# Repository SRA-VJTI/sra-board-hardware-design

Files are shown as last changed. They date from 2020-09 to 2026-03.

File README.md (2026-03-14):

<!-- PROJECT LOGO -->

[][stars-url]
[][forks-url]
[][issues-url]
[][license-url]

<br/>

<p align="center">
  <a href="https://github.com/SRA-VJTI/sraboard-hardware-design">
    
  </a>

  <h3 align="center">SRA Development Board</h3>
  <p align="center">
    ESP32-based Development Board
    <br />
    <a href="./sra_dev_board_2026">KiCAD</a>
    ·
    <a href="./gerber_sra_dev_board">Gerber</a>
    ·
    <a href="./documentation/images/board_images/front.png">Images</a>
    ·
    <a href="./3d_models/sra_board_model/sra_dev_board_2026.step">3D Model</a>
  </p>

# SRA Board 2026

The SRA board is a development board based on ESP32 with on-board peripherals like a programmable LED matrix, switches, sensor ports for Line Sensor Array and MPU-6050, protection circuit for over-current and reverse voltage, and motor drivers.

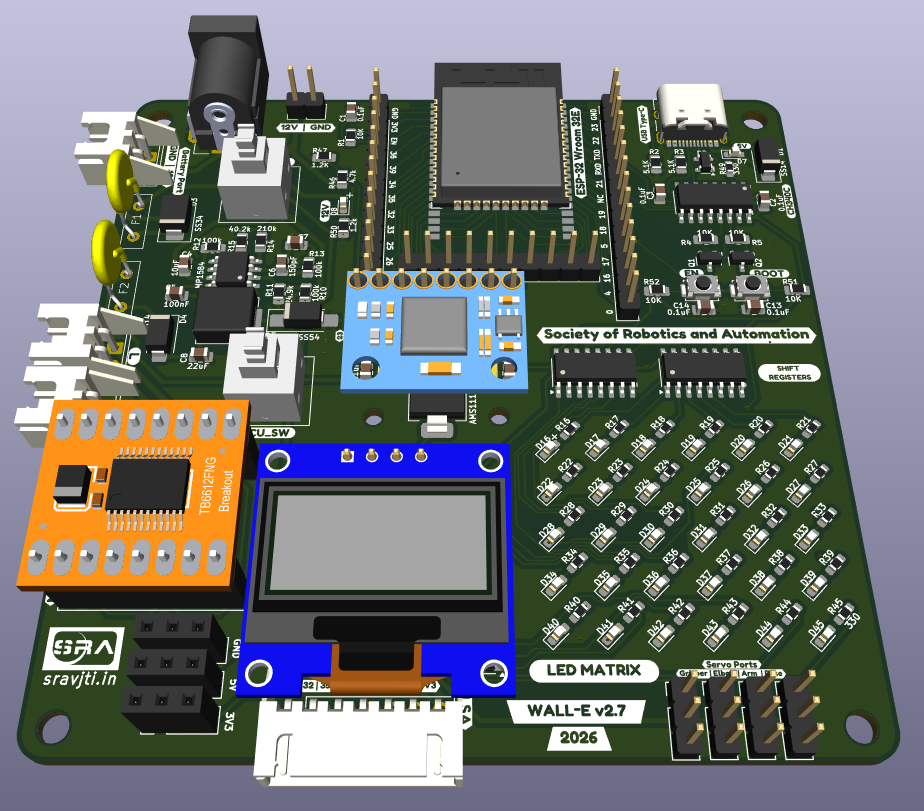
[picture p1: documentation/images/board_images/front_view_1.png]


## Table of Contents

- [SRA Board 2026](#sra-board-2026)
  - [Table of Contents](#table-of-contents)
  - [Board Images](#board-images)
  - [About the Project](#about-the-project)
  - [Getting Started with a Development Board](#getting-started-with-a-development-board)
  - [Notable problems in the current SRA Board](#notable-problems-in-the-current-sra-board)
  - [Improvements Suggested for Future Iterations](#improvements-suggested-for-future-iterations)
  - [Potential Future Enhancements](#potential-future-enhancements)
  - [3D Models](#3d-models)
  - [Milestones](#milestones)
  - [Contributors](#contributors)
  - [Acknowledgements and Resources](#acknowledgements-and-resources)
  - [License](#license)

## Board Images

- **Frontside**
<p align="center">
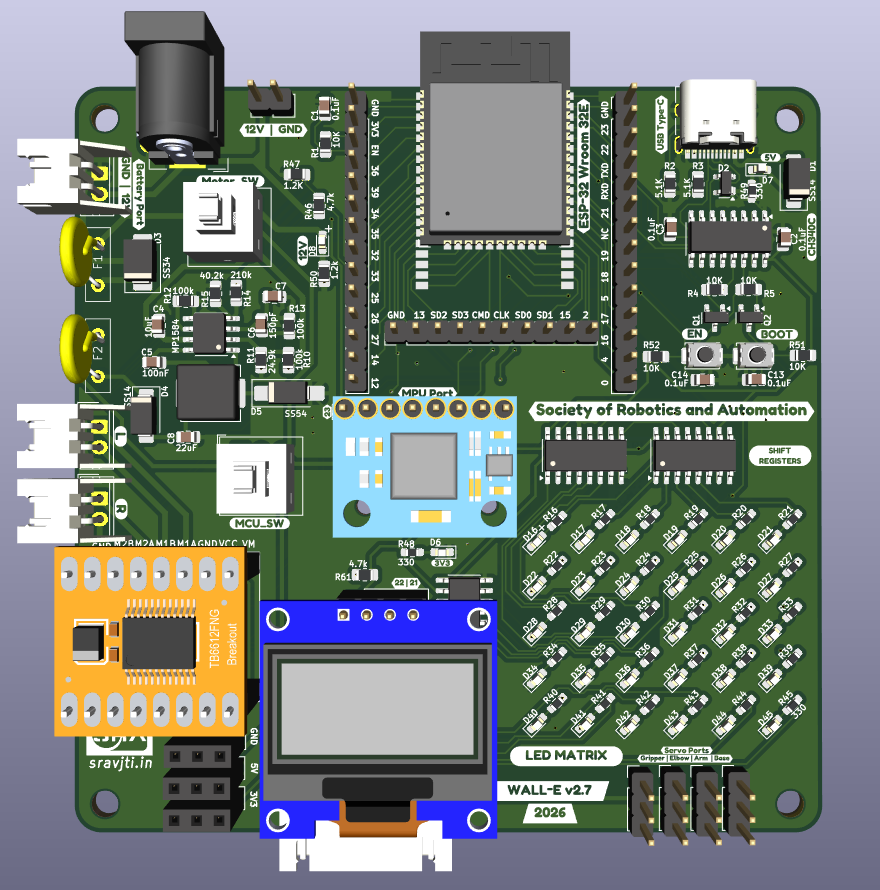
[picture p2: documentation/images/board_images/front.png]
  
</p>

- **Backside**
<p align="center">
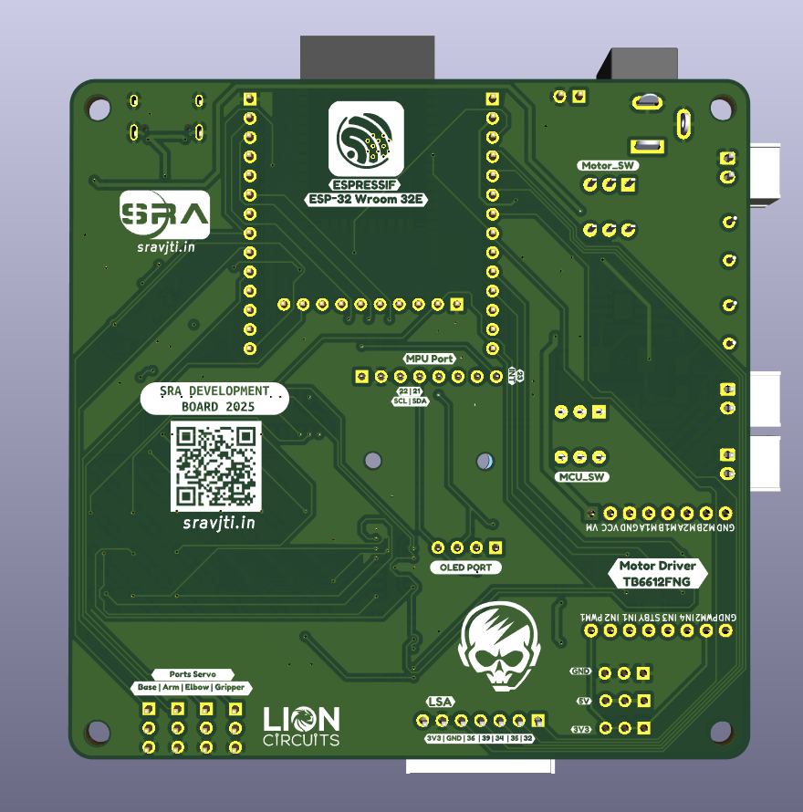
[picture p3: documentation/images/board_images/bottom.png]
  
</p>

## About the Project

- This development board is used for the [Wall-E](https://github.com/SRA-VJTI/Wall-E) and [MARIO](https://github.com/SRA-VJTI/MARIO) workshops conducted by [SRA](https://github.com/SRA-VJTI).
- Designed using KiCAD. The schematic and board files are [here](./sra_dev_board_2026).
- Resources for [previous work](https://github.com/SRA-VJTI/sra-board-hardware-design/tree/v2.5). For more details of the SRA board 2024, checkout this [link](https://github.com/SRA-VJTI/sra-board-hardware-design/releases/tag/v2.4).
- The SRA board 2023 images can be found [here](https://github.com/SRA-VJTI/sra-board-hardware-design/tree/v2.3/documentation/images).
- Older versions of the board and miscellaneous designs can be found [here](https://github.com/SRA-VJTI/PCB-Schematics-and-Layouts).

## Getting Started with a Development Board

<p align="center">
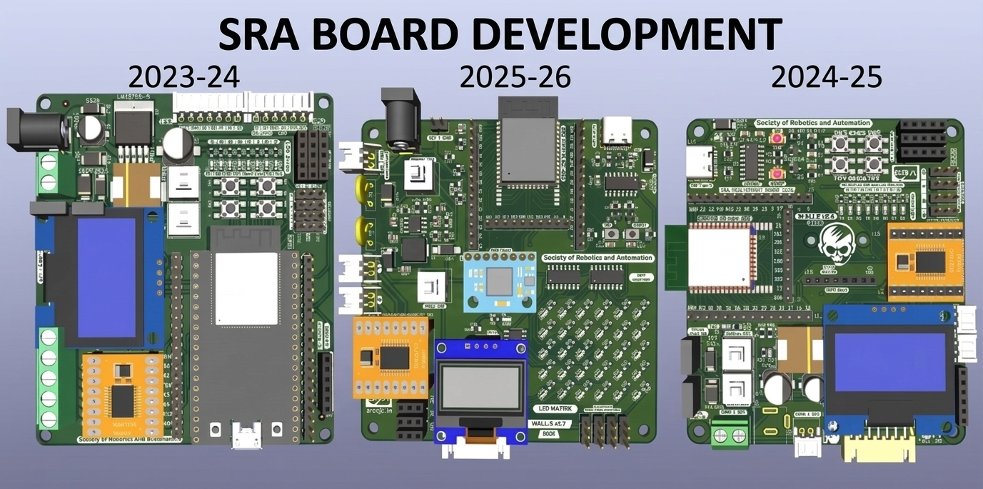
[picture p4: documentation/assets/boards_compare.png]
  
</p>

In general, every development board has the following basic features:

- ### Power Supply Unit
  - Microcontrollers (MCUs) usually run on 3.3V or 5V logic supply voltage while input to a development board is normally 12V for motor and driving/controlling peripheral devices.
  - So, in order to have a single input source, a _power_ section which inter converts this 12V to standard levels like 5V & 3.3V for MCU and sensors is present.This is achieved using a step-down [buck regulator](https://www.youtube.com/watch?v=m8rK9gU30v4).
  - Buck Regulator IC [MP1584](./datasheets/MP1584_buck.pdf) is used in the current SRA Board 2026 for stepping down the voltage from 12V to 5V DC. This 5V is further regulated to 3.3V using LDO IC [AMS1117-3.3](./datasheets/ams1117_ldo.pdf). The MP1584 is a more compact and efficient alternative compared to the previous LM2576-S.
  - The previous edition of the SRA board (2025) used the [LM2576-S-5](./datasheets/lm2576_buck_regulator.pdf) buck regulator, while earlier editions used the LM7805 linear voltage regulator for stepping down from 12V to 5V.
  - The older editions of the SRA board used the LD33 linear voltage regulator for converting 5V to 3.3V at the sensor port.

- ### Motor Driver
  - Motors usually run on 12V and MCU output is generally 5V/3.3V. So, an external motor driver circuitry is required to control motors according to the MCU input.
  - The current and previous editions of SRA board use the [TB6612FNG](./datasheets/TB6612FNG_motor_driver.pdf) Motor Driver, which is a MOS-based H-Bridge motor driver.
  - The older editions of SRA Board used the L298N IC for motor-control, which is a BJT-based H-Bridge motor driver.

- ### Sensor Port
  - According to the external sensor types, usually development boards have onboard sensor ports where the sensors can be connected easily. [LSA - Line Sensor Array]() and [MPU- Motion Processing Unit]() have on-board connection ports.
  - The current edition uses easily available and efficient [JST XH connectors](https://en.wikipedia.org/wiki/JST_connector).
  - Previous versions used bulky [FRC connectors](<https://www.sunrom.com/c/frc-idc-flat-cable-box-header#:~:text=FRC%20(Flat%20Ribon%20Cable)%20are,from%206%20to%2064%20pins.>)

- ### Protection against [Reverse Voltage](https://www.google.com/url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)
  - The SRA Boards use diodes for reverse voltage protection in the power-line.
  - 12V Motor line and power regulated line have been separated with [SS34](./datasheets/ss34_3A_schottky_diode.pdf) and [SS54](./datasheets/ss24_2A_schottky_diode.pdf) schottky diodes respectively.

- ### Protection against [Over Current](https://www.baypower.com/blog/what-is-overcurrent-protection/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,of%20a%20piece%20of%20equipment.)
  - Earlier, for the overcurrent protection of MCU and motor driver circuit, bulky glass fuses of 300mA and 3A were used respectively. After breakdown, they used to be replaced.
  - In the recent versions of the board, these were replaced with compact, PTC Resettable Fuses.
  - On 12V line - [RXEF160](./datasheets/RUEF160_3,2A_trip_ptc_fuse.pdf) : 1.6A hold current; 3.2A trip current Fuse was used.
  - On 5V line - [RXEF160](./datasheets/RXEF050_1A_trip_ptc_fuse.pdf) : 0.5A hold current; 1A trip current Fuse was used.
- ### Programmable Switches and LEDs
  - Every development board should have some programmable switches and LEDs for testing, control and debugging purposes.
  - The current SRA Board 2026 features a 6x5 LED matrix (30 LEDs total) controlled via shift registers, which provides enhanced debugging capabilities and expressive visual feedback while reducing GPIO usage compared to discrete LEDs.
  - The previous edition (2025) had an array of 8 programmable discrete LEDs and switches.
  - The earlier editions had fewer programmable switches and LEDs for testing and control purposes.

- ### Power Switch
  - All versions have a power switch for the motor driver, using which power supply to the motor driver can be toggled. Similarly, there was a switch for the ESP32 MCU.

> Now that we covered basics of development boards, let us talk about the changes made in the new design.

## Changes IN SRA Board Over the years from 2024-2026

| Feature | SRA Board 2024 | SRA Board 2025 | SRA Board 2026 |
| :---: | :---: | :---: | :---: |
| 12V to 5V | LM2576-S Buck Converter | LM2576-S Buck Converter | MP1584 Buck Converter |
|  Reverse Voltage Protection | Diodes | Diodes | Diodes |
| Line Sensing Arrays (LSA) | IR Sensors | IR Sensors | IR Sensors |
| Number of LSA Sensors | 5 | 5 | 5 |
| Motor Driver | TB6612FNG | TB6612FNG | TB6612FNG |
| Stepper Motor Driver | - | - | - |
| No. of DC Motor Channels | 2 | 2 | 2 |
| No. of Stepper Motor Channels | 0 | 0 | 0 |
| No. of Switches | 2 | 2 | 2 |
| No. of LEDs | 8 | 8 | 6x5 LED Matrix (via Shift Registers) |
| Over Current Protection | PTC Resettable Fuses | PTC Resettable Fuses | PTC Resettable Fuses |
| Sensor Port Connectors | JST Connectors | JST Connectors | JST Connectors |
| Component Type and Board Size | SMD(Surface Mount Device), Smaller | SMD(Surface Mount Device), Smaller |  SMD(Surface Mount Device), Smaller  |
| ESP32 Module | Not Integrated | Mounted and Soldered to PCB | Mounted and Soldered to PCB |
| Flashing Port | Micro USB | Type-C | Type-C |

- ### **Compatiblity of SRA Board with Battery [3- 3.3V 2500mAh Batteries](https://robu.in/product/bak-nmc-18650-2500mah-8c-lithium-ion-battery/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)**
  - The SRA Board is compatible with **3-cell (3S) Lithium-ion battery packs** which use an external **[BMS (Battery Management System)](https://robu.in/product/3s-10a-12v-18650-lithium-battery-charger-board-protection-module/)**.
  - The BMS helps maintain safe operating voltages and disconnects the battery when the voltage drops below a safe limit.
  - It also ensures balanced charging and discharging of the three cells, improving the overall health and lifetime of the battery pack.

- ### **7805 (5V linear regulator) to [LM2576/96 Buck Convertor](https://www.youtube.com/watch?v=m8rK9gU30v4)**
  - The higher efficiency, output current capability and reliability of LM2576/96 were the primary reasons for this change.
  - The efficiency of LM2576 can reach up to **~92%**, which is significantly better than the 7805 linear regulator.
  - The LM2576 can provide currents up to **3A**, allowing peripherals such as the MARIO workshop manipulator to be powered using the onboard regulator.

- ### **LD33 (3.3V) to [AMS1117](http://www.advanced-monolithic.com/pdf/ams1117.pdf)**:
  - Older editions used the **LD33 IC** to step down from 5V to 3.3V.
  - This was later replaced with the **AMS1117-3.3 LDO**, which is more compact and widely used for stable 3.3V regulation.
  - (_AMS1117 is also used on the ESP32-DevKitC V4 module._)

- ### **Reverse voltage protection: Diodes to P-MOSFET**
  - Diodes placed in series with the power line introduce voltage drop and power loss compared to a **P-MOSFET based protection circuit**.
  - Due to the higher current requirements of the motors, managing diode size and current rating became difficult.
  - Therefore, earlier versions used a **P-MOSFET based reverse polarity protection circuit**, which is more efficient and can handle higher currents.
  - In the current edition, **SMD Schottky diodes** are used, making size and rating less of an issue.

- ### **Component Type and Board Size**:
  - In the previous editions, THT/PTH (Through-Hole) components were used, which occupied more board area and increased in size with higher power ratings.
  - In the current edition, the design adopts a more compact SMD-based layout. The LM2576 buck converter has been replaced with the smaller MP1584 regulator, and the discrete LED array has been replaced with a 6×5 LED matrix driven using shift registers.
  - Current Board Dimensions: **90mm x 90mm**

- ### **L298N vs [TB6612FNG](https://dronebotworkshop.com/tb6612fng-h-bridge/)**
  - L298N is a BJT-based H-bridge motor driver but it is less efficient as compared to the new MOS-based TB6612FNG.
  - The detailed comparison is shown below. As you can see the efficiency of TB6612FNG can reach up to 91-95% which is significantly higher than the 40-70% efficiency of L298N.
  - The only drawback of TB6612FNG is the less continuous current which is equal to 1.2A.
    <p align="center">
        
    </p>

- ### **LED System**

  - Earlier versions of the board used a set of discrete programmable LEDs for debugging and status indication. In the SRA Board 2026, this has been replaced with a **6×5 LED matrix driven using shift registers**.  
  - This significantly reduces GPIO usage while allowing more flexible visual debugging and status indication patterns.

## Notable problems in the current SRA Board

- ### **Buck Converter Stability Issue (MP1584)**
  - The SRA Board 2026 uses the **MP1584 buck converter** to step down 12V to 5V.
  - While the device allowed a significant reduction in the power section size compared to LM2576, irregular behaviour was observed under **higher load conditions**.
  - During heavy load scenarios involving motors and other peripherals, the **5V rail occasionally showed instability**, which may affect the overall system reliability.

- ### **USB Type-C Connector Mechanical Strength Issue**
  - The board currently uses a **16-pin USB Type-C connector** for programming and power.
  - In practical usage, the connector was found to be **mechanically weak**, and in some cases it could loosen or detach from the PCB after repeated cable insertion or mechanical stress.

- ### **Power Switch Issue**
  - There are two dpdt power toggle switch used on board. One to toggle the supply of 12v to the whole board and one to toggle the supply of 5v to the logic circuit.
  - Instead it should have been toggling 12v supply to the motors and toggling 12v supply to the whole board.

## Improvements Suggested for Future Iterations

Based on the current design of the SRA Board 2026, the following improvements are recommended for future iterations:

- **Replace MP1584 with TPS562202**: The TPS562202 offers improved reliability and enhanced long-term robustness compared to the current MP1584 buck converter. This component provides better thermal performance and more stable regulation across varying load conditions.

- **Upgrade to USB-C 6P Connector**: Replace the current Type-C connector with a robust USB-C 6P connector configuration. This simplifies soldering procedures, improves mechanical strength, and enhances durability during repeated connection cycles.

- **Add Unconnected UART Solder Pads (RX, TX)**: Incorporate unconnected solder pads for UART receive and transmit lines on the PCB. This allows the board to optionally function as a USB-to-TTL interface, extending its utility beyond standalone development applications.

## Potential Future Enhancements

The following experimental features and enhancements are being considered for future versions of the SRA Board but are not yet integrated into the 2026 iteration:

- **Onboard IMU Integration**: Direct integration of an Inertial Measurement Unit (IMU) for advanced motion sensing applications, eliminating the need for external MPU6050 connections.

- **Camera FFC/FPC Connector**: Addition of a Flat Flex Cable (FFC) or Flexible Printed Circuit (FPC) connector to support camera modules, enabling vision-based robotics projects and computer vision applications.

- **Integrated Motor Driver**: Direct onboarding of motor driver circuits instead of requiring external TB6612FNG modules, reducing component count and improving form factor.

- **CH340 to CP2102 Upgrade**: Replacing the CH340 USB-to-UART bridge with CP2102 for improved reliability, driver support across multiple operating systems, and better stability in industrial environments.

These enhancements represent opportunities for evolution of the platform and will be explored as future iterations of the board are developed.

## 3D Models

1. The complete 3D model (.step) file of [SRA Board 2026](./3d_models/sra_board_model/sra_dev_board_2026.step)
2. The 3D models of motor driver, LEDs, ESP32 etc.: [3d models of other components](./3d_models/)

<!-- Milestone -->

## Milestones

- [x] Designing of the prototype board
- [x] Modular testing of the circuit
- [x] Testing of prototype board
- [x] Final version
- [x] Making the board Battery Compatible
- [x] Onboard ESP32 Module

<!-- CONTRIBUTORS -->

## Contributors

- [Vishal Mutha](https://github.com/Vishal-Mutha): _Designer_
- [Atharva Atre](https://github.com/AtharvaAtre): _Mentor_
<!-- ACKNOWLEDGEMENTS AND REFERENCES -->

## Acknowledgements and Resources

- Previous Edition: [SRA Board 2025](https://github.com/SRA-VJTI/sra-board-hardware-design/releases/tag/v2.5)
- [KiCAD Tutorials](https://www.youtube.com/playlist?list=PL3bNyZYHcRSUhUXUt51W6nKvxx2ORvUQB)
- [README Template](https://github.com/roshanlam/ReadMeTemplate) by [roshanlam](https://github.com/roshanlam)

## License

- Distributed under the [MIT License](https://github.com/SRA-VJTI/sraboard-hardware-design/blob/master/LICENSE).

[forks-shield]: https://img.shields.io/github/forks/SRA-VJTI/sra-board-hardware-design
[forks-url]: https://github.com/SRA-VJTI/sra-board-hardware-design/network/members
[stars-shield]: https://img.shields.io/github/stars/SRA-VJTI/sra-board-hardware-design
[stars-url]: https://github.com/SRA-VJTI/sra-board-hardware-design/stargazers
[issues-shield]: https://img.shields.io/github/issues/SRA-VJTI/sra-board-hardware-design
[issues-url]: https://github.com/SRA-VJTI/sra-board-hardware-design/issues
[license-shield]: https://img.shields.io/github/license/SRA-VJTI/sra-board-hardware-design
[license-url]: https://github.com/SRA-VJTI/sra-board-hardware-design/blob/master/LICENSE

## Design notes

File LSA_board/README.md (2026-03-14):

## LSA - Line Sensor Array

### Table of Contents
* [Overview](#overview)
* [Features](#features)
* [Components of LSA](#components-of-lsa)
* [Function of Components](#function-of-components)
	* [LED](#function-of-components)
	* [PhotoDiode](#function-of-components)
	* [IC LM324](#function-of-components)
	* [Resistors](#function-of-components)
* [Connections](#connections)
* [Working Principle](#working-principle)
* [Appplications](#applications)
* [Scope of Improvement](#scope-of-improvement)

### Overview
- The Line Sensor Array(LSA) is used to detect the white/black lined surface and it sends this data to the microcontroller ESP-32. Analyzing and processing the data received by the microcontroller ESP-32, the purpose of line following is achieved.

- Physical PCB
<p align="center">
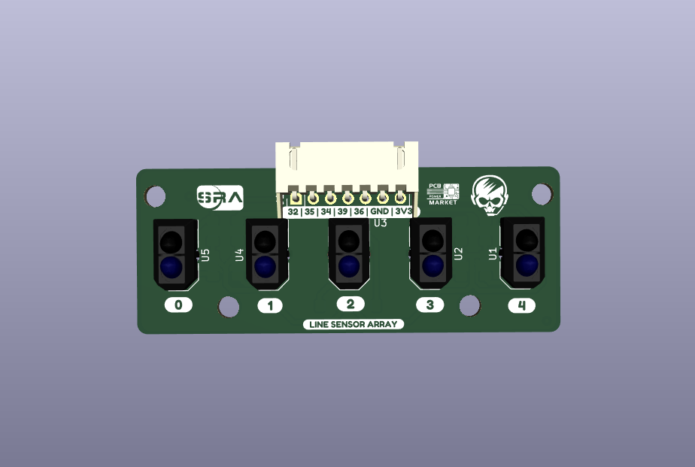
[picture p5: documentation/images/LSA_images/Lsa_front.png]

</p>

- PCB Backside
<p align="center">
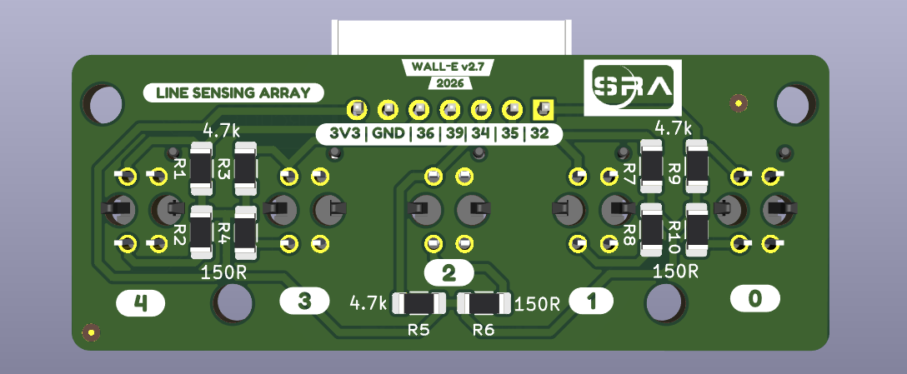
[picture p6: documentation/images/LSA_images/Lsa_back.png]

</p>

### Features
* Components used are readily available.
* Easy connections for output signals.
* Compact enough to fit into any project.
* Distinguished trace widths for Signal and Power Routes.

### Components of LSA
| Component | Description | Quantity |
| --- | --- | --- |
| Infrared Emmitter | Emits infrared light |  5 |
| PhotoTransistor  | Absorbs light |  5 |
| Resistors | Limit Current |  10 |
|JST Connector | Connect PCB with other circuits|1|

### Function of Components
- **Infrared Emmitter**
	- The specific Infrared Emmitter emit infrared light which is incident on the surface and some of it is absorbed by the surface. The voltage source for the Infrared Emmitter to emit is VCC.

- **PhotoTransistor**
	- Based upon the reflectivity coefficient of the surface( generally less than 1), the remaining light reflected from the surface is captured by the Photodiodes. Infrared Emmitter and complimentary phototransistor are used to efficiently detect the surface (white/black line). The amount of light received is directly proportional to the current generated by it. More the light, more the current, more the reading.

- **Resistors**
	- Now to limit the current and thus to protect the LEDs, PhotoDiodes current limiting resistors are used.

### Connections
To connect LSA with the SRA Board, connect the JST connector in the following way:
<p align="center">
 
</p>

### Working Principle
- LSA works on the principle of reflectivity of light for different types of surfaces.
	- Black Surface -> HIGH absorptivity -> LESS reflectivity
	- White Surface -> LOW absorptivity -> HIGH reflectivity
- Demonstration
<p align="center">
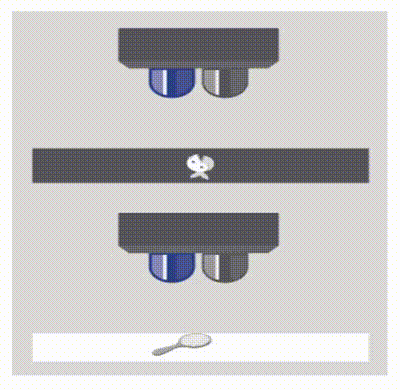
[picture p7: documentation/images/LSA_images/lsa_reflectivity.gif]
 
</p>

### Applications
* Obstacle detection on a clear path.
* Line Following.
* Distinguish Colours on a path.

### Scope of Improvement
- LSA sometimes provides slightly inaccurate readings due to external light and conditions due to non uniformity of the colour of the path. Therefore, LSA has low accuracy. Hence LSA should be kept close to the ground.
- As of now only white and black surfaces are being mapped. Given accurate sensors and proper mapping we can map LSA for any range of RGB colours.

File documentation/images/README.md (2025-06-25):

# SRA Board 2022: Images

## Schematic image

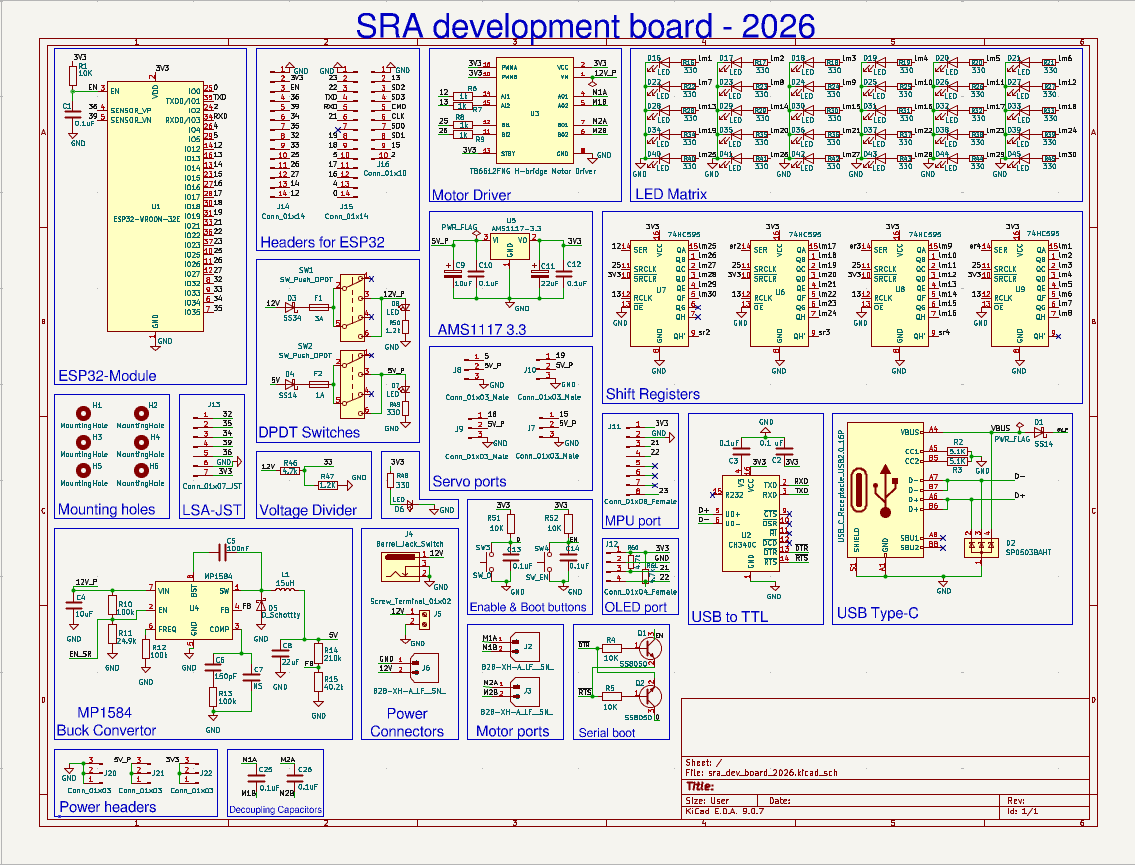
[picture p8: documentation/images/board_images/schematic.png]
Schematic


## Top Silkscreen

<p align="center">
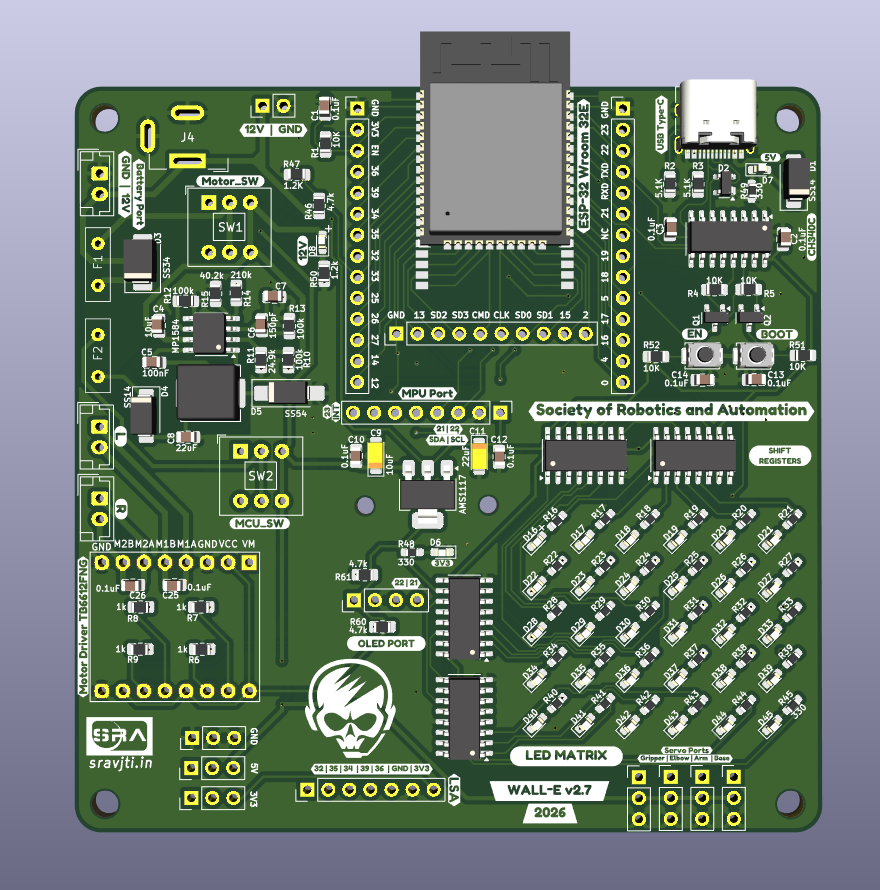
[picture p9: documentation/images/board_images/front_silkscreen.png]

</p>

## Bottom Silkscreen

<p align="center">
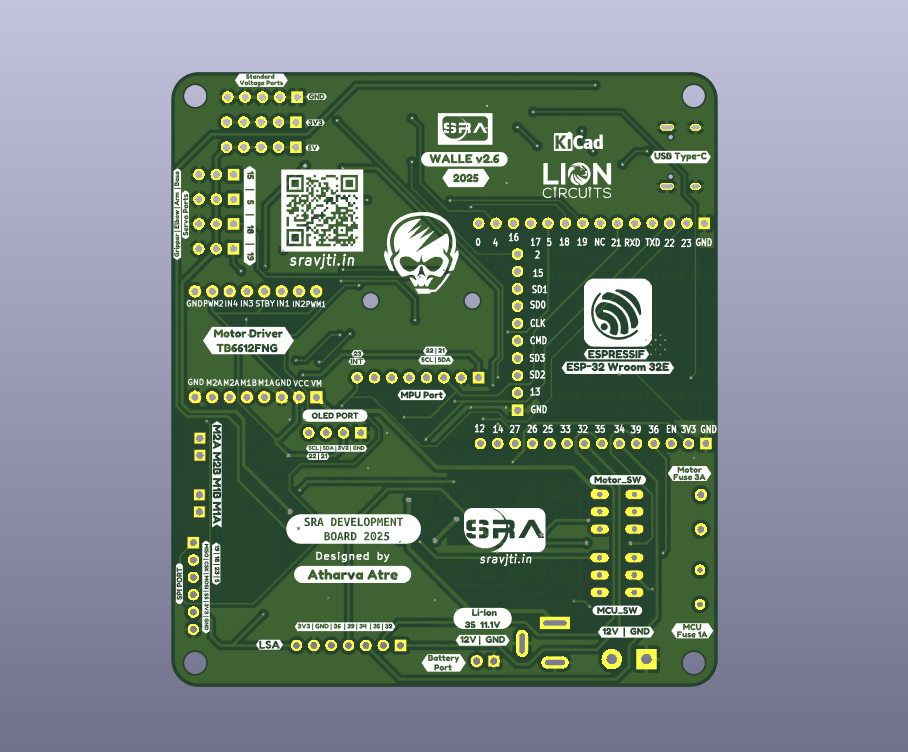
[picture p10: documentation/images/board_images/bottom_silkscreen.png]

</p>

## Top Layer

<p align="center">
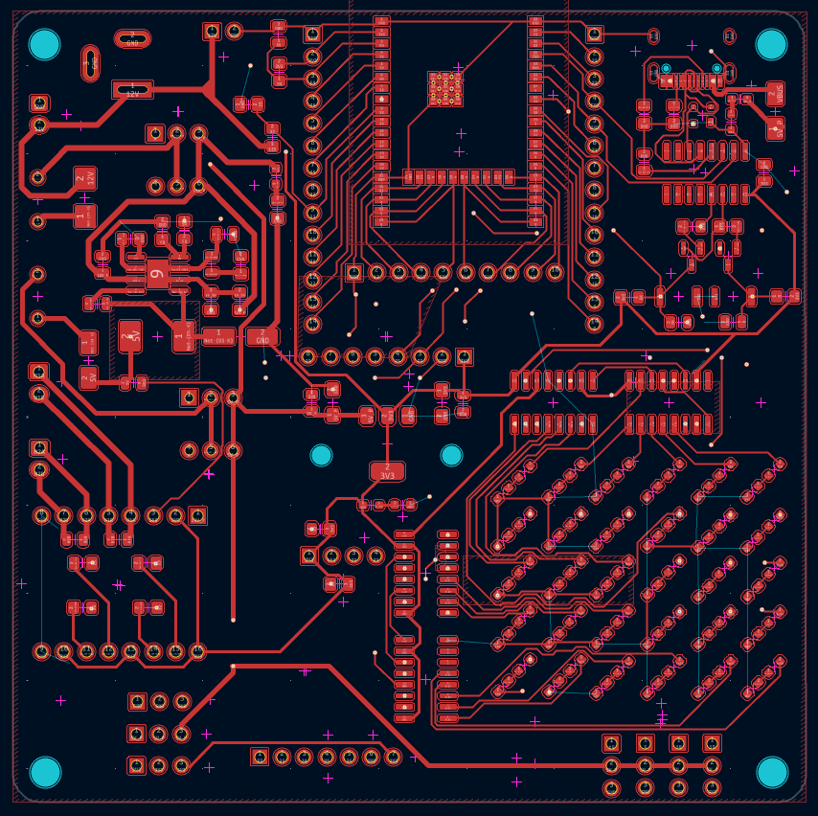
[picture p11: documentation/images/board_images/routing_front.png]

</p>

## Bottom Layer

<p align="center">
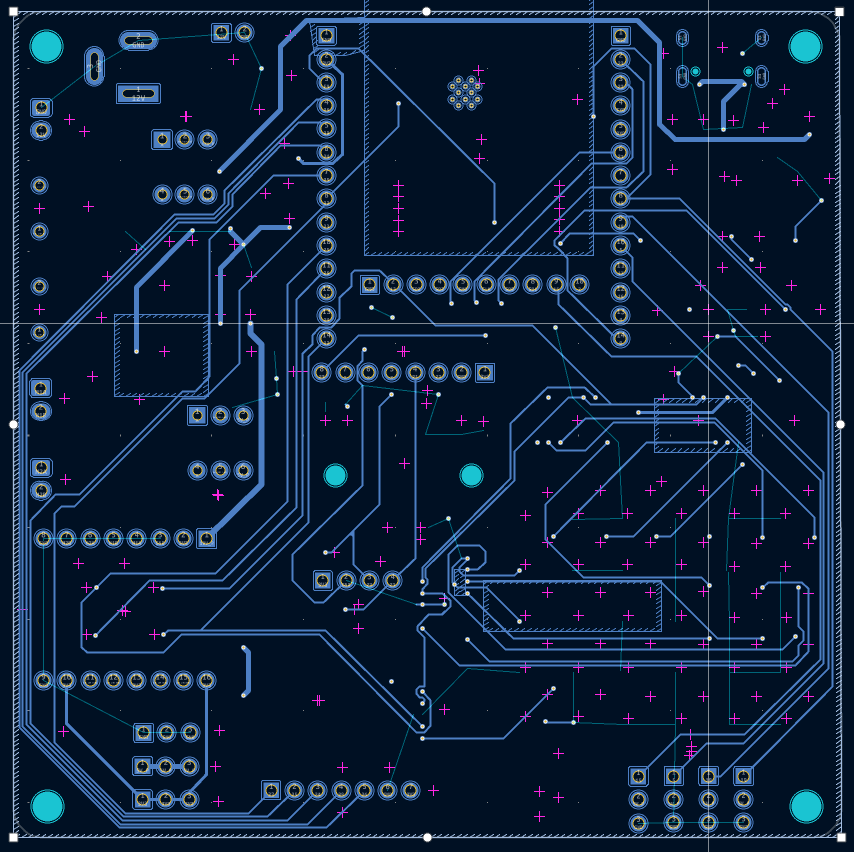
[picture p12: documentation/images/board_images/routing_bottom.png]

</p>

## Both Layers

<p align="center">
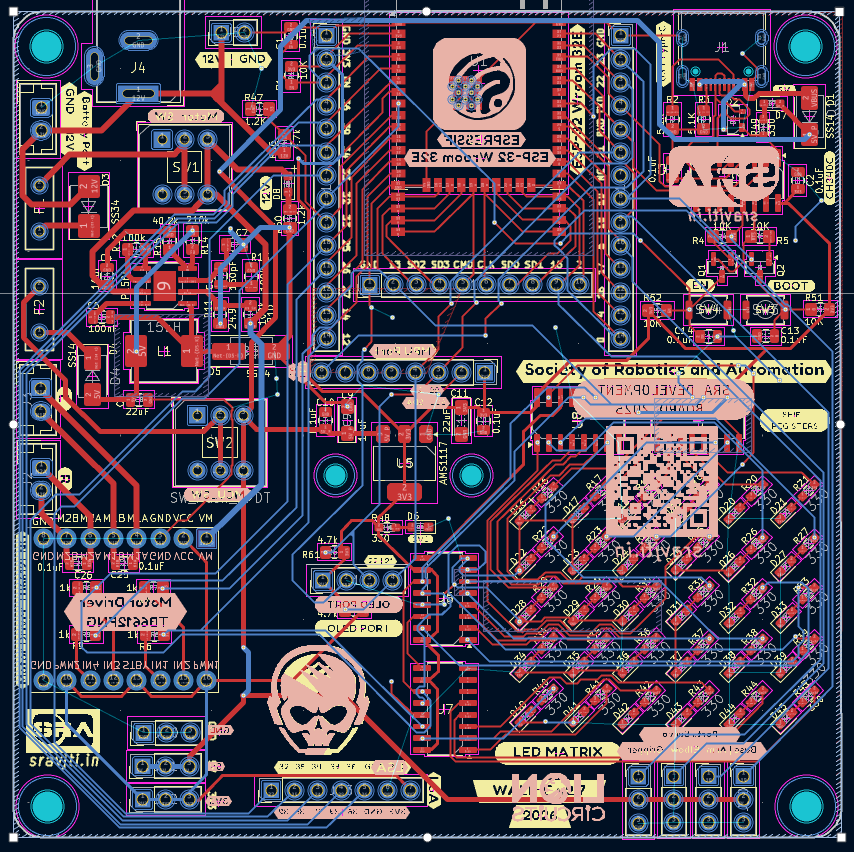
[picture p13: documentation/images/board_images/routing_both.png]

</p>

## Front

<p align="center">

</p>

<p align="center">
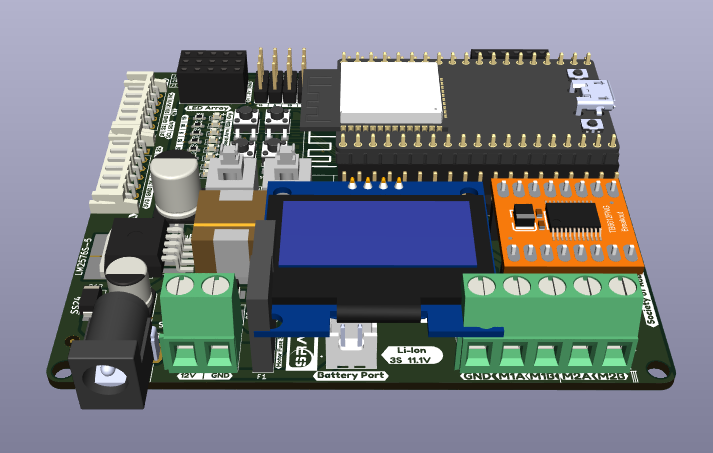
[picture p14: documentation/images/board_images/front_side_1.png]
front_side_1
    
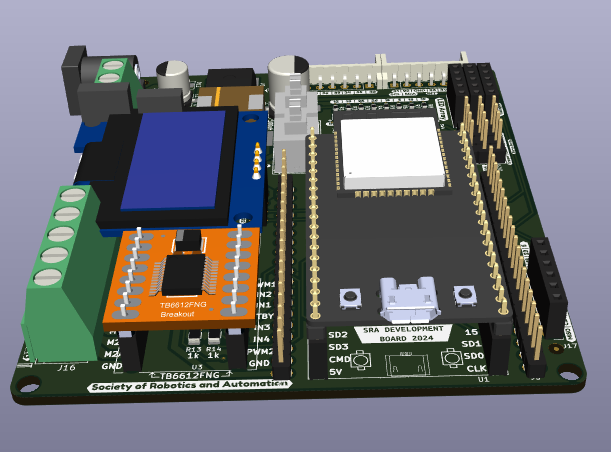
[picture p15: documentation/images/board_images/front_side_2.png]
front_side_2
    
</div> 

### 3d View

<p align="center">
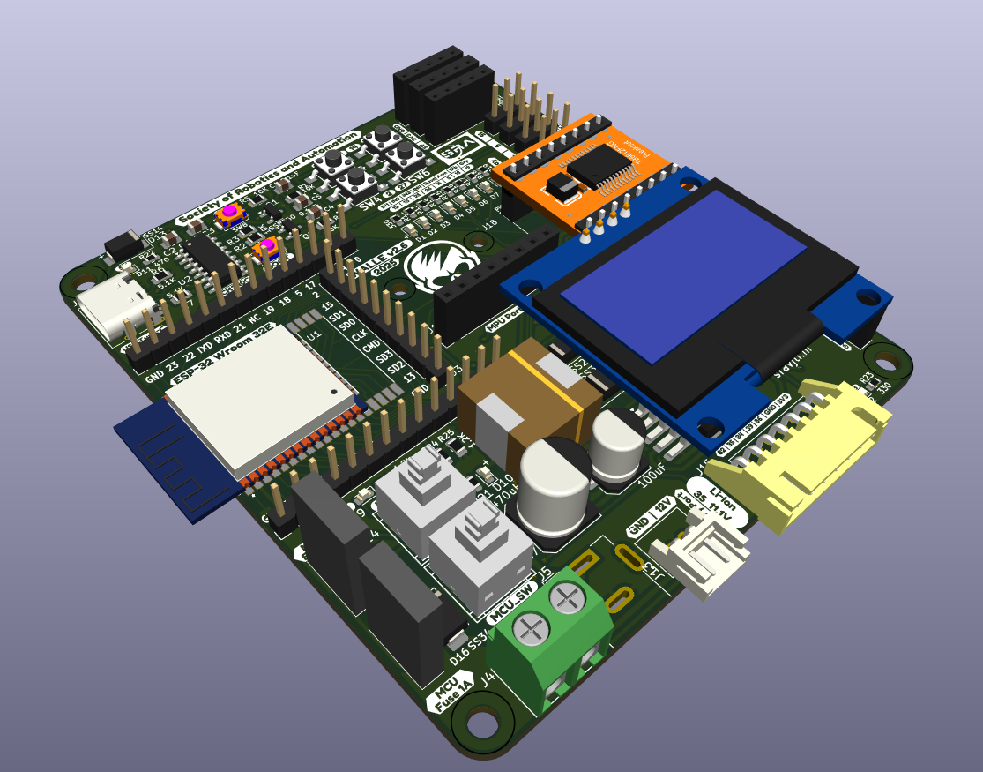
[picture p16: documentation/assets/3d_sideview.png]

</p>

### Bottom View

<p align="center">

</p>

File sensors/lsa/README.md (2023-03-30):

## LSA - Line Sensor Array

### Table of Contents
* [Overview](#overview)
* [Features](#features)
* [Components of LSA](#components-of-lsa)
* [Function of Components](#function-of-components)
	* [LED](#function-of-components)
	* [PhotoDiode](#function-of-components)
	* [IC LM324](#function-of-components)
	* [Resistors](#function-of-components)
* [Connections](#connections)
* [Working Principle](#working-principle)
* [Appplications](#applications)
* [Scope of Improvement](#scope-of-improvement)

### Overview
- The Line Sensor Array(LSA) is used to detect the white/black lined surface and it sends this data to the microcontroller ESP-32. Analyzing and processing the data received by the microcontroller ESP-32, the purpose of line following is achieved.

- Physical PCB
<p align="center">

</p>

<p align="center">
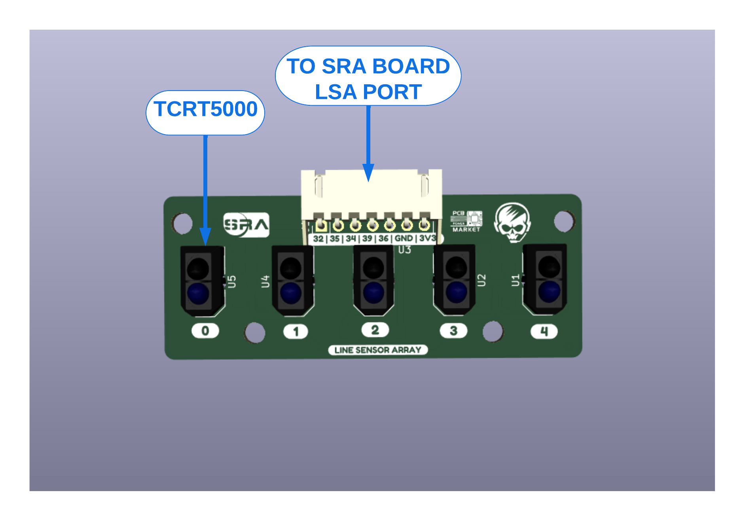
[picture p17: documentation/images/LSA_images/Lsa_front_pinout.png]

</p>

- PCB Backside
<p align="center">

</p>

<p align="center">
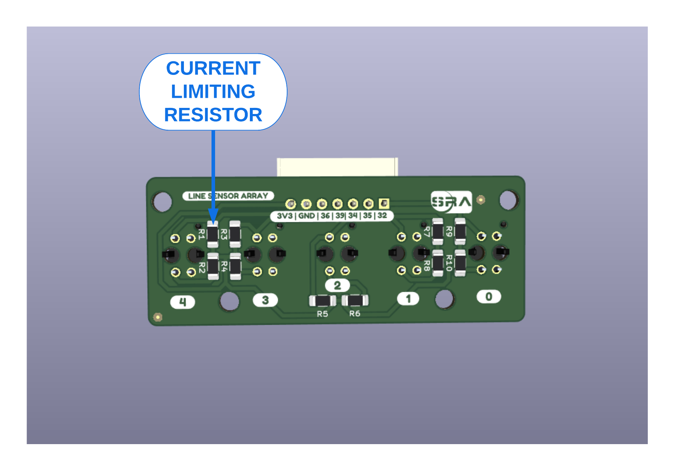
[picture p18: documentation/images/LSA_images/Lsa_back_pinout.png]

</p>

### Features
* Components used are readily available.
* Easy connections for output signals.
* Compact enough to fit into any project.
* Distinguished trace widths for Signal and Power Routes.

### Components of LSA
| Component | Description | Quantity |
| --- | --- | --- |
| Infrared Emmitter | Emits infrared light |  5 |
| PhotoTransistor  | Absorbs light |  5 |
| Resistors | Limit Current |  10 |
|JST Connector | Connect PCB with other circuits|1|

### Function of Components
- **Infrared Emmitter**
	- The specific Infrared Emmitter emit infrared light which is incident on the surface and some of it is absorbed by the surface. The voltage source for the Infrared Emmitter to emit is VCC.

- **PhotoTransistor**
	- Based upon the reflectivity coefficient of the surface( generally less than 1), the remaining light reflected from the surface is captured by the Photodiodes. Infrared Emmitter and complimentary phototransistor are used to efficiently detect the surface (white/black line). The amount of light received is directly proportional to the current generated by it. More the light, more the current, more the reading.

- **Resistors**
	- Now to limit the current and thus to protect the LEDs, PhotoDiodes current limiting resistors are used.

### Connections
To connect LSA with the SRA Board, connect the JST connector in the following way:
<p align="center">
 
</p>

### Working Principle
- LSA works on the principle of reflectivity of light for different types of surfaces.
	- Black Surface -> HIGH absorptivity -> LESS reflectivity
	- White Surface -> LOW absorptivity -> HIGH reflectivity
- Demonstration
<p align="center">
 
</p>

### Applications
* Obstacle detection on a clear path.
* Line Following.
* Distinguish Colours on a path.

### Scope of Improvement
- LSA sometimes provides slightly inaccurate readings due to external light and conditions due to non uniformity of the colour of the path. Therefore, LSA has low accuracy. Hence LSA should be kept close to the ground.
- As of now only white and black surfaces are being mapped. Given accurate sensors and proper mapping we can map LSA for any range of RGB colours.

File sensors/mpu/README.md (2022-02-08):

# TABLE OF CONTENTS
- [TABLE OF CONTENTS](#table-of-contents)
- [MPU6050](#mpu6050)
- [Connection with SRA Board](#connection-with-sra-board)
- [Inertial Measurement Unit](#inertial-measurement-unit)
- [Initialising MPU6050](#initialising-mpu6050)
  - [Gyroscope](#gyroscope)
  - [Reading Gyroscope Data](#reading-gyroscope-data)
  - [Accelerometer](#accelerometer)
  - [Reading Accelerometer Data](#reading-accelerometer-data)
  - [Accelerometer Euler Angles](#accelerometer-euler-angles)
  - [Complementary Filter](#complementary-filter)
  - [Digital Motion Processor](#digital-motion-processor-dmp)
  - [Reading Register Data](#reading-register-data)

# Connection with SRA Board
PNG image

# MPU6050
- The MPU6050 is a **6-axis/6-DOF Motion Tracking Device**.
- It is a *Micro Electro-Mechanical System (MEMS)*.
> MEMS is a technology defined as miniaturized mechanical and electro-mechanical elements (i.e., devices and structures) that are made using the techniques of microfabrication.
> Their dimensions can range from one micron to several millimeters.
- The 6050 has both a 3-axis Accelerometer and 3-axis Gyroscope integrated on a single chip.
- It is a commonly used chip that combines a MEMS gyroscope and a MEMS accelerometer and uses a standard I2C bus for data transmission
- The system processor is an I2C master to the MPU6050 (default address is 0x68 but can be changed to 0x69)
- The MPU6050 can also act as an I2C master and directly accept inputs from an external compass
- This is 3.3V device and hence is safe to connect to ESP32 pins directly.

MPU6050

To give you some context:
> A Gyroscope is a device that measures the rate of change of angular position, aka the rotational velocity, over time in all 3 axes.

>An accelerometer is a tool that measures acceleration in its own instantaneous rest frame(e.g. an accelerometer at rest on the surface of the Earth will measure an acceleration due to Earth's gravity, straight upwards of g ≈ 9.81 m/s<sup>2</sup> and will measure zero acceleration when in freefall)

- When the 6050 is used, it returns 6 values; 3 from the accelerometer and the other 3 from the gyroscope.

# Inertial Measurement Unit

- These are small devices indicating changing orientation in smartphones, video game remotes, quadcopters, etc.
- The IMU has both a gyroscope which measures angular rate and an accelerometer which measures linear acceleration, and/or compasses (magnetometers)
- The number of sensor inputs in an IMU are referred to as ‘DoF’ (Degrees of Freedom), so a chip with a 3-axis gyroscope and a 3-axis accelerometer would be a 6-DOF IMU.

# Contents
- MPU6050 includes **Digital Motion Processor (DMP)**, which has property to solve complex calculations.
- It also consists of a 16-bit Analog to Digital Converter(ADC) hardware. This enables it to record 3-dimension motion at the same time.
- It has **I2C bus interface** to communicate with various microcontrollers.
- The main feature is that the MPU6050 is less expensive and that it can easily combine with accelerometer and gyroscope.

### Pins

Pins

The MPU-6050 module has 8 pins,

<code>VCC</code>: Power supply pin. Connect this pin to +5V DC supply.

<code>GND</code>: Ground pin. Connect this pin to ground connection.

<code>SCL</code>: Serial Clock pin. Connect this pin to the microcontroller's SCL pin.

<code>SDA</code>: Serial Data pin. Connect this pin to the microcontroller's SDA pin.

<code>XDA</code>: Auxiliary Serial Data pin. This pin is used to connect other I2C interface enabled sensors' SDA pin to MPU-6050.

<code>XCL</code>: Auxiliary Serial Clock pin. This pin is used to connect other I2C interface enabled sensors' SCL pin to MPU-6050.

<code>AD0</code>: I2C Slave Address LSB pin. This is 0th bit in 7-bit slave address of device. If connected to VCC, then read as logic one and slave address changes.

<code>INT</code>: Interrupt digital output pin.

---------
# Working of the 6050

## Initialising MPU6050

- A sample wiring of the device to ESP32 looks as follows:



- When powered up, MPU6050 will start in SLEEP mode. To use it, we need to first disable this SLEEP mode 
- To use the I2C protocol, we send the value 0 to register PWR_MGMT_1 (0x6b)
- The procedure to do so is as follows :
   1. Send a start sequence
   2. Send the I2C address (0x68) of the MPU6050 with the R/W bit high
   3. Send the internal register number you want to write to (0x6b : PWR_MGMT_1)
   4. Send the data byte (0x00) - This will power on the device
   5. Send the stop sequence



 The data byte 0x00 sets all the bits of register 107 to 0, thus disabling SLEEP mode and CYCLE mode, and powering on the MPU-6050 



There are various terms related with the Pulse Width Modulation:- 
- **Off-Time** :- Duration of time period when the signal is low.
- **ON-Time**  :- Duration of time period when the signal is high.
- **Duty cycle** :- It is the percentage of the time period when the signal remains ON during the period of the pulse width modulation signal.
- **Period** :- It is the sum of off-time and on-time of pulse width modulation signal.

### Gyroscope

- When the gyros are rotated about any of the sense axes, the C*oriolis Effect* causes a vibration that is detected by a MEM inside MPU6050.

- The resulting signal is amplified, demodulated, and filtered to produce a voltage that is proportional to the angular rate.

-  This voltage is digitized using 16-bit ADC to sample each axis.

-  The full-scale range of output are **+/- 250, +/- 500, +/- 1000, +/- 2000.**

-  It measures the angular velocity along each axis in *degree per second* units.

### Reading Gyroscope Data

- The acceleration of the three axes, X,Y and Z, are stored in 3 pairs of registers on the MPU6050
- Each register on the MPU6050 is an 8-bit register
- In each of these pairs, one register stores the MSB (most significant bit) and the other stores the LSB (least significant bit)
- These 6 registers are [burst-read](#reading-register-data) and the 8-bit MSB and LSB bytes for each axis are combined to give a single 16-bit float
- The gyroscope has a sensitivity factor of about 131, i.e. 1 degree of rotation gives a reading of 131 units
- Therefore, the degrees of rotation are obtained by dividing the raw readings by 131 
- Euler angles are calculated by integrating raw readings of each axis over time



### Accelerometer
Tilt

Accelerometer
- The MPU6050 uses a MEMS accelerometer, which consists of stationary and movable electrodes acting as **capacitor plates**
- Acceleration along the axes deflects the movable mass. It produces change in g-forces on the moving device, which causes displacement of the movable capacitor plates.
-  This displacement of moving plate (mass) unbalances the differential capacitor, which causes a change in the capacitance, which is then detected internally by change in voltage. This in turn results in sensor output. Output amplitude is proportional to acceleration.
-  16-bit ADC is used to get digitized output.
-  The full-scale range of acceleration are **+/- 2g, +/- 4g, +/- 8g, +/- 16g.**
-  It is measured in *g (gravity force)* unit; for example when the device is placed on a flat surface, it will measure 0g on X and Y axes and +1g on Z axis.

### Reading Accelerometer Data

- The acceleration of the three axes, X,Y and Z, are stored in 3 pairs of registers on the MPU6050
- Each register on the MPU6050 is an 8-bit register
- In each of these pairs, one register stores the MSB (most significant bit) and the other stores the LSB (least significant bit)
- These 6 registers are [burst-read](#reading-register-data) and the 8-bit MSB and LSB bytes for each axis are combined to give a single 16-bit float

### Accelerometer Euler Angles 

- The roll and pitch angles are calculated from the accelerometer using the [formula](https://www.digikey.com/en/articles/using-an-accelerometer-for-inclination-sensing) below :
  


### Complementary Filter
* Since gyroscopic drift accumulates over time, it is necessary to reset the rate readings from the gyroscope at frequent intervals, so the drift can be minimised
* To do this, we combine both the gyroscope and accelerometer readings in a weighted average
* The value of alpha is determined experimentally
* [Formula](http://www.pieter-jan.com/images/equations/CompFilter_Eq.gif):



### Digital Motion Processor (DMP)
- Since the 6050 has multiple sensors, the input from these sensors can be fed into various complex algorithms that take raw data and convert it into extremely useful values(like an Inertial Navigation System as used in drones).
> Note that gyroscope and accelerometer sensor data of MPU6050 module consists of 16-bit raw data in 2’s complement form.
- These algorithms are known as Fusion algorithms since they take input from multiple sensor types. 
- The only problem is that these algorithms are:
    - hard to understand since they contain a lot of mathematics and tend to be complicated, and
    - demanding in RAM because of the amount of calculations that they require.
- This means that these algorithms are barely able to run on a relatively simple controller. 

This is where the DMP comes in.
- The MPU-6050 DMP is quite sophisticated. It supports **3D motion processing and gesture recognition algorithms**. It even reports temperature, and if you connect an external magnetometer, the DMP can also give you heading information.
- It is a motion sensing device that solve the problem mentioned above by running fusion algorithms internally.
- Hence, the SRA Board will be able to receive clean and reliable "fused" motion information from the module, instead of noisy motion data.

### Reading Register Data

* To read/receive data from a slave, the master has to first send a START condition addressing the MPU6050
* Then the master must WRITE the requested register from which the data is to be read
* After this, instead of sending a STOP condition to stop the WRITE operation and then sending a consecutive START condition to start the READ operation,
  the I2C bus provides the **repeated start** functionality, wherein instead of sending a STOP-START condition, we send only a START condition and read the
  specified number of bytes from the register.
* The procedure to do so is as follows :
  1. Send a start sequence
  2. Send the I2C address (0x68) of the MPU6050 with the R/W bit low - This writes to the device
  3. Send the Internal register address you want to read from
  4. Send a start sequence again (repeated start)
  5. Send the I2C address of the device with the R/W bit high - This reads from the device
  6. Read the number of the requested data bytes from the registers
  7. Send the stop sequence.
  6. All write and read operations (except the last read) are answered with a ACK if successful.

 



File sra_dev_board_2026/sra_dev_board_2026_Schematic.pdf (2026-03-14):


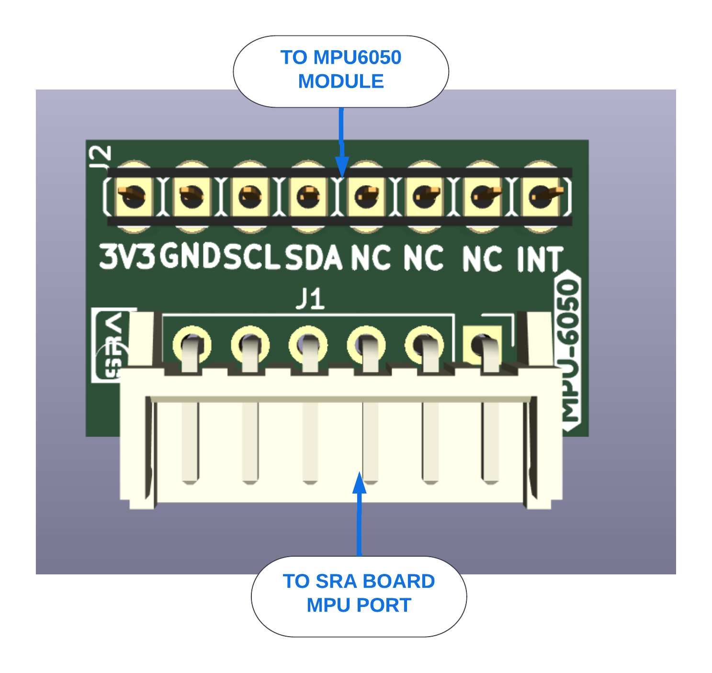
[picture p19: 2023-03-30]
documentation/images/MPU_images/Mpu_front_pinout.png

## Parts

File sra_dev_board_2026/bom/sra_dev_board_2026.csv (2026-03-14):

Reference | Qty | Value | Footprint | Datasheet
C1,C3,C10,C12,C13,C14,C25,C26 | 8 | 0.1uF | Capacitor_SMD:C_0805_2012Metric | ~
C2 | 1 | 0.1 uF | Capacitor_SMD:C_0805_2012Metric | ~
C4 | 1 | 10uF | Capacitor_SMD:C_0805_2012Metric | ~
C5 | 1 | 100nF | Capacitor_SMD:C_0805_2012Metric | ~
C6 | 1 | 150pF | Capacitor_SMD:C_0805_2012Metric | ~
C7 | 1 | NS | Capacitor_SMD:C_0805_2012Metric | ~
C8 | 1 | 22uF | Capacitor_SMD:C_0805_2012Metric | ~
C9 | 1 | 10uF | Capacitor_Tantalum_SMD:CP_EIA-3216-10_Kemet-I_HandSolder | ~
C11 | 1 | 22uF | Capacitor_Tantalum_SMD:CP_EIA-3216-10_Kemet-I_HandSolder | ~
D1,D4 | 2 | SS14 | Diode_SMD:D_SMA | http://www.vishay.com/docs/88526/1n5820.pdf
D2 | 1 | SP0503BAHT | Package_TO_SOT_SMD:SOT-143 | http://www.littelfuse.com/~/media/files/littelfuse/technical%20resources/documents/data%20sheets/sp05xxba.pdf
D3 | 1 | SS34 | Diode_SMD:D_SMB | http://www.vishay.com/docs/88526/1n5820.pdf
D5 | 1 | D_Schottky | Diode_SMD:D_SMA_Handsoldering | ~
D6,D7,D8,D16,D17,D18,D19,D20,D21,D22,D23,D24,D25,D26,D27,D28,D29,D30,D31,D32,D33,D34,D35,D36,D37,D38,D39,D40,D41,D42,D43,D44,D45 | 33 | LED | LED_SMD:LED_0603_1608Metric_Pad1.05x0.95mm_HandSolder | ~
F1 | 1 | 3A | Fuse:Fuse_Littelfuse-LVR100 | ~
F2 | 1 | 1A | Fuse:Fuse_Littelfuse-LVR100 | ~
H1,H2,H3,H4 | 4 | MountingHole | MountingHole:MountingHole_3.2mm_M3 | ~
H5,H6 | 2 | MountingHole | MountingHole:MountingHole_2.1mm | ~
J1 | 1 | USB_C_Receptacle_USB2.0_16P | Connector_USB:USB_C_Receptacle_GCT_USB4105-xx-A_16P_TopMnt_Horizontal | https://www.usb.org/sites/default/files/documents/usb_type-c.zip
J2,J3,J6 | 3 | B2B-XH-A_LF__SN_ | Connector_JST:JST_EH_B2B-EH-A_1x02_P2.50mm_Vertical
J4 | 1 | Barrel_Jack_Switch | Connector_BarrelJack:BarrelJack_Wuerth_6941xx301002 | ~
J5 | 1 | Screw_Terminal_01x02 | Connector_PinHeader_2.54mm:PinHeader_1x02_P2.54mm_Vertical | ~
J7,J8,J9,J10 | 4 | Conn_01x03_Male | Connector_PinHeader_2.54mm:PinHeader_1x03_P2.54mm_Vertical | ~
J11 | 1 | Conn_01x08_Female | Connector_PinHeader_2.54mm:PinHeader_1x08_P2.54mm_Vertical | ~
J12 | 1 | Conn_01x04_Female | Connector_PinHeader_2.54mm:PinHeader_1x04_P2.54mm_Vertical | ~
J13 | 1 | Conn_01x07_JST | Connector_PinHeader_2.54mm:PinHeader_1x07_P2.54mm_Vertical | ~
J14,J15 | 2 | Conn_01x14 | Connector_PinHeader_2.54mm:PinHeader_1x14_P2.54mm_Vertical | ~
J16 | 1 | Conn_01x10 | Connector_PinHeader_2.54mm:PinHeader_1x10_P2.54mm_Vertical | ~
J20,J21,J22 | 3 | Conn_01x03 | Connector_PinHeader_2.54mm:PinHeader_1x03_P2.54mm_Vertical | ~
L1 | 1 | 15uH | Inductor_SMD:L_Sunlord_MWSA0603S | ~
Q1,Q2 | 2 | SS8050 | Package_TO_SOT_SMD:SOT-23
R1,R4,R5,R51,R52 | 5 | 10K | Resistor_SMD:R_0805_2012Metric_Pad1.20x1.40mm_HandSolder | ~
R2,R3 | 2 | 5.1K | Resistor_SMD:R_0805_2012Metric_Pad1.20x1.40mm_HandSolder | ~
R6,R7,R8,R9 | 4 | 1k | Resistor_SMD:R_0805_2012Metric_Pad1.20x1.40mm_HandSolder | ~
R10,R12,R13 | 3 | 100k | Resistor_SMD:R_0805_2012Metric_Pad1.20x1.40mm_HandSolder | ~
R11 | 1 | 24.9k | Resistor_SMD:R_0805_2012Metric_Pad1.20x1.40mm_HandSolder | ~
R14 | 1 | 210k | Resistor_SMD:R_0805_2012Metric_Pad1.20x1.40mm_HandSolder | ~
R15 | 1 | 40.2k | Resistor_SMD:R_0805_2012Metric_Pad1.20x1.40mm_HandSolder | ~
R16,R17,R18,R19,R20,R21,R22,R23,R24,R25,R26,R27,R28,R29,R30,R31,R32,R33,R34,R35,R36,R37,R38,R39,R40,R41,R42,R43,R44,R45,R48,R49 | 32 | 330R | Resistor_SMD:R_0603_1608Metric_Pad0.98x0.95mm_HandSolder | ~
R46 | 1 | 4.7k | Resistor_SMD:R_0805_2012Metric_Pad1.20x1.40mm_HandSolder | ~
R47 | 1 | 1.2K | Resistor_SMD:R_0805_2012Metric_Pad1.20x1.40mm_HandSolder | ~
R50 | 1 | 1.2k | Resistor_SMD:R_0805_2012Metric_Pad1.20x1.40mm_HandSolder | ~
R60,R61 | 2 | 4.7k | Resistor_SMD:R_0603_1608Metric_Pad0.98x0.95mm_HandSolder | ~
SW1,SW2 | 2 | SW_Push_DPDT | Button_Switch_THT:SW_Push_2P2T_Toggle_CK_PVA2OAH5xxxxxxV2 | ~
SW3 | 1 | SW_0 | Button_Switch_SMD:SW_Push_SPST_NO_Alps_SKRK | ~
SW4 | 1 | SW_EN | Button_Switch_SMD:SW_Push_SPST_NO_Alps_SKRK | ~
U1 | 1 | ESP32-WROOM-32E | RF_Module:ESP32-WROOM-32E | https://www.espressif.com/sites/default/files/documentation/esp32-wroom-32e_esp32-wroom-32ue_datasheet_en.pdf
U2 | 1 | CH340C | Package_SO:SOIC-16_3.9x9.9mm_P1.27mm | https://datasheet.lcsc.com/szlcsc/Jiangsu-Qin-Heng-CH340C_C84681.pdf
U3 | 1 | TB6612FNG H-bridge Motor Driver | user_footprints:TB6612FNG
U4 | 1 | MP1584 | Package_SO:SOIC-8-1EP_3.9x4.9mm_P1.27mm_EP2.41x3.3mm | https://www.monolithicpower.com/en/documentview/productdocument/index/version/2/document_type/Datasheet/lang/en/sku/MP1584EN-LF-Z/document_id/204/
U5 | 1 | AMS1117-3.3 | Package_TO_SOT_SMD:SOT-223-3_TabPin2 | http://www.advanced-monolithic.com/pdf/ds1117.pdf
U6,U7,U8,U9 | 4 | 74HC595 | Package_SO:SOIC-16_3.9x9.9mm_P1.27mm | http://www.ti.com/lit/ds/symlink/sn74hc595.pdf

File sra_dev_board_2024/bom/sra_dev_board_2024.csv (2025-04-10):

Source: | C:\Users\Atharva\Downloads\SRA Board 23-24\sra-board-hardware-design-2024\sra-board-hardware-design\sra_dev_board_2023-24\sra_dev_board_2023.kicad_sch
Date: | 04-05-2024 18:27:49
Tool: | Eeschema 7.0.5
Generator: | C:\7.0\bin\scripting\plugins/bom_csv_grouped_by_value_with_fp.py
Component Count: | 72
Ref | Qnty | Value | Cmp name | Footprint | Description | Vendor | DNP
5V_SW1 | 1 | SW_Push_DPDT | SW_Push_DPDT | dpdt_tht:dpdt_sw_2x03_tht | Momentary Switch, dual pole double throw
12V_SW1 | 1 | SW_Push_DPDT | SW_Push_DPDT | dpdt_tht:dpdt_sw_2x03_tht | Momentary Switch, dual pole double throw
C1 | 1 | 100uF | C_Polarized_Small | Capacitor_SMD:CP_Elec_6.3x7.7 | Polarized capacitor, small symbol
C2 | 1 | 470uF | C_Polarized_Small | Capacitor_SMD:CP_Elec_8x10 | Polarized capacitor, small symbol
C3, C4 | 2 | 0.1uF | C | Capacitor_SMD:C_0603_1608Metric | Unpolarized capacitor
C5 | 1 | 22uF | C | Capacitor_SMD:C_0603_1608Metric | Unpolarized capacitor
C6 | 1 | 10uF | C | Capacitor_SMD:C_0603_1608Metric | Unpolarized capacitor
D1, D2, D3, D4, D5, D6, D7, D8, D10, D11 | 10 | LED | LED | LED_SMD:LED_0603_1608Metric | Light emitting diode
D9, D14 | 2 | SS34 | 1N5822 | Diode_SMD:D_SMB | 40V 3A Schottky Barrier Rectifier Diode, DO-201AD
D12 | 1 | SS24 | 1N5822 | Diode_SMD:D_SMA | 40V 3A Schottky Barrier Rectifier Diode, DO-201AD
D13 | 1 | SS14 | 1N5822 | Diode_SMD:D_SMA | 40V 3A Schottky Barrier Rectifier Diode, DO-201AD
F1 | 1 | 3A | Fuse | RUEF150_3,2A_trip:RUEF160 | Fuse
F2 | 1 | 300mA | Fuse | RXEF050_1A_trip:RXEF050 | Fuse
H1, H2, H3, H4 | 4 | MountingHole | MountingHole | MountingHole:MountingHole_3.2mm_M3 | Mounting Hole without connection
J1, J5 | 2 | Conn_01x19_Male | Conn_01x19_Male | pin_header_connectors:1X19 | Generic connector, single row, 01x19, script generated (kicad-library-utils/schlib/autogen/connector/)
J2, J3, J4, J10 | 4 | Conn_01x03_Male | Conn_01x03_Male | pin_header_connectors:1X03 | Generic connector, single row, 01x03, script generated (kicad-library-utils/schlib/autogen/connector/)
J6 | 1 | DCJ200-10-A-XX-X_REVA | DCJ200-10-A-XX-X_REVA | Connector_BarrelJack:BarrelJack_Wuerth_6941xx301002
J7 | 1 | Conn_01x07_Male | Conn_01x07_Male | Connector_PinHeader_2.54mm:PinHeader_1x07_P2.54mm_Vertical | Generic connector, single row, 01x07, script generated (kicad-library-utils/schlib/autogen/connector/)
J8, J17 | 2 | Conn_01x06_Male | Conn_01x06_Male | Connector_PinHeader_2.54mm:PinHeader_1x06_P2.54mm_Vertical | Generic connector, single row, 01x06, script generated (kicad-library-utils/schlib/autogen/connector/)
J9 | 1 | Conn_01x04_Female | Conn_01x04_Female | pin_header_connectors:1X04 | Generic connector, single row, 01x04, script generated (kicad-library-utils/schlib/autogen/connector/)
J11, J12, J13 | 3 | Conn_01x05_Male | Conn_01x05_Male | pin_header_connectors:1X05 | Generic connector, single row, 01x05, script generated (kicad-library-utils/schlib/autogen/connector/)
J14 | 1 | B2B-XH-A_LF__SN_ | B2B-XH-A_LF__SN_ | Power JST Connector:JST_B2B-XH-A_LF__SN_
J16 | 1 | Screw_Terminal_01x05 | Screw_Terminal_01x05 | TerminalBlock:TerminalBlock_bornier-5_P5.08mm | Generic screw terminal, single row, 01x05, script generated (kicad-library-utils/schlib/autogen/connector/)
L1 | 1 | 100uH | L | inductor:CDRH127_inductor_smd | Inductor
R1, R2, R3, R4, R5, R6, R7, R8, R10 | 9 | 330 | R | Resistor_SMD:R_0603_1608Metric | Resistor
R9 | 1 | 470 | R | Resistor_SMD:R_0603_1608Metric | Resistor
R11, R12, R13, R14 | 4 | 1k | R | Resistor_SMD:R_1206_3216Metric | Resistor
R16 | 1 | 10K | R | Resistor_SMD:R_1206_3216Metric | Resistor
R17 | 1 | 1K | R | Resistor_SMD:R_1206_3216Metric | Resistor
SW1, SW2, SW3, SW4 | 4 | SW_Push_Dual | SW_Push_Dual | tactile_smd:spst_tactile_sw_2x02_smd | Push button switch, generic, symbol, four pins
T3 | 1 | Screw_Terminal_01x02 | Screw_Terminal_01x02 | terminal_block:12V_1x02_tht | Generic screw terminal, single row, 01x02, script generated (kicad-library-utils/schlib/autogen/connector/)
TP1, TP2 | 2 | TestPoint | TestPoint | testpoint_pad:pad_1,27-2,54_smd | test point
U1 | 1 | ESP32-DEVKITC-32D | ESP32-DEVKITC-32D | MCU_ESP32:ESP32-DEVKITCv4-32D
U2 | 1 | AMS1117-3.3 | AMS1117-3.3 | Package_TO_SOT_SMD:SOT-223-3_TabPin2 | 1A Low Dropout regulator, positive, 3.3V fixed output, SOT-223
U3 | 1 | TB6612FNG | ROB-14450 | motor_driver:TB6612FNG_2
U5 | 1 | LM2576S-5 | LM2576S-5 | Package_TO_SOT_SMD:TO-263-5_TabPin3 | 5V, 3A SIMPLE SWITCHER® Step-Down Voltage Regulator, TO-263

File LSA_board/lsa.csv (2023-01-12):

Source: | /home/chinmay/Desktop/sra-board-hardware-design/sensors_2023/lsa/lsa/lsa.kicad_sch
Date: | Sun 11 Dec 2022 02:22:51 AM IST
Tool: | Eeschema 6.0.9-8da3e8f707~117~ubuntu22.04.1
Generator: | /usr/share/kicad/plugins/bom_csv_grouped_by_value_with_fp.py
Component Count: | 16
Ref | Qnty | Value | Cmp name | Footprint | Description | Vendor
J1, | 1 | Conn_01x07_Male | Conn_01x07_Male | Connector_PinHeader_2.54mm:PinHeader_1x07_P2.54mm_Vertical | Generic connector, single row, 01x07, script generated (kicad-library-utils/schlib/autogen/connector/)
R1, R3, R5, R7, R9, | 5 | 4.7k | R | Resistor_SMD:R_1206_3216Metric_Pad1.30x1.75mm_HandSolder | Resistor
R2, R4, R6, R8, R10, | 5 | 150R | R | Resistor_SMD:R_1206_3216Metric_Pad1.30x1.75mm_HandSolder | Resistor
U1, U2, U3, U4, U5, | 5 | TCRT5000 | TCRT5000 | TCRT5000:OPTO_TCRT5000

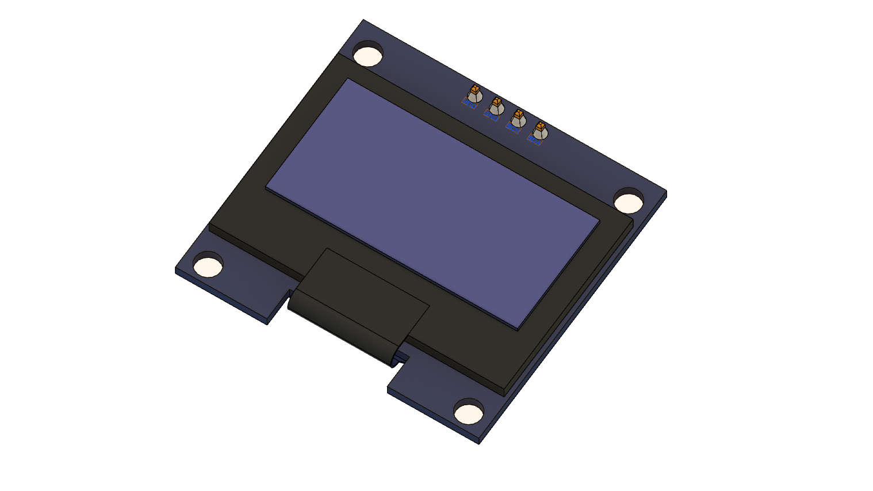
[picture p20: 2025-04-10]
sra_dev_board_2024/component_libraries/oled/PCB v8.png

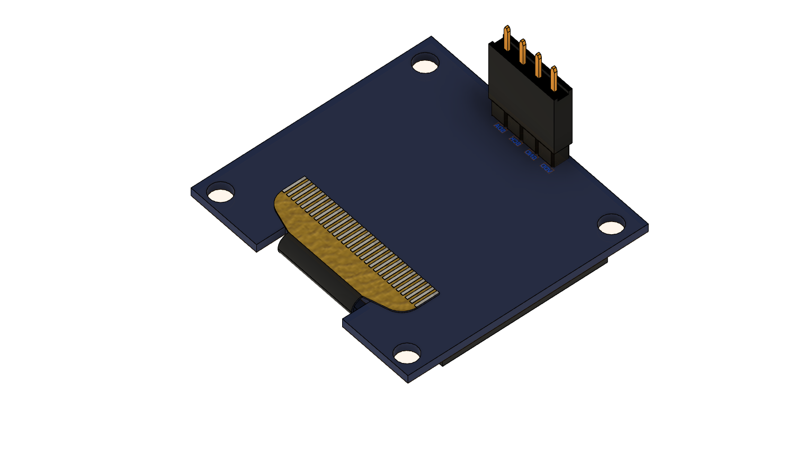
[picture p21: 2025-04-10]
sra_dev_board_2024/component_libraries/oled/PCB v8.1.png

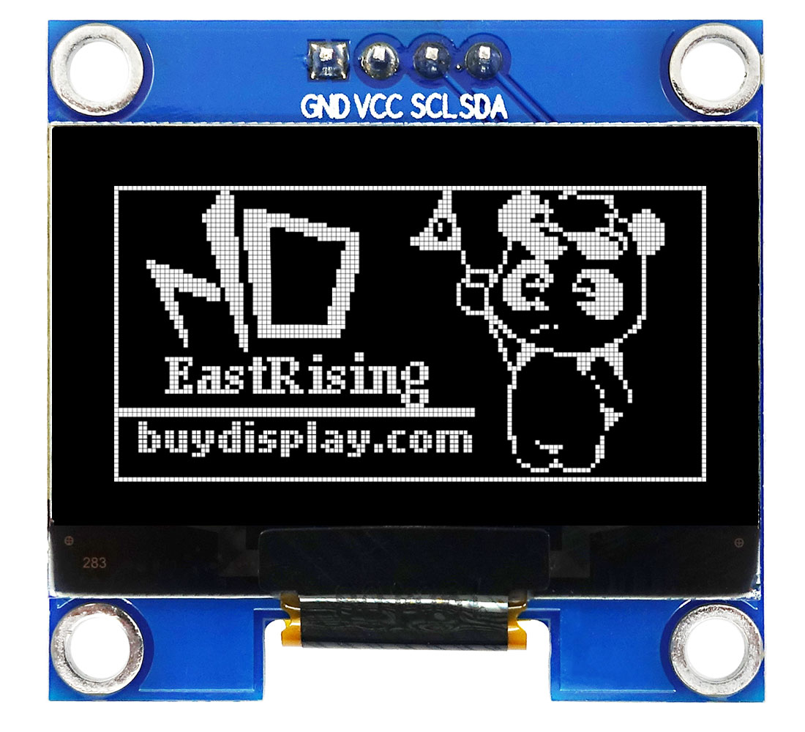
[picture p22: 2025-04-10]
sra_dev_board_2024/component_libraries/oled/I2C White 1.3 inch OLED Display Module 128x64 Arduino,Raspberry Pi.jpg

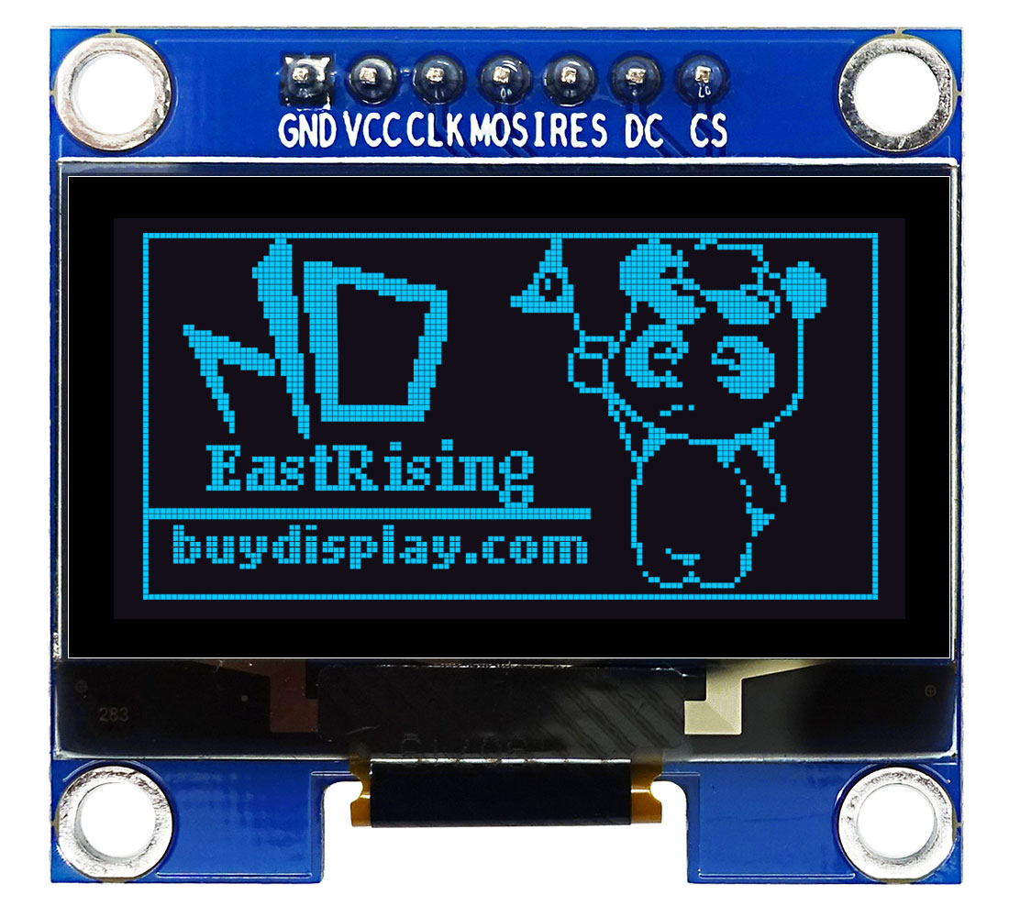
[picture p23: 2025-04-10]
sra_dev_board_2026/component_libraries/oled/Serial SPI I2C Blue 1.3 inch Arduino,Raspberry Pi OLED Display 128x64.jpg

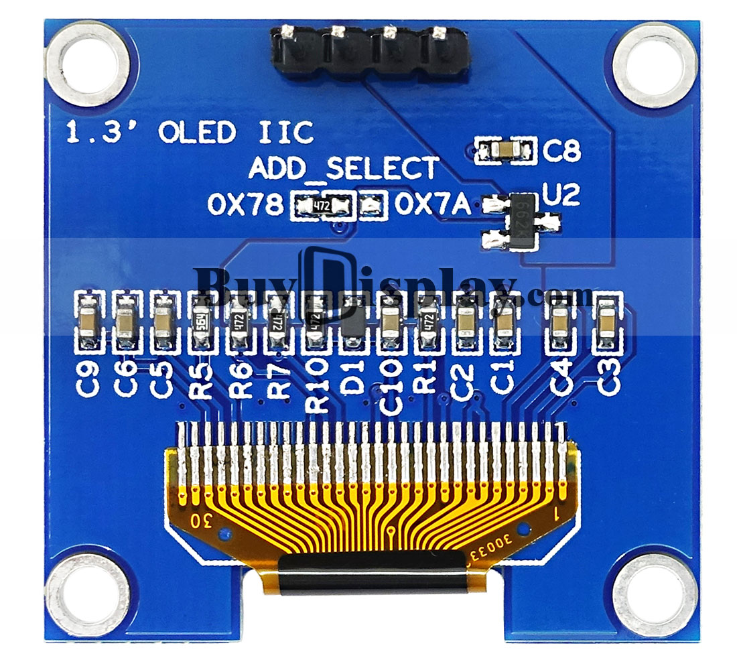
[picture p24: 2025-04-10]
sra_dev_board_2024/component_libraries/oled/ER-OLEDM013-1-I2C_Bottom_View.jpg

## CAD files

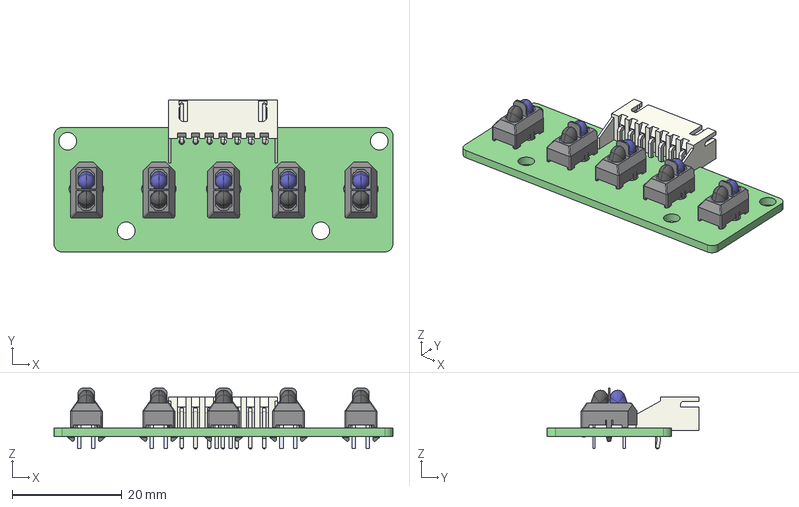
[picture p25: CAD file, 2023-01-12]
3d_models/lsa_model/lsa-2023.step
61.7 x 27.7 x 11.1 mm
_autosave-lsa PCB

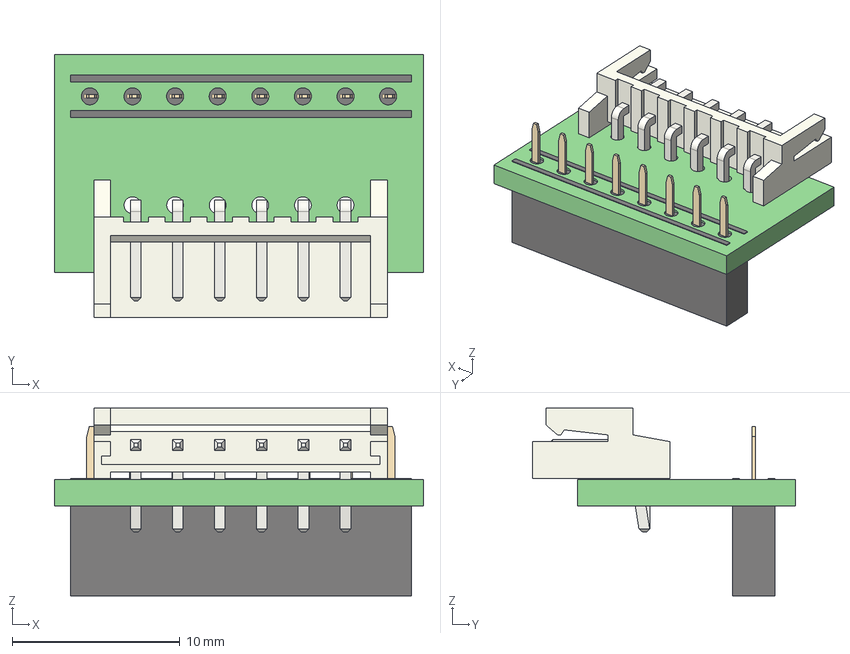
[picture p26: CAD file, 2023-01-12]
3d_models/mpu_model/mpu-2024.step
22.0 x 15.7 x 11.2 mm
_autosave-mpu PCB

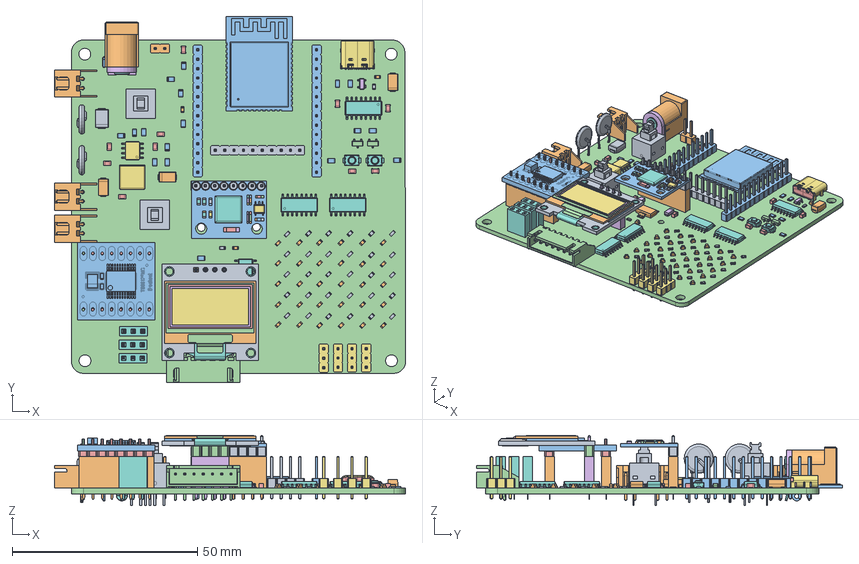
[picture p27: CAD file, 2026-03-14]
3d_models/sra_board_model/sra_dev_board_2026.step
94.8 x 98.8 x 18.9 mm
R_0603_1608Metric x 32
LED_0603_1608Metric x 33
R_0805_2012Metric x 22
SOT-23 x 2
C_0805_2012Metric x 14
SOT-143
PinHeader_1x03_P2.54mm_Vertical x 4
SW_Push_SPST_NO_Alps_SKRK x 2
PinHeader_1x10_P2.54mm_Vertical
PinHeader_1x02_P2.54mm_Vertical
USB_C_Receptacle_GCT_USB4105-xx-A_16P_TopMnt_Horizontal
PinSocket_1x03_P2.54mm_Vertical x 3
dpdt_sw_2x03_tht x 2
JST_XH_S2B-XH-A-1_1x02_P2.50mm_Horizontal x 3
PinHeader_1x14_P2.54mm_Vertical x 2
DM-OLED096-636_Module
DM-OLED096-636_Panel
PinSocket_1x04_P2.54mm_Vertical
SOIC-8-1EP_3.9x4.9mm_P1.27mm_EP2.29x3mm
SOIC-16_3.9x9.9mm_P1.27mm x 5
RUEF x 2
PinSocket_1x08_P2.54mm_Vertical x 4
TB6612FNG Motor Driver v1
1x8 v1 x 2
CP_EIA-3216-10_Kemet-I x 2
sra_board final iteration 1.79.1
D_SMB
SOT-223
MPU6050 v2
PinHeader_1x08_P2.54mm_Vertical
D_SMA x 3
ESP32-WROOM-32E
JST_XH_S7B-XH-A-1_1x07_P2.50mm_Horizontal
dc_power_jack
sra_dev_board_2026_PCB

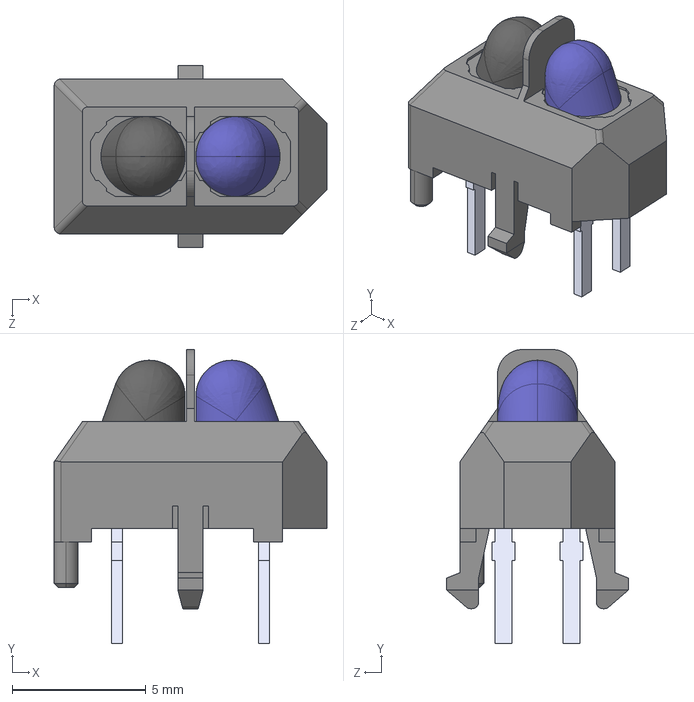
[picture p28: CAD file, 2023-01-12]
LSA_board/component_libraries/TCRT5000/TCRT5000.step
10.2 x 11.0 x 6.80 mm

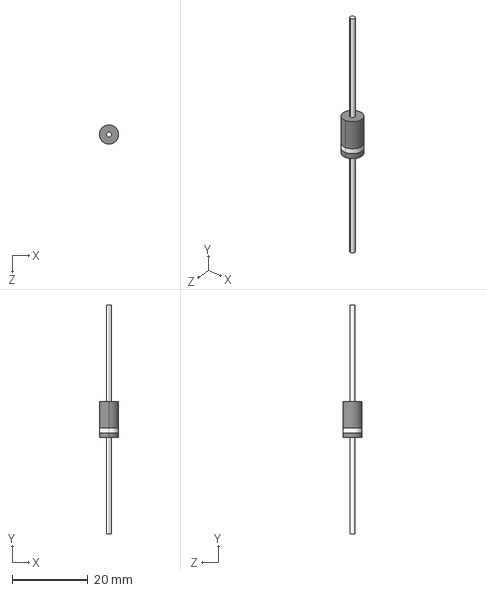
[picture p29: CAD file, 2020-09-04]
sra_dev_board_2022/component_libraries/diode/1N5822/1N5822.STEP
5.08 x 60.3 x 5.08 mm

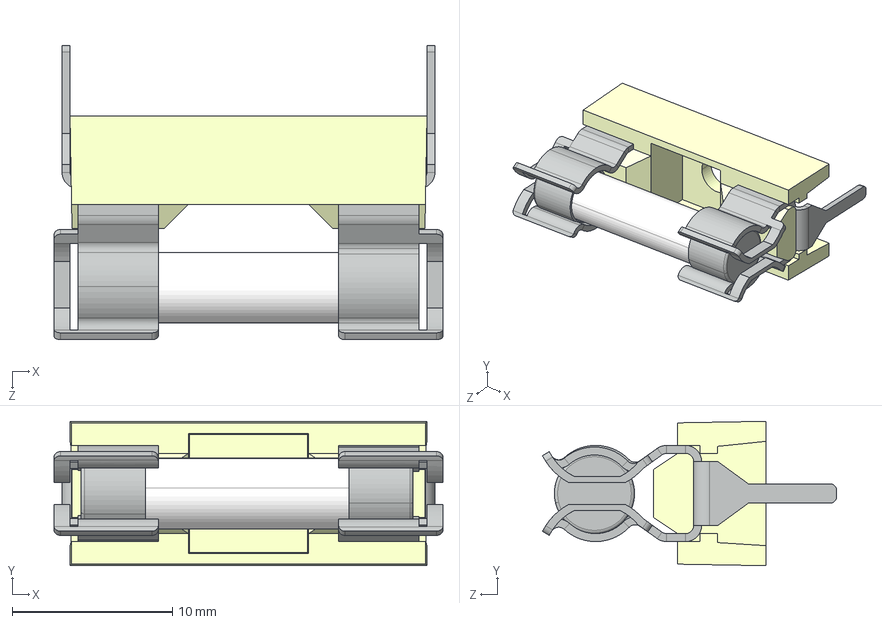
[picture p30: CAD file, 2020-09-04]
sra_dev_board_2022/component_libraries/fuse/fuse_holder_tht.STEP
24.3 x 9.00 x 18.3 mm
5x20mm PCB Fuse Holder Body 1
5x20mm PCB Fuse Holder Clip 2 x 2
5x20mm Fuse Glass Tube
5x20mm Fuse End Cap x 2
5x20mm Fuse Wire

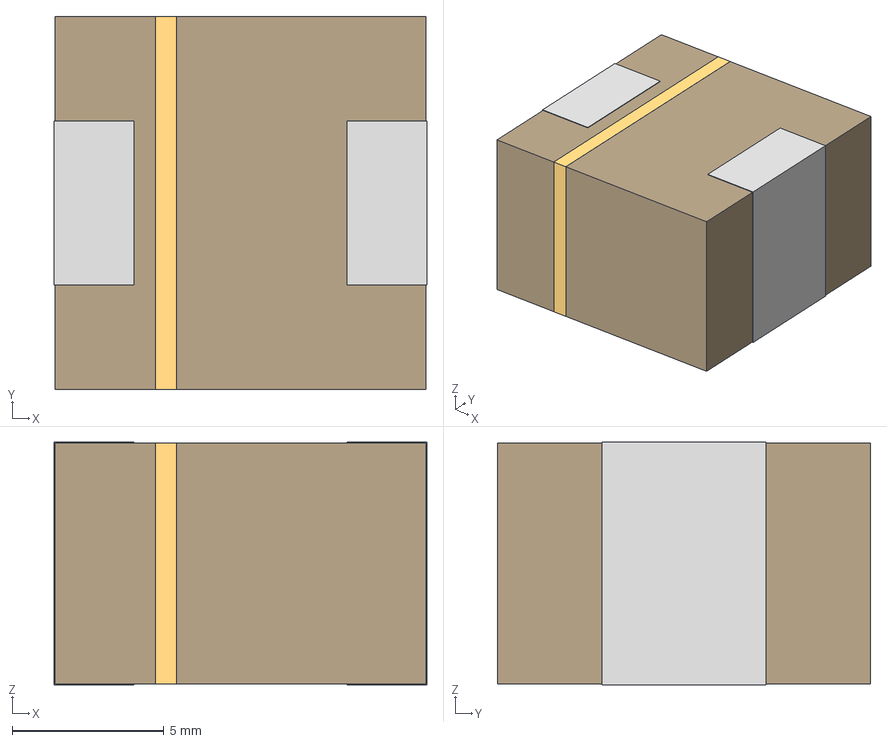
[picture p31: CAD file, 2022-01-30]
sra_dev_board_2022/component_libraries/inductor/CDRH127_inductor_smd.step
12.3 x 12.3 x 8.00 mm

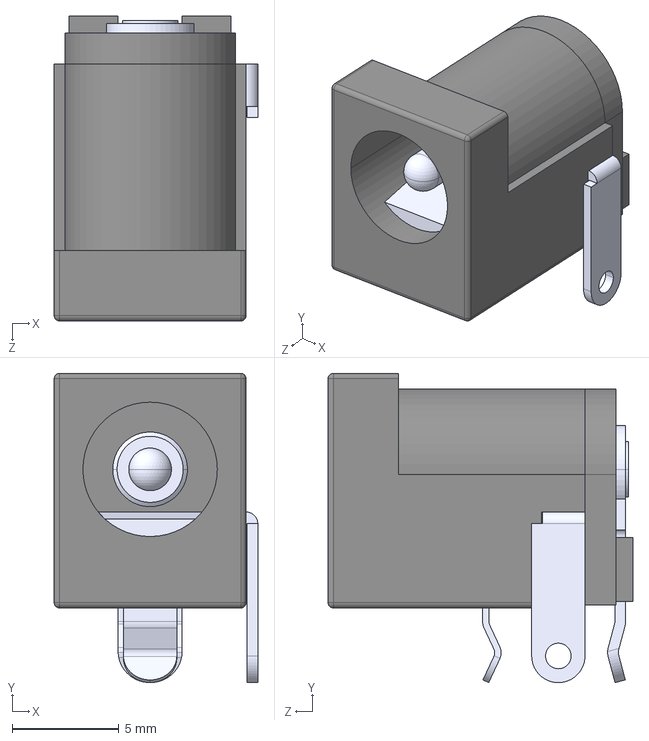
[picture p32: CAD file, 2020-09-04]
sra_dev_board_2022/component_libraries/power_jack/dc_power_jack.step
9.55 x 14.5 x 14.3 mm

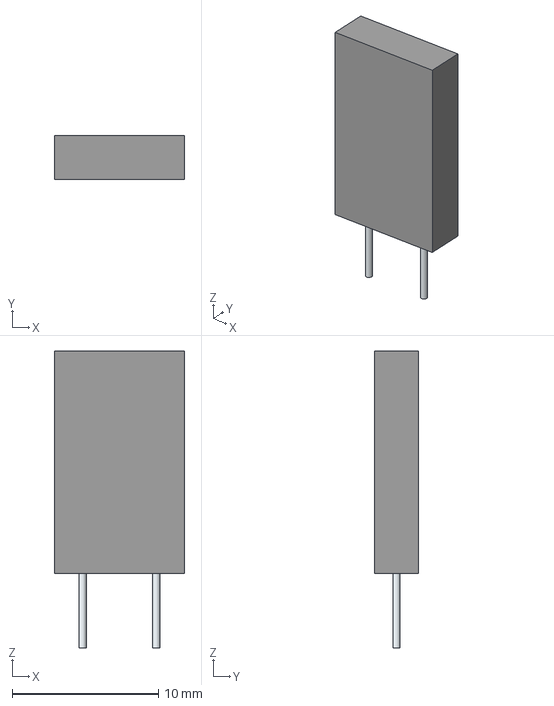
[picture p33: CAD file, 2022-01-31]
sra_dev_board_2022/component_libraries/ptc_fuse/RUEF150_3,2A_trip/RUEF160.stp
8.90 x 3.00 x 20.3 mm
Leads

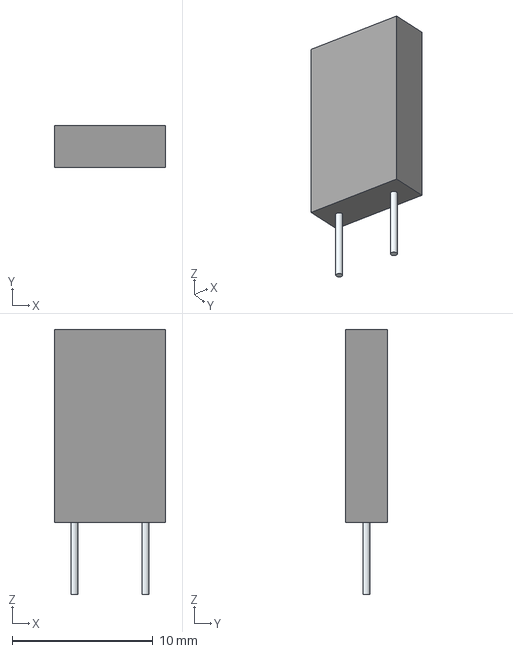
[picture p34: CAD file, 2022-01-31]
sra_dev_board_2022/component_libraries/ptc_fuse/RXEF050_1A_trip/RXEF050.stp
7.90 x 3.00 x 18.8 mm
Leads x 2

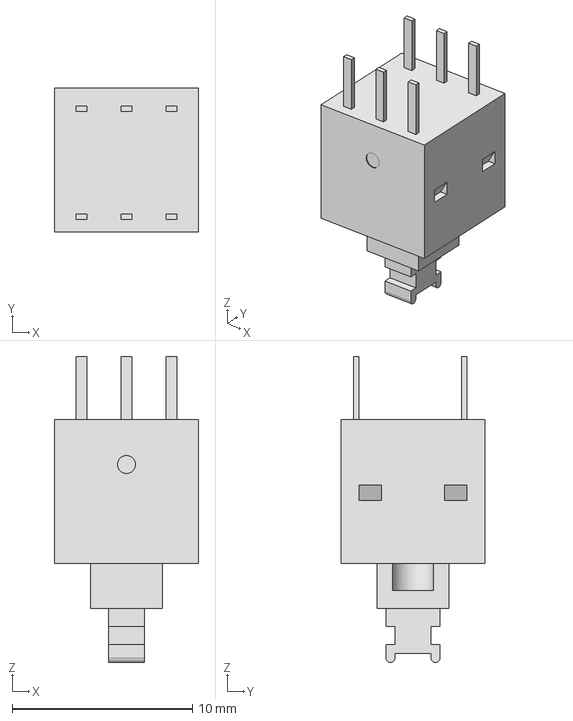
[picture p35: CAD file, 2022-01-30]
sra_dev_board_2022/component_libraries/switches/dpdt_tht/dpdt_sw_2x03_tht.STEP
8.00 x 8.00 x 17.0 mm

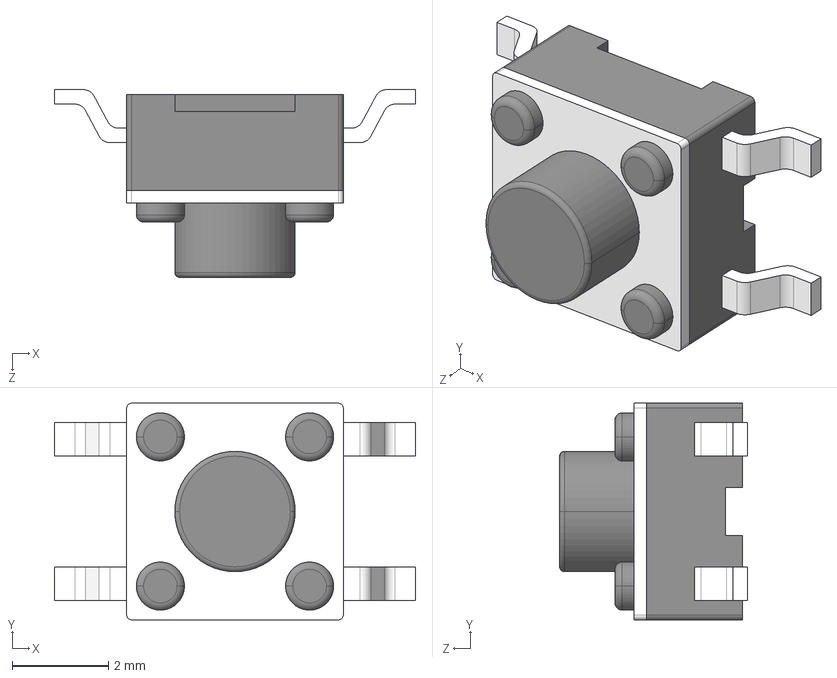
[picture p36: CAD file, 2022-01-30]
sra_dev_board_2022/component_libraries/switches/tactile_smd/spst_tactile_sw_2x02_smd.stp
7.50 x 4.50 x 3.90 mm

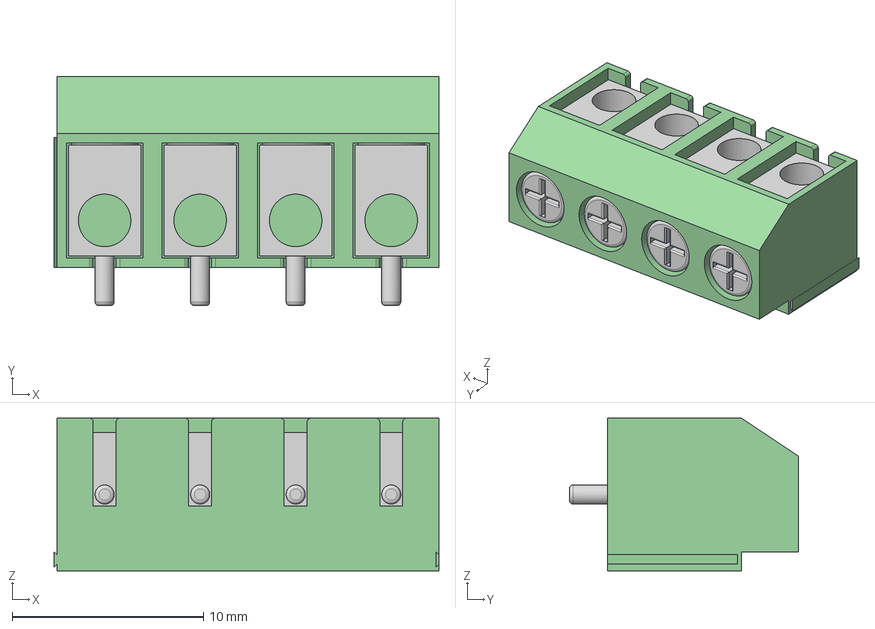
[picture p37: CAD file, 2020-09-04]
sra_dev_board_2022/component_libraries/terminal_block/motor_1x04_tht.step
20.1 x 12.0 x 8.00 mm

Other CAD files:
3d_models/lsa_model/lsa-2024.step
3d_models/mpu_model/mpu-2023.step
sra_dev_board_2022/component_libraries/inductor/CDRH104R_inductor_smd.stp
sra_dev_board_2022/component_libraries/ptc_fuse/RUEF150_3,2A_trip/RUEF160.stl
sra_dev_board_2022/component_libraries/ptc_fuse/RXEF050_1A_trip/RXEF050.stl
sra_dev_board_2022/component_libraries/terminal_block/12V_1x02_tht.step
sra_dev_board_2023/component_libraries/inductor/CDRH104R_inductor_smd.stp
sra_dev_board_2023/component_libraries/ptc_fuse/RUEF150_3,2A_trip/RUEF160.stl
sra_dev_board_2023/component_libraries/ptc_fuse/RXEF050_1A_trip/RXEF050.stl
sra_dev_board_2023/component_libraries/stepper_motor_driver/A4988_STEPPER_MOTOR_DRIVER_CARRIER.step
sra_dev_board_2023/component_libraries/terminal_block/12V_1x02_tht.step
sra_dev_board_2024/component_libraries/4407/AP4407GM.stp
sra_dev_board_2024/component_libraries/8254a/S-8254AAJFT-TB-G.stp
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

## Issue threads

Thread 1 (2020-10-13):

add more information

nilay994, 2020-10-13:
A suggestion not an issue:
### Front silk
1. Add year of manufacture
2. version of board
3. name of main contributor (architect of the board)..

### Rear silk
1. add logo
2. add some more pin labels (even if they exist on upper silk mask).

ombhilare999, 2022-02-10:
https://github.com/Aniruddha1261/sra-board-hardware-design/tree/master/documentation/images
New board images can be found here

Closed 2022-02-10.

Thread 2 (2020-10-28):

Schematics in PDF format

sachin0x18, 2020-10-28:
Suggestion to add the schematics in PDF format so that it can be viewed without any CAD software.

ombhilare999, 2022-02-10:
new board schematic can be found here
https://github.com/SRA-VJTI/sra-board-hardware-design/blob/master/renders/sra_dev_board_2022_schematics.pdf

Closed 2022-02-10.

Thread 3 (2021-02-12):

Add Datasheets folder

udit7395, 2021-02-12:
For eg we use IC LM324 , Motor Driver XYZ, LDO, etc

ombhilare999, 2021-02-12:
Sra board hardware design repo already has a datasheet folder, I haven't added all the datasheets there, didn't want to increase the size of that repo.
@laukik-hase We should add all the datasheet links maybe in a readme.
https://github.com/SRA-VJTI/sra-board-hardware-design/tree/master/datasheets

VedantParanjape, 2021-02-12:
@ombhilare999 datasheets are hardly 100kb, won't increase the size much.

ombhilare999, 2021-02-13:
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
https://github.com/SRA-VJTI/sra-board-hardware-design/tree/master/datasheets
The current size of the datasheet folder, I guess all links in one readme serve the purpose.
@laukik-hase @VedantParanjape

VedantParanjape, 2021-02-13:
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

Links can be dead at any point, it's better to have separate pdf

udit7395, 2021-02-16:
@VedantParanjape If a consensus has been reached, close the issue

Closed 2021-02-16.

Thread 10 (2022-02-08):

Add stl, stp (STEP) files for SRA Board, LSA and MPU

dhairyashah1, 2022-02-08:
Uses-
1. Essential and easy to export in other CAD software (Solidworks, Coppelia, FreeCAD, etc)
2. Useful for use in simulation

Kindly add these files and update them [here](https://github.com/SRA-VJTI/sra-board-hardware-design/tree/master/3d_models).
- Replace the old files.
- This should be done for sra_board, LSA, and MPU in respective directories
- @Aniruddha1261 kindly make the required changes and update your PR

ombhilare999, 2022-02-10:
solved here #7

Closed 2022-02-10.

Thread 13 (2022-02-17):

Add Pinout Image of SRA board and sensors

ombhilare999, 2022-02-17:
Something like this can be done for the boards and sensors:

Example 1:
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

Example 2:
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

ombhilare999, 2022-02-17:
@dhairyashah1 assign this task to some second-year student.

dhairyashah1, 2022-02-17:
@omsheladia i hope you can prepare the same. Get working on it.

rahulsingh701, 2022-02-23:
update @dhairyashah1 ?

dhairyashah1, 2022-02-23:
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

ombhilare999, 2022-02-24:
The first Image needs improvements, too many arrows crossing each other.
Check out this: https://hackaday.com/2021/08/03/tool-generates-interactive-pcb-diagrams-from-kicad/
Demo: https://blog.honzamrazek.cz/2021/06/making-nice-looking-and-interactive-diagrams-for-your-pcbs/

VedantParanjape, 2022-08-30:
@gautam-dev-maker remove inactive members from this project (@omsheladia )

omsheladia, 2022-08-30:
The tool suggested by Omkar didn't seem to work on my system then, however if crossing of arrows is the only concern then I have found something else that can do the work, @gautam-dev-maker  let me know if I can carry on with that.

dhairyashah1, 2022-08-30:
What is that something else? Links / demos are desired @omsheladia

VedantParanjape, 2022-08-30:
> The tool suggested by Omkar didn't seem to work on my system then, however if crossing of arrows is the only concern then I have found something else that can do the work, @gautam-dev-maker  let me know if I can carry on with that.

I never saw error logs or you trying to get that tool working.

omsheladia, 2022-08-30:
@dhairyashah1 To prevent the crossing of arrows, we can insert an image in any flowchart maker and label them with more organised arrows compared to the ones that I used in Canva previously.

omsheladia, 2022-08-30:
@VedantParanjape I talked about it personally to Omkar but we didn't reach towards any conclusion then.

ombhilare999, 2022-08-31:
@omsheladia you sure about this?
Didn't I tell you to explore the VM option?

gautam-dev-maker, 2022-08-31:
@omsheladia I guess I have listed steps to run linux in parallels VM (during Walle). In fact I installed it in your system if I remember correctly.

dhairyashah1, 2023-01-19:
@RajGupta17 @Greyless such pinouts are expected in the README.md's for SRA_Board_2023 and LSA, MPU respectively. Kindly incorporate these in your PRs for documentation.

dhairyashah1, 2023-04-25:
Closing this as labelled pinout images are already incorporated

Closed 2023-04-25.

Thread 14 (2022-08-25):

Solve the noise issue in PCB due to motors

gautam-dev-maker, 2022-08-25:
In Wall-E 2022, we faced the issue of noise in I2C line , which was caused by static noise in motors. This forced us to add capacitors and ferrite bead on the motors. Since we have never faced this issue before with BO motors, we can assume that motor driver might not be working well in filtering the noise.

We can test it by using different motor drivers like DRV8833 to see if the problem persists.

gautam-dev-maker, 2022-08-25:
@Jamm02 @ChinmayLonkar @Sidshx kindly assign someone for this testing and post the results here and treat it as priority since we need to make changes to SRA board hardware design wrt to the post.

ChinmayLonkar, 2022-08-27:
@gautam-dev-maker I'll take this task👍

gautam-dev-maker, 2022-08-27:
HOW TO REPRODUCE THE ISSUE:

1) Place no ferride bead and capacitor on the Motor drivers
2) The issue only comes up when BO motors draw lot of current. So in situation when BO motors are obstructed it will produce the issue. Also when BO motors are run on duty cycle above 50 the issue becomes consistent.
3) Read the MPU6050, and look for readings when the above situations has been created.

WHAT TO DO:

1) Currently we are using TB6612FNG, so first step will be to reproduce the issue as mentioned above.
2) Then proceed to replacing TB6612FNG with DRV8833 (ofcourse temporarily) and test if the issue persists

Based on the result of the above test we can debug the actual solution of the issue.

Jamm02, 2022-08-27:
@omsheladia will be taking up the task

dhairyashah1, 2022-08-27:
More details on the issue -
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
Current Consumption by single Bo motor
12v, 300 rpm
Conversation on i2c packet drop and solving mpu6050 issue:

Reddit post 1: https://www.reddit.com/r/embedded/comments/srgqlz/i2c_communication_not_working_properly_when_motor/

Reddit post 2: https://www.reddit.com/r/ECE/comments/srgpyk/i2c_communication_not_working_properly_when_motor/

Reddit post 3:
https://www.reddit.com/r/arduino/comments/srgova/i2c_communication_not_working_properly_when_motor/

Reddit Post 4:
https://www.reddit.com/r/PrintedCircuitBoard/comments/srvaxa/pcb_review_i2c_communication_not_working_properly/

**Solution and Conclusion:**
Noise suppression of brushed motors
https://youtu.be/O39inZIscOI

After many test runs, the following is the conclusion until now:

1. The I2C bus when observed on DSO looked pretty fine. Both the lines go high while reading data.

2. Even after isolating Mpu6050 or using shorter / isolated i2c paths, the error persisted. Although the frequency of those errors happening was somewhat controllable to an extent.

3. Different capacitor combinations were tried across the motors and voltage lines:
Currently - 0.3 uF ceramic across each motor
220uF 25V across 12V line
0.1uF ceramic each across 3V3, GND of Motor driver (Vcc), and OLED PORT
Although this eliminated the low-frequency noise of the motors which was evident in the DSO waveforms. The problem was yet to fetch a fix. But **high-frequency noise** generated due to brush sparks inside brushed motors was **the uncaught culprit**.

Layer 0.1uF(<=100uF) was installed across the terminals of all Bo motors still no change in results.

4. Finally adding (0.1uF ceramic capacitor across motor terminals & ) ferrite beads across the motor wires and using twisted cable pairs seemed to have done the trick and reduced rf noise to a great extent for our application!!!
This is a boon for brushed motors.

For more reference view discord #wall-e channel

gautam-dev-maker, 2022-08-27:
@dhairyashah1 I am not so sure about the second point of the conclusion, because we were only able to control the error if we manually reduce the duty cycle (and hence reduce the current consumption).

Let's see if the issue con be reproduced.

dhairyashah1, 2022-08-27:
@gautam-dev-maker if we could have an economical alternative to the motors that would be great too. BO motors get stalled with ease momentarily.

gautam-dev-maker, 2022-08-27:
I agree, but then my dilemma is why didn't we face this issue with L298N motor driver, why with TB6612FNG. If motor driver is the real culprit then we will need to make serious changes.

omsheladia, 2022-08-28:
I will be taking up this task, though a small meet before getting started would be helpful.

gautam-dev-maker, 2022-08-28:
@omsheladia I would recommend you read all the material posted above and go through the reddit post provided by @dhairyashah1 , I think that is way more than enough to explain things.

Jamm02, 2022-09-01:
@omsheladia any updates on the task?

omsheladia, 2022-09-01:
@Jamm02 Gone through the resources, and am coming to the college tomorrow since I do not have Walle at the moment and will update how it goes tomorrow

omsheladia, 2022-09-03:
So, I tried running the self_balancing in 2 situations,
1: With ferrite core and the capacitors
And the readings are:
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

2: Removed just the ferrite core
And the readings are:
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
Although it lost its stability.

 I will remove the capacitor and post it as soon as I get my hands on a soldering iron. In the meanwhile I will go through the documentation of DRV8833 motor driver.

dhairyashah1, 2022-09-04:
@omsheladia
1. This is nothing new but already known.
2. If you didnt have walle kit why didnt u get it asap when the task was assigned?
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
dhairyashah1, 2022-10-29:
@Premraj02 post the updates, findings, conclusions and test performed so far here

Premraj02, 2022-10-30:
Updates:
1) I tried various inductors (in range of 22uH to 220uH) in series with motor as well as power supply of motor driver. But the error still occurs.
2) Then I tried different RC, LR, LC filters inline with motors. But these filters didn't work.
3) After this I tried shielding the MPU wires. It eliminates the noise on some SRA boards but the results are inconsistent and it doesn't work on every SRA board.
4) Yesterday I tried connecting MPU directly on SRA board using short wires. I tried connecting MPU on OLED port as well as on MPU port and the results were positive. It completely eliminates the error and works on every SRA board. If we proceed with this solution then self balancing code should be modified to compensate the offset in MPU position.

Conclusion: Connecting MPU direcly on SRA board was the best solution found. To test this solution deeply, we will need to prototype one SRA board with onboard MPU connector.

Attachments:
1) MPU connected on OLED port:
![short_mpu_2](https://user-images.githubuserc
2) MPU connected on MPU port using short wires:
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
ontent.com/84727176/198867039-da310e99-51b3-4683-8080-f7b3f6dde274.jpeg)

Premraj02, 2022-10-31:
Summary of tests performed till now:

<google-sheets-html-origin><style type="text/css"><!--td {border: 1px solid #cccccc;}br {mso-data-placement:same-cell;}--></style>

Test | Error status | Remark
--- | --- | ---
Implemented motor driver and mpu system on breadboard | error still occurs | issue is not related to noise on SRA board or routing
Replaced TB6612FNG with DRV8833(at 9V) | error did not occur | DRV8833 supplies less power to motors. Thus motors become slower. If we proceed with this configuration, one more voltage regulator will be needed on SRA board.
Replaced TB6612FNG with DRV8833(at 12V) | error did not occur | DRV8833 did not heat up but it still delivers less power to motors.
Added extra bypass capacitor on VM pin of TB6612 | error still occurs | no effect on noise
Measured noise frequency on oscilloscope | - | noise frequency is around 6.25-7 MHz
Tested SMD ferrite bead (UPZ2012E121-4R0TF) on motor wires | error still occurs | no effect on noise
Tested inductors (22uH to 220uH) in series with motor wires | error still occurs | no effect on noise.
Tested inductors (22uH to 220uH) in series with ground pin of TB6612 FNG | error still occurs | no effect on noise
Tried RC, RL, LC filters on motor wires | error still occurs | motors don't get enough power when 50 ohm resistor is added in series (RC filter), no effect on noise.
Tested aluminium foil shielding on motor wires | error still occurs | no effect on noise
Tested aluminium foil shielding on MPU wires | inconsistent observations on different SRA boards | not reliable method
Connected MPU on oled port using short wires | error did not occur | this method solves the problem but transformations MPU readings will be needed
Connected MPU on MPU port using short wires | error did not occur | this method solves the problem but transformations MPU readings will be needed

Premraj02, 2022-11-20:
Updates:
1. Tested 6 core shielded cable to connect MPU with SRA board. When the shield is properly connected to ground, it eliminates the effect of noise. This method solves the issue but does not eliminate noise. Thus other components can still malfunction due to noise.
2. Tested [4 core shielded cable](https://www.amazon.in/square-Shielded-Signal-transmission-protection/dp/B07TB6LV2B) to connect motors with SRA board. This method eliminates the noise completely and solves the issue. It also ensures that other components won't get affected by noise. I have performed rigorous testing and no error occurred. I also tested self balancing and the bot is able to balance perfectly.
Currently I have connected the cable shield to ground by using terminal block on SRA board.

Conclusion: By using 4 core shielded cable to connect motors, we can completely eliminate the noise.

Attachments:
1. 4 core shielded cable:
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

2. Motors connected to SRA board using 4 core shielded cable:
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

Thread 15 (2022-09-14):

Replace LEDs and phototransistor on LSA with IR sensors.

gautam-dev-maker, 2022-09-14:
The current design of LSA is very prone to ambient light and often cause inconvenience in line following.
Possible solution is to test [TCRT-5000](https://robu.in/product/tcrt5000-reflective-ir-sensor-photoelectric-switch/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) for ambience interference.

If it proves to be better than current design, we can easily modify our LSA design to include it.

dhairyashah1, 2022-11-01:
As discussed previously

- [ ] Try different IR based Transmitter Receiver Pairs ( PTH and SMD ) from various LAMI vendors on a perfboard
- [ ] Test on the current SRA Board and check readings on ADC lines for line-following with and without a buffer amplifier IC
- [ ] If buffer amplifier is needed, find a dealer (online or offline) if HEX IC is available ( 5 -6 gates in one IC ) for the facility of more than 4 sensor pairs if desired
- [ ] Redesign LSA PCB prototype for the best available combinations
- [ ] Test PCB Prototype
- [ ] Final Order

Hard deadline - 5th November

@marck3131 proceed with this issue and update ASAP

ChinmayLonkar, 2022-11-03:
@marck3131 Please post the perfboard testing results here ASAP

dhairyashah1, 2022-11-13:
ping @marck3131. Please post the results here as well.

marck3131, 2022-11-14:
5 IR sensors were tested on perfboard with resistors 4.7k E and 100 E , with gpio pin numbers 32, 34, 35, 36, 39
Tested Line following too with the same ...

dhairyashah1, 2022-11-14:
@marck3131 Please put the images, sensor placement and line-following demo video with new config here as well for reference.

ChinmayLonkar, 2023-01-13:
@dhairyashah1 we can close this issue as this has been implemented in the design.

dhairyashah1, 2023-01-13:
> @dhairyashah1 we can close this issue as this has been implemented in the design.

LGTM. Design PR #21 merged in master.

dhairyashah1, 2023-01-13:
Feature PR #21 merged in master

Closed 2023-01-13.

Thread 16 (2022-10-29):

Replacing extra Motor driver with Stepper Driver

dhairyashah1, 2022-10-29:
- To replace 2nd TB6612FNG Motor Driver and add functionality to drive a stepper motor on SRA Board - **PCB design**
- Mention specifications of the driver used & models of stepper tested across
- Add Terminal blocks to connect the servo motor
- Pin headers/Pads/terminals for external supply (if desired to operate on higher rating (not from SRA board 5V/3V3))

Suggestion -
Include a Switch to toggle between power supply from SRA Board <-> External supply connected to port/pin header/pad

CC: @ChinmayLonkar @Asc91
Share the Updates with Images of PCB and changes made so far here

Asc91, 2022-10-30:
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

This is initial version of SRA board with added stepper motor driver.
Driver used : [DRV8825](https://www.tme.eu/Document/1dd18faf1196df48619105e397146fdf/POLOLU-2133.pdf)
Motor Tested: Nema 17

https://user-images.githubusercontent.com/55803500/198893070-4ce25d15-41e1-474a-a37e-f0e8930bdfe7.mp4

Current 12V adapter is used to power the motor.

ChinmayLonkar, 2022-11-03:
@dhairyashah1 ,
I have created a pull request, Kindly review and let me know if there re any changes to be made

dhairyashah1, 2023-02-02:
@ChinmayLonkar is the current design compatible with housing either DRV8825 or A4988 without any other changes?

ChinmayLonkar, 2023-02-04:
Yes, we can use both of them without any changes.

Closed 2023-03-24.

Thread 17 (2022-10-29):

[ PCB Design ] Add Pin header in front of current MPU Port for direct MPU6050 plugin

dhairyashah1, 2022-10-29:
- The noise observed on the SDA and SCL lines of MPU6050 leads to an I2C Packet drop while self-balancing (motors running).
- This is related to interference between the BO Motor wires and the long MPU JST Cable.
- Shortening the length of I2C lines prevents this issue. Ref #14
- This issue aims to add a direct pin header port for direct plug-play and operation of the MPU6050 on the SRA Board

Todo -
- [ ] Update test results for direct plugin MPU near the current port
- [ ] Test the above thoroughly with self-balancing
- [ ] Make changes in the PCB Design
- [ ] Updated PCB Fabrication, Assembly
- [ ] Rigorous testing for self-balancing and making suitable changes ( like using MPU Offset) in the [firmware](https://github.com/SRA-VJTI/Wall-E/tree/master) for[ 3_MPU](https://github.com/SRA-VJTI/Wall-E/tree/master/3_MPU) and [8_self_balancing](https://github.com/SRA-VJTI/Wall-E/tree/master/8_self_balancing)

CC - @ChinmayLonkar @Premraj02

ChinmayLonkar, 2022-10-31:
@Premraj02 take up this task and post the updates before 2nd November.

ChinmayLonkar, 2022-11-03:
As per our testing pin header is not required as we can directly use the shielded cables which resolves the issue,
@Premraj02 you can put up the test results here for the test in which you connected the MPU near the current port.

dhairyashah1, 2022-11-13:
ping @Premraj02 .Put/link the test results so that I may close this issue.

Premraj02, 2022-11-20:
[This](https://github.com/SRA-VJTI/sra-board-hardware-design/issues/14#issuecomment-1321137060) test solved the noise issue. So no need to add pin header.

Closed 2022-11-20.

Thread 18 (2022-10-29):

Add web page for Board Hardware Documentation, posting test Blogs

dhairyashah1, 2022-10-29:
This issue aims to create a separate dynamic webpage that hosts the `documentation` and `README.md`s along with some other features viz. Adding board information, 3D layout + Images, testing blogs. Site hosted on **GitHub Pages**

**Suggestion -**
Use [jekyll](https://jekyllrb.com/) - a simple site generator using gh-pages. Tutorials can be found [here](https://docs.github.com/en/pages/setting-up-a-github-pages-site-with-jekyll).
Ref - https://sravjti.in/sra-board-component/

**Todo -**
- [ ] Fix any bugs in the current README.md description files
- [ ] Add/Optimise any technical content
- [ ] Create a different branch called `gh-pages` and then start contributing
- [ ] Host a site including the above information for [Board](https://github.com/SRA-VJTI/sra-board-hardware-design/blob/master/README.md) and Sensors - [LSA](https://github.com/SRA-VJTI/sra-board-hardware-design/blob/master/sensors_2022/lsa/README.md) and [MPU](https://github.com/SRA-VJTI/sra-board-hardware-design/blob/master/sensors_2022/mpu/README.md)
- [ ] Another page or subsection to **display blogs** on debugging/ technical matter observed during the journey of Board development
- [ ] Another page or subsection to **display renders, 3d models, images and renders**. Something like - https://yellow.home-assistant.io/yellow-v1.2-standard/

CC - @Dhruv454000 @ChinmayLonkar @Sidshx assign this issue to some SY

SuperChamp234, 2022-10-31:
@dhairyashah1 I can take on this issue.

Looks like there is documentation in the `documentation` folder as well as the main `README.md`. Any other locations that I should include?

Also only document the 2021 SRA Board, right?

dhairyashah1, 2022-11-05:
Yes, apart from the `documentation` and `README.md` files, a custom section for blogs to be created, basically create a folder containing many md files containing the blog content. These can be displayed under the `Blog `section on the web page.
Additionally, refer last 2 points of the tasklist.

SuperChamp234, 2022-11-07:
Task 1 done, moving on to next tasks

dhairyashah1, 2022-11-20:
Update @SuperChamp234 ?

SuperChamp234, 2022-11-20:
Working on setting up hugo to host the blogs. Sorry for the delay, will make some progress asap.

dhairyashah1, 2022-12-11:
Updates @SuperChamp234

dhairyashah1, 2023-01-10:
@SuperChamp234 post the temporary link of the website created here.

SuperChamp234, 2023-01-11:
Here is the temporary deployment at: https://superchamp234.github.io/sra-board-hardware-design/

A few points to note about the deployment:

1. Currently the Hugo Workflow copies the `README.md`, the LSA README as well as the MPU README, from their folders. If more files need to be added, the workflow will have to be changed(easy to do so).
2. Currently using the `hugo-book` theme.
3. All documentation assets must be placed in `/documentation` folder, as it is statically uploaded.
4. Blog posts can be hosted too, please update about their requirement if needed.

SuperChamp234, 2023-01-11:
I shall now begin working on the display section, or the 6th Todo

dhairyashah1, 2023-02-02:
Update @SuperChamp234

dhairyashah1, 2023-03-11:
@SuperChamp234 updates? Points 5 and 6 are required as well. A section to display specific `blogs` or  discussions and
#2
> [ ] Another page or subsection to **display renders, 3d models, images and renders**. Something like - https://yellow.home-assistant.io/yellow-v1.2-standard/

this would be desired. Displaying blogs written in `.md` format would be good. One can also look towards showing prominent GitHub issues like #14. Expecting this work to be done ASAP.

CC - @ChinmayLonkar @Premraj02

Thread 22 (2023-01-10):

Update README.md for SRA_Board_2023, LSA and MPU as per current changes

dhairyashah1, 2023-01-10:
1. The images and references should be complete and within the systematic folders of this repository. eg `assets`.
2. Information should be updated, written properly in points with links to relevant work and in comparison to previous design highlighting `improvements, what and why` incorporated in this year's design.
3. Images, videos, or gifs should be scaled to uniformity.
4. Fixes and improvements with respect to the previous documentation are desired.
5. Links to relevant issues encountered and their solutions can be mentioned as well. I suggest linking this to blog posts later as mentioned in #18

@ChinmayLonkar @Jamm02 @Premraj02 assign this task to some SY

RajGupta17, 2023-01-13:
I and @rajatkaush11 are doing this work, most of the changes are done, it will be ready in sometime

dhairyashah1, 2023-01-13:
Issue a PR when done. I hope you are working on individual forks of this repo.

RajGupta17, 2023-01-13:
Yes, we have forked this repo and are working on local

RajGupta17, 2023-01-13:
https://github.com/RajGupta17/sra-board-hardware-design

Updated the markdown for SRA Board 2023, the pictures of Motor Driver modes are yet to be updated, rest everything is done according to the suggestions. @dhairyashah1 @ChinmayLonkar @Jamm02

dhairyashah1, 2023-01-16:
@RajGupta17 seems like your fork is quite behind and is not in sync with many of the current upstream commits. Update that asap. Also include latest images of the board

ChinmayLonkar, 2023-03-30:
Readme Updated

Closed 2023-03-30.

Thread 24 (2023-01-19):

Design fixes in SRA_Dev_Board_2023

dhairyashah1, 2023-01-19:
The following issues in design need to be corrected and updated to avoid inconsistencies:=
- [ ] Correct the silkscreen for LED Array Port with the proper GPIO naming convention
- [ ] Search for a software side solution to handle/disable the MPU6050 interrupt and use that pin as a GPIO when disabled without breaking the INT line connectivity
- [ ] Any other required changes
- [ ] Update gerbers, renders, assets, documentation accordingly

CC - @ChinmayLonkar

ChinmayLonkar, 2023-02-21:
I have made the required changes and made the PR #26

Closed 2023-03-30.

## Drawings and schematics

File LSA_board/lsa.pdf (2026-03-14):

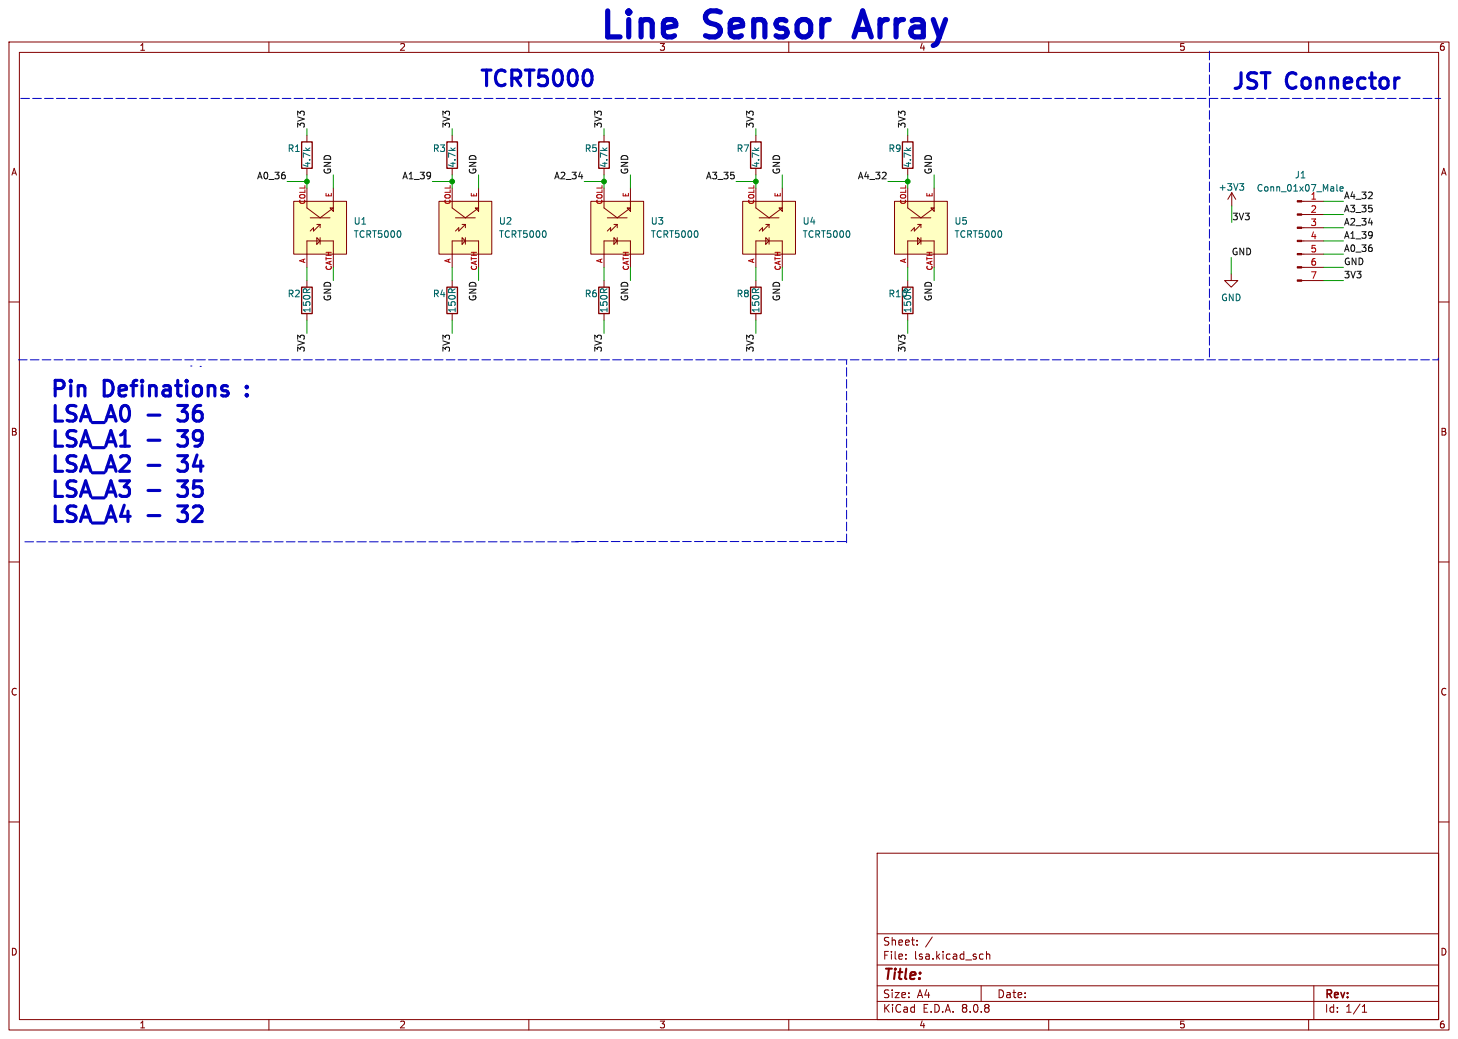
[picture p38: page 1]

A CATH COLL E U2 TCRT5000 3V3 3V3 3V3 A2_34 GND GND GND 3V3 3V3 GND 3V3 GND GND GND

Id: 1/1 Title: File: lsa.kicad_sch Sheet: /

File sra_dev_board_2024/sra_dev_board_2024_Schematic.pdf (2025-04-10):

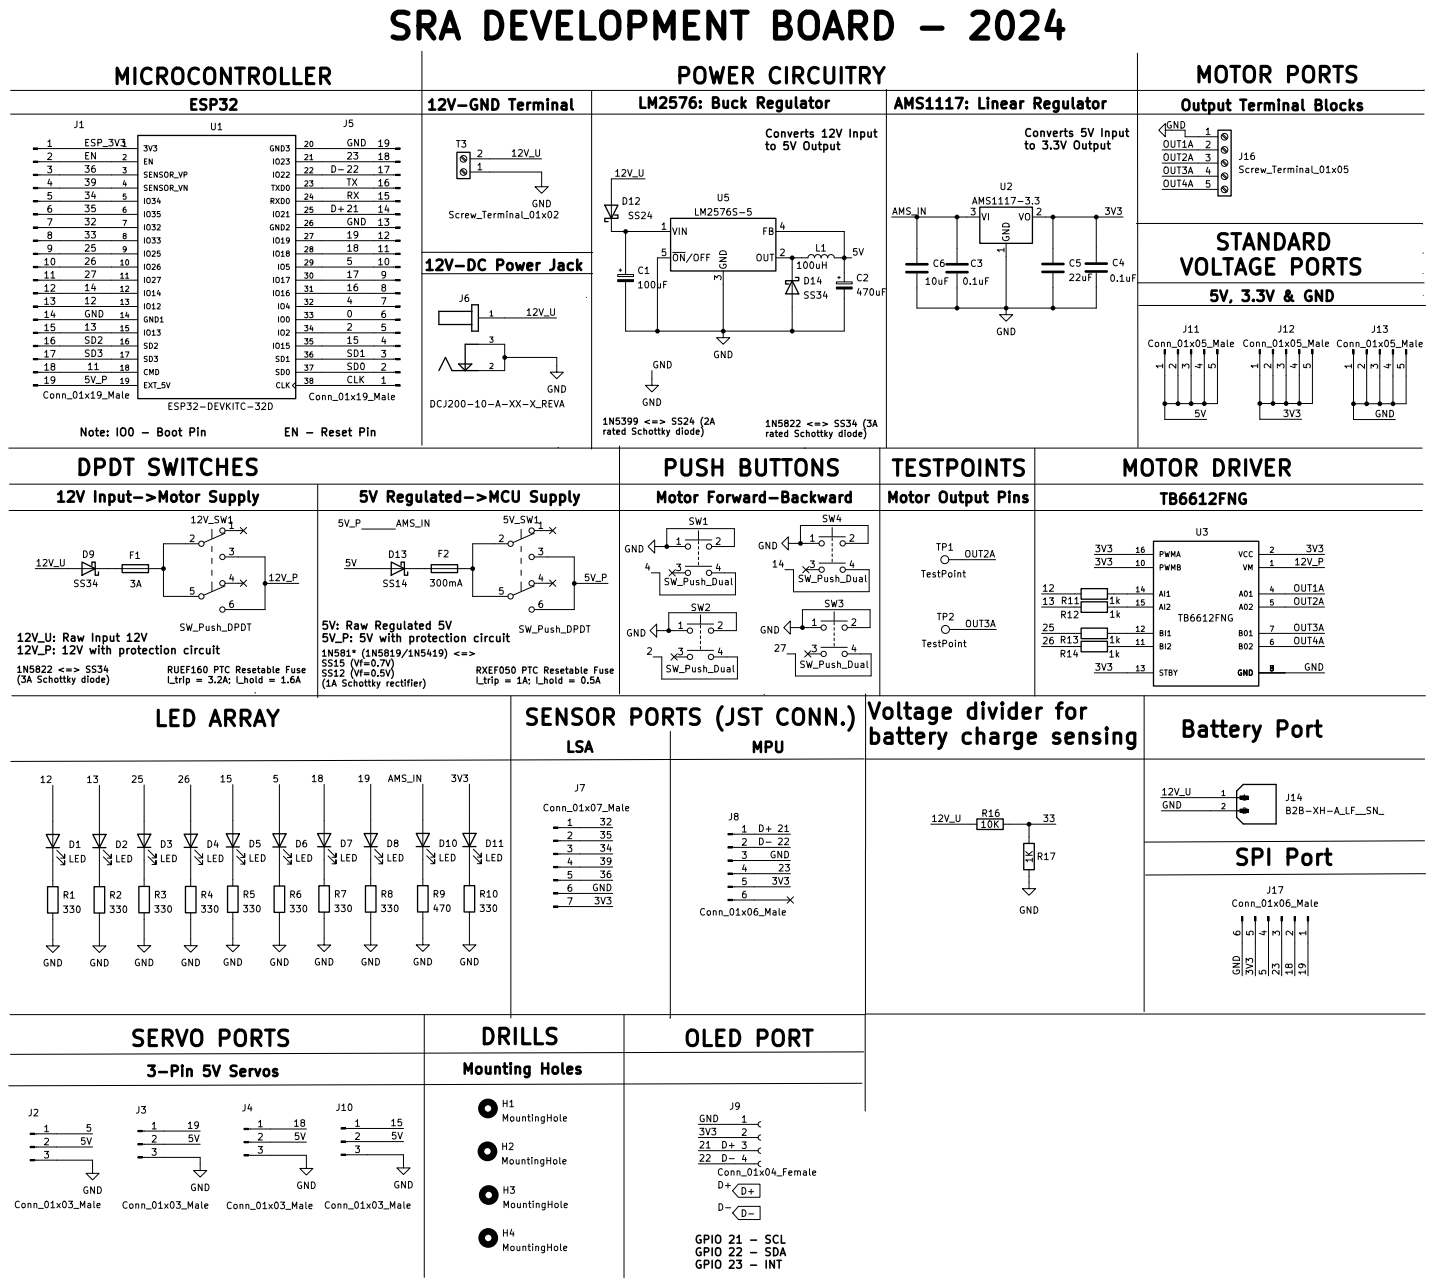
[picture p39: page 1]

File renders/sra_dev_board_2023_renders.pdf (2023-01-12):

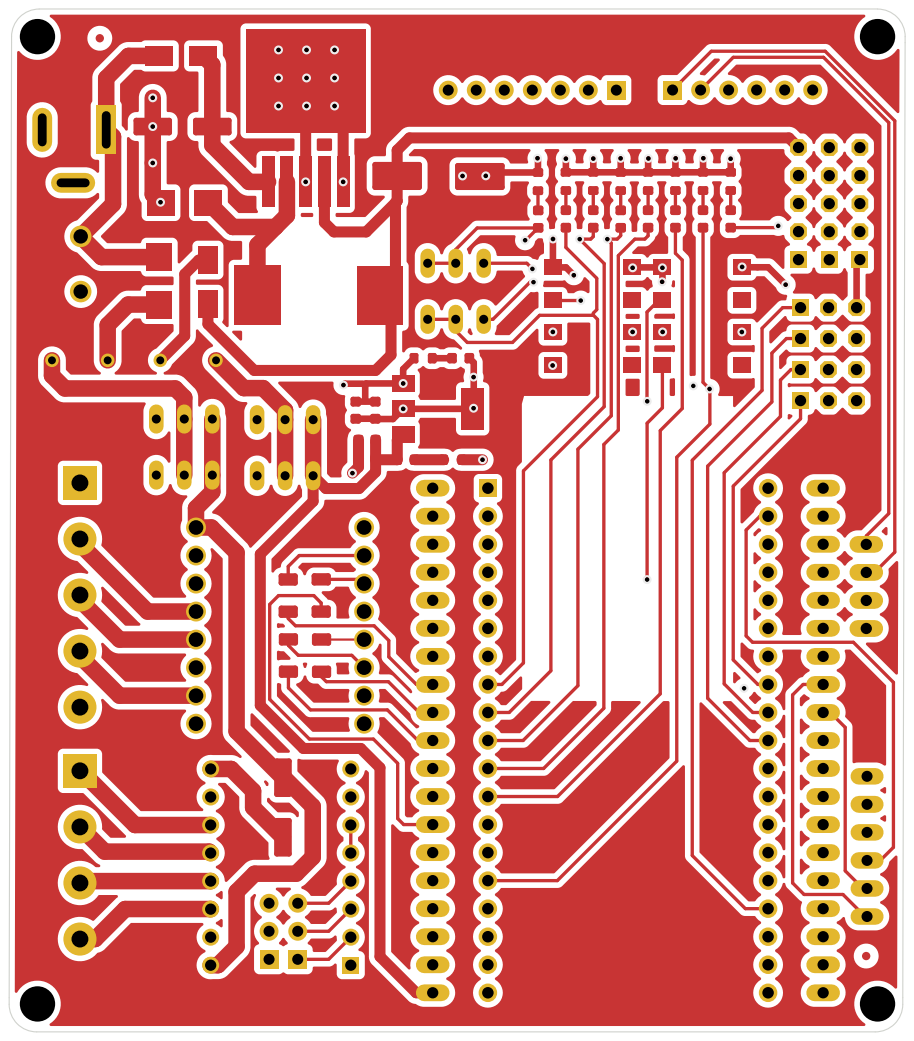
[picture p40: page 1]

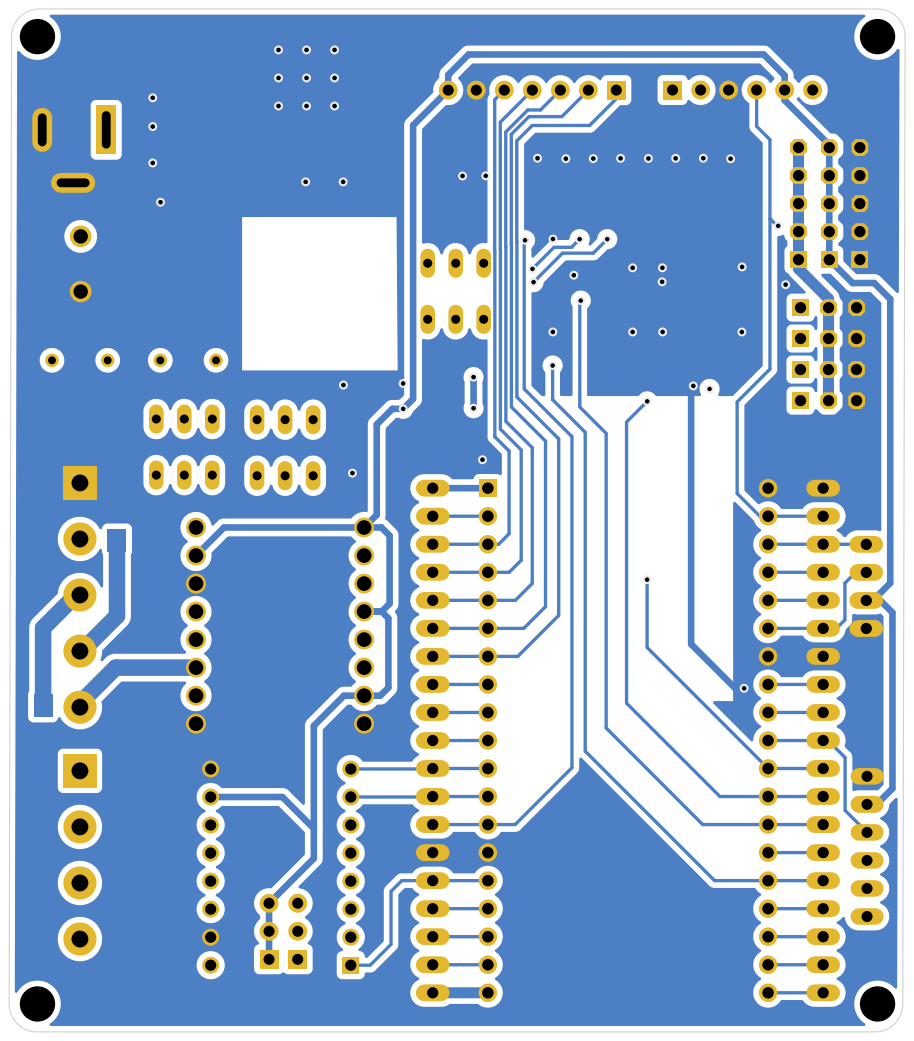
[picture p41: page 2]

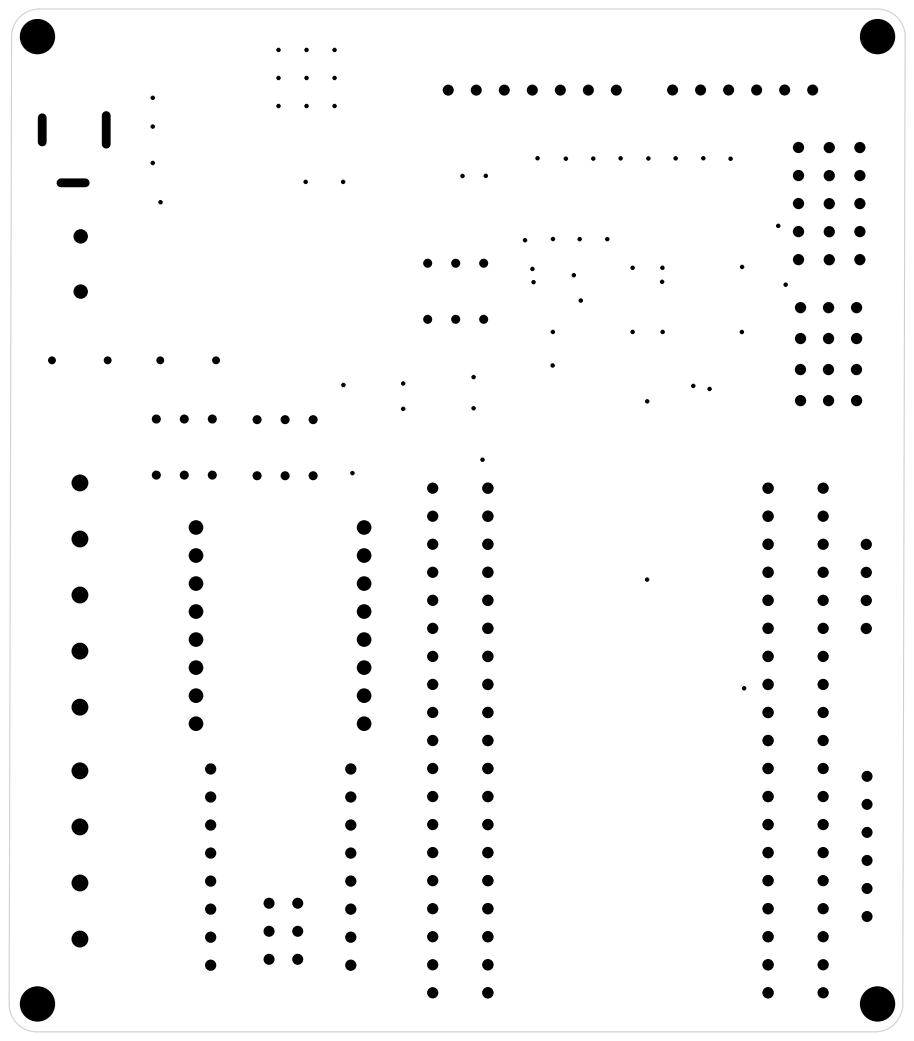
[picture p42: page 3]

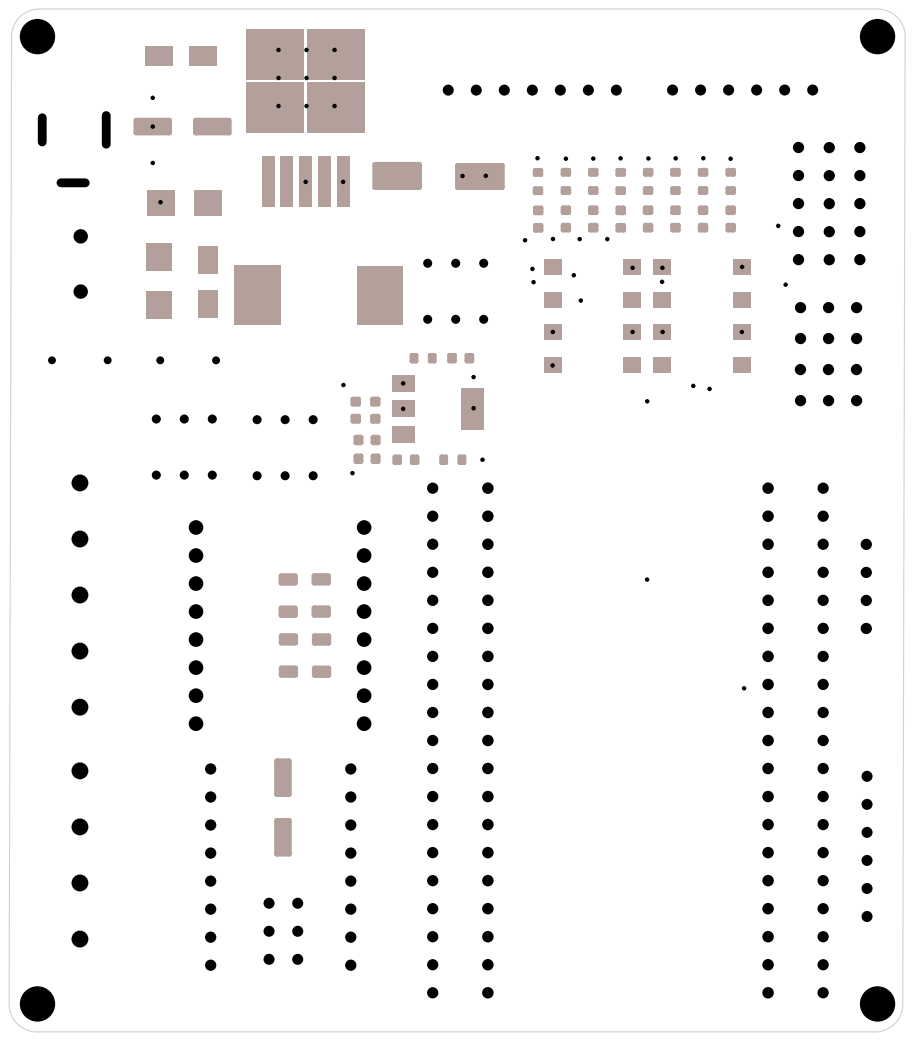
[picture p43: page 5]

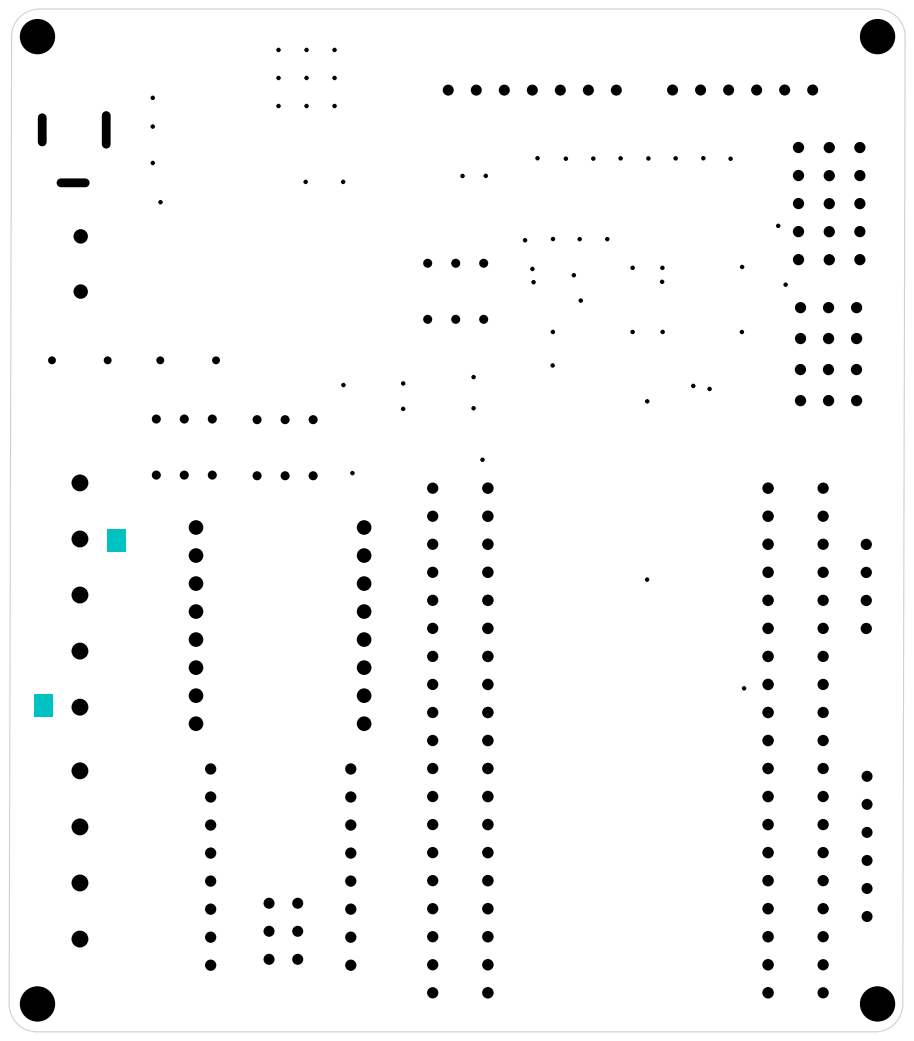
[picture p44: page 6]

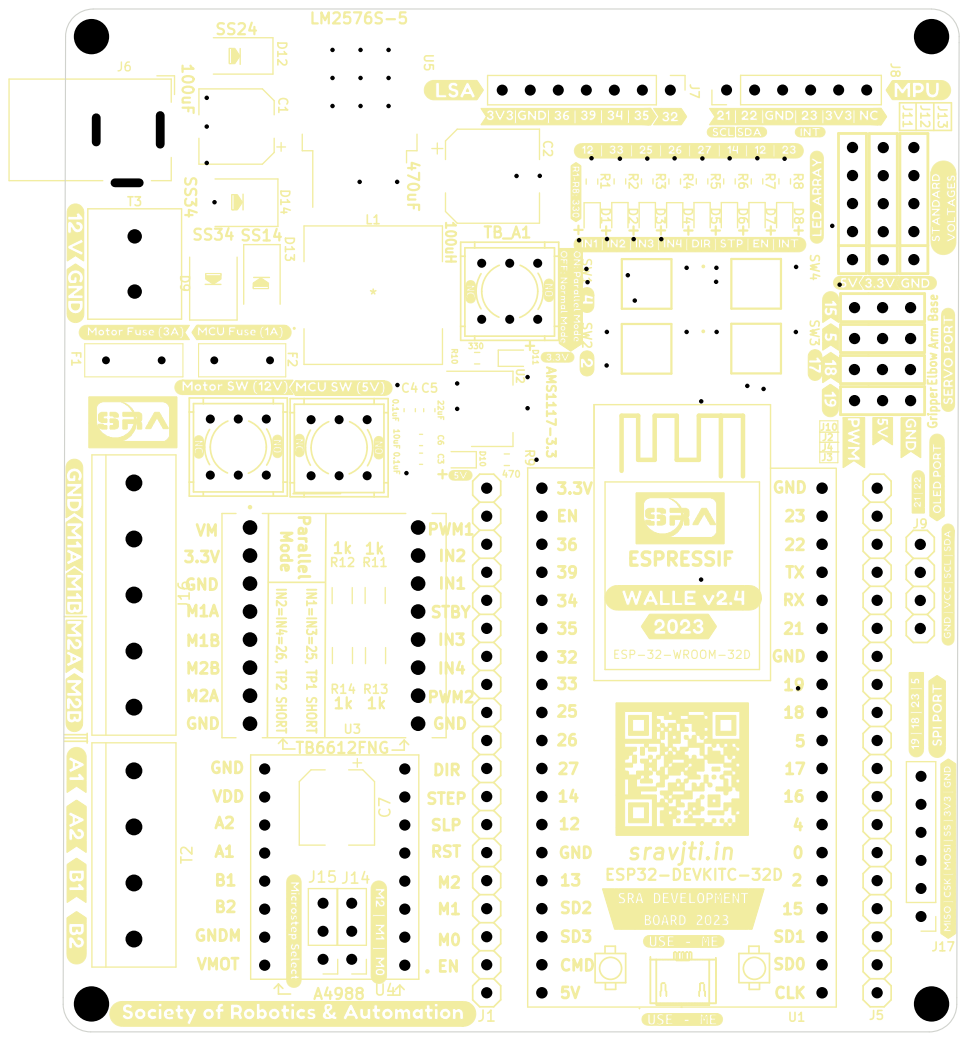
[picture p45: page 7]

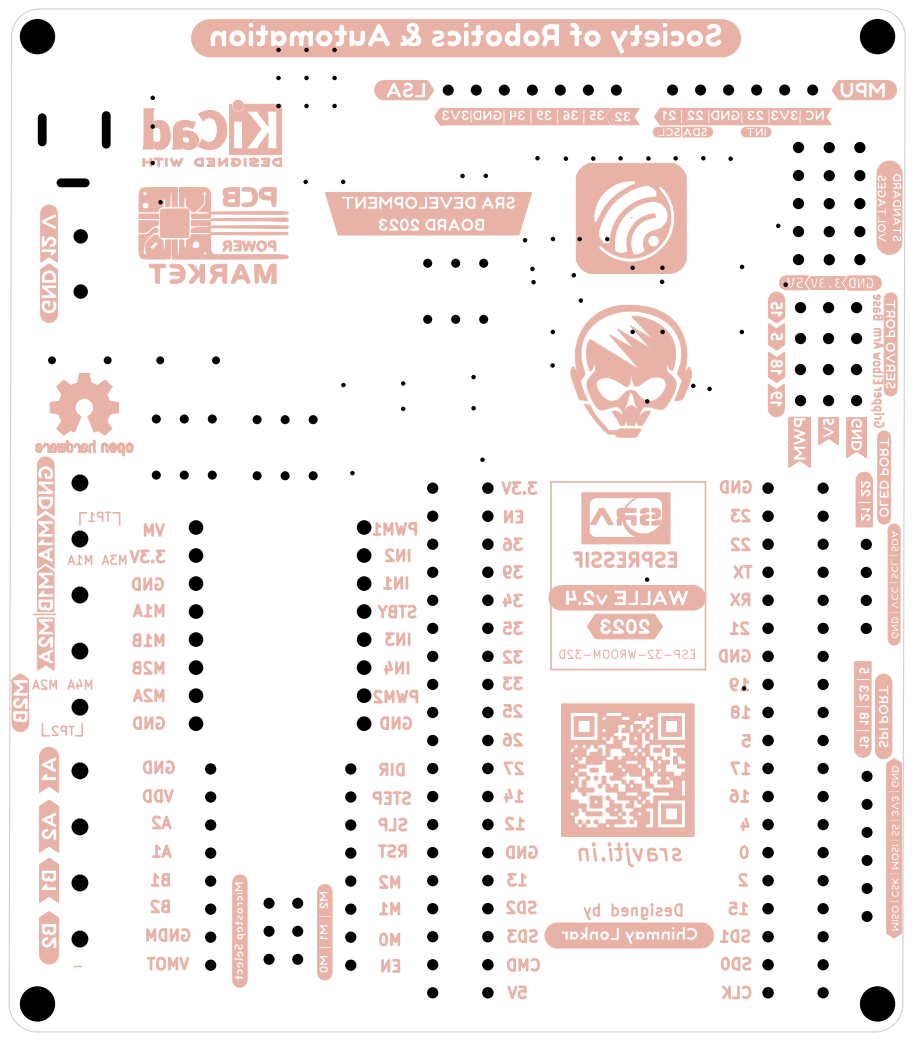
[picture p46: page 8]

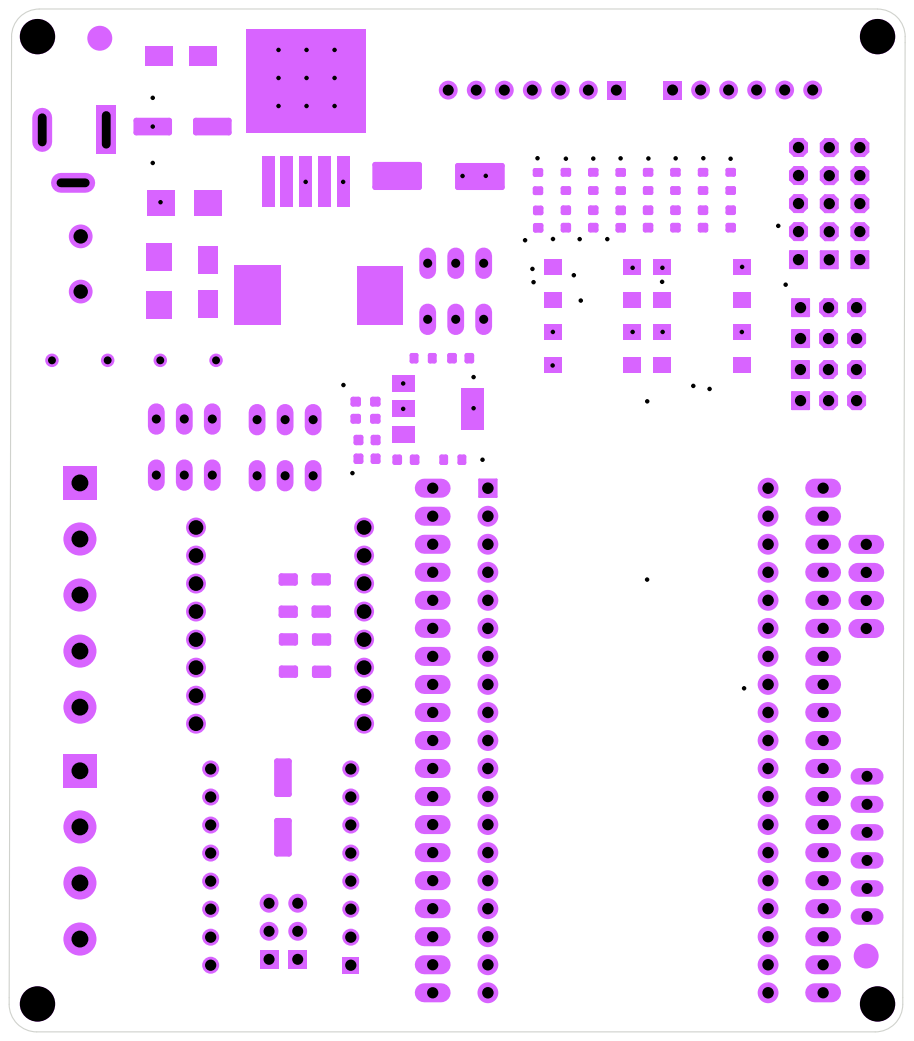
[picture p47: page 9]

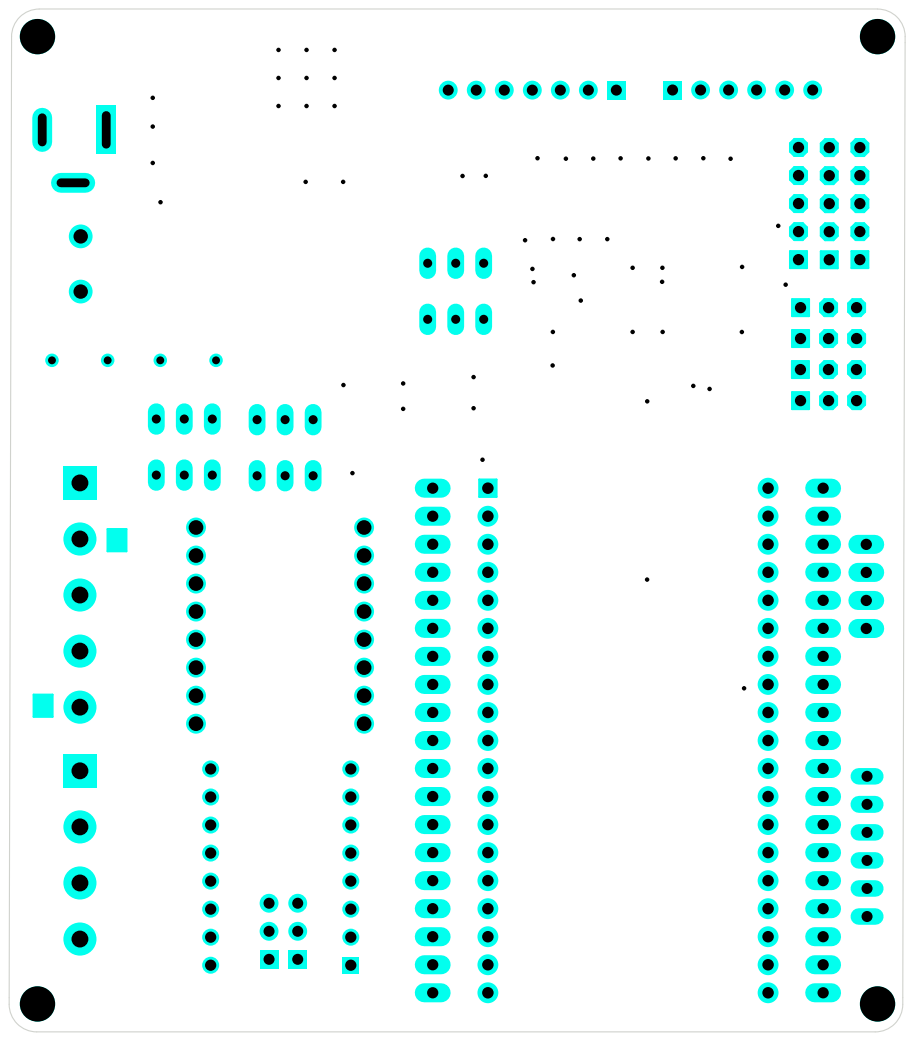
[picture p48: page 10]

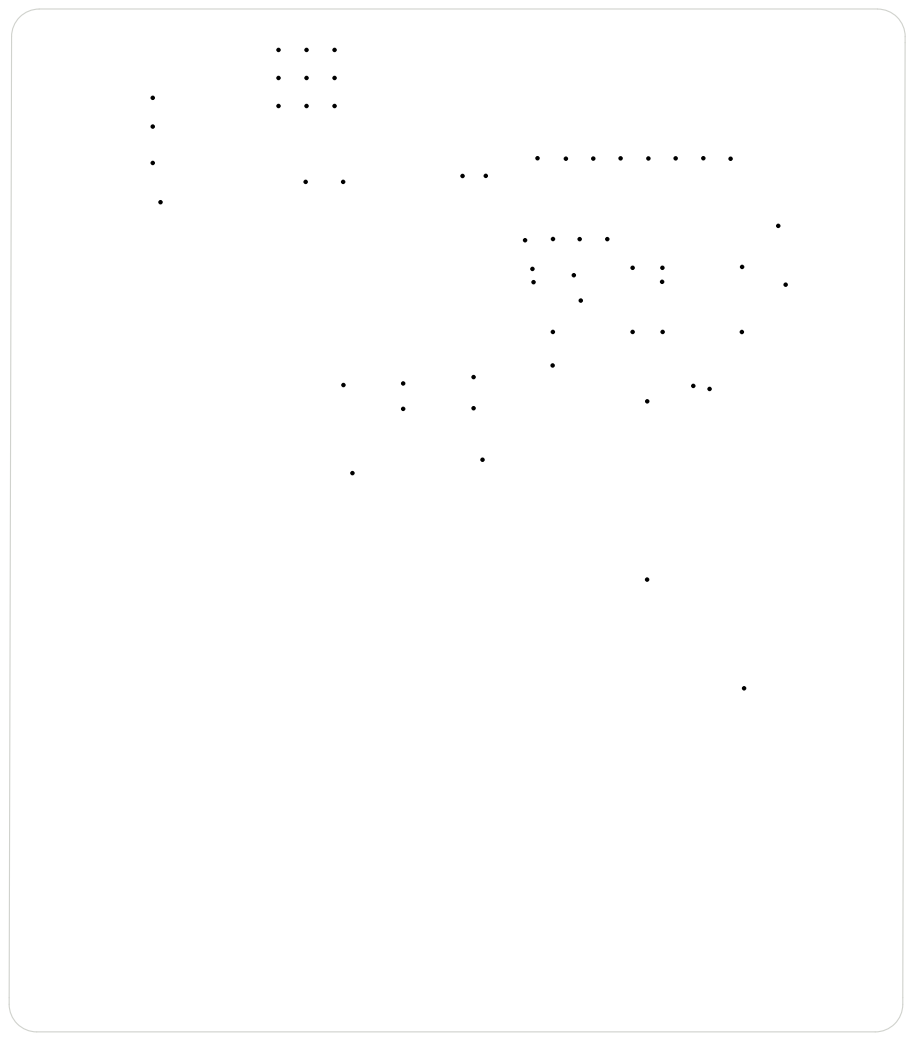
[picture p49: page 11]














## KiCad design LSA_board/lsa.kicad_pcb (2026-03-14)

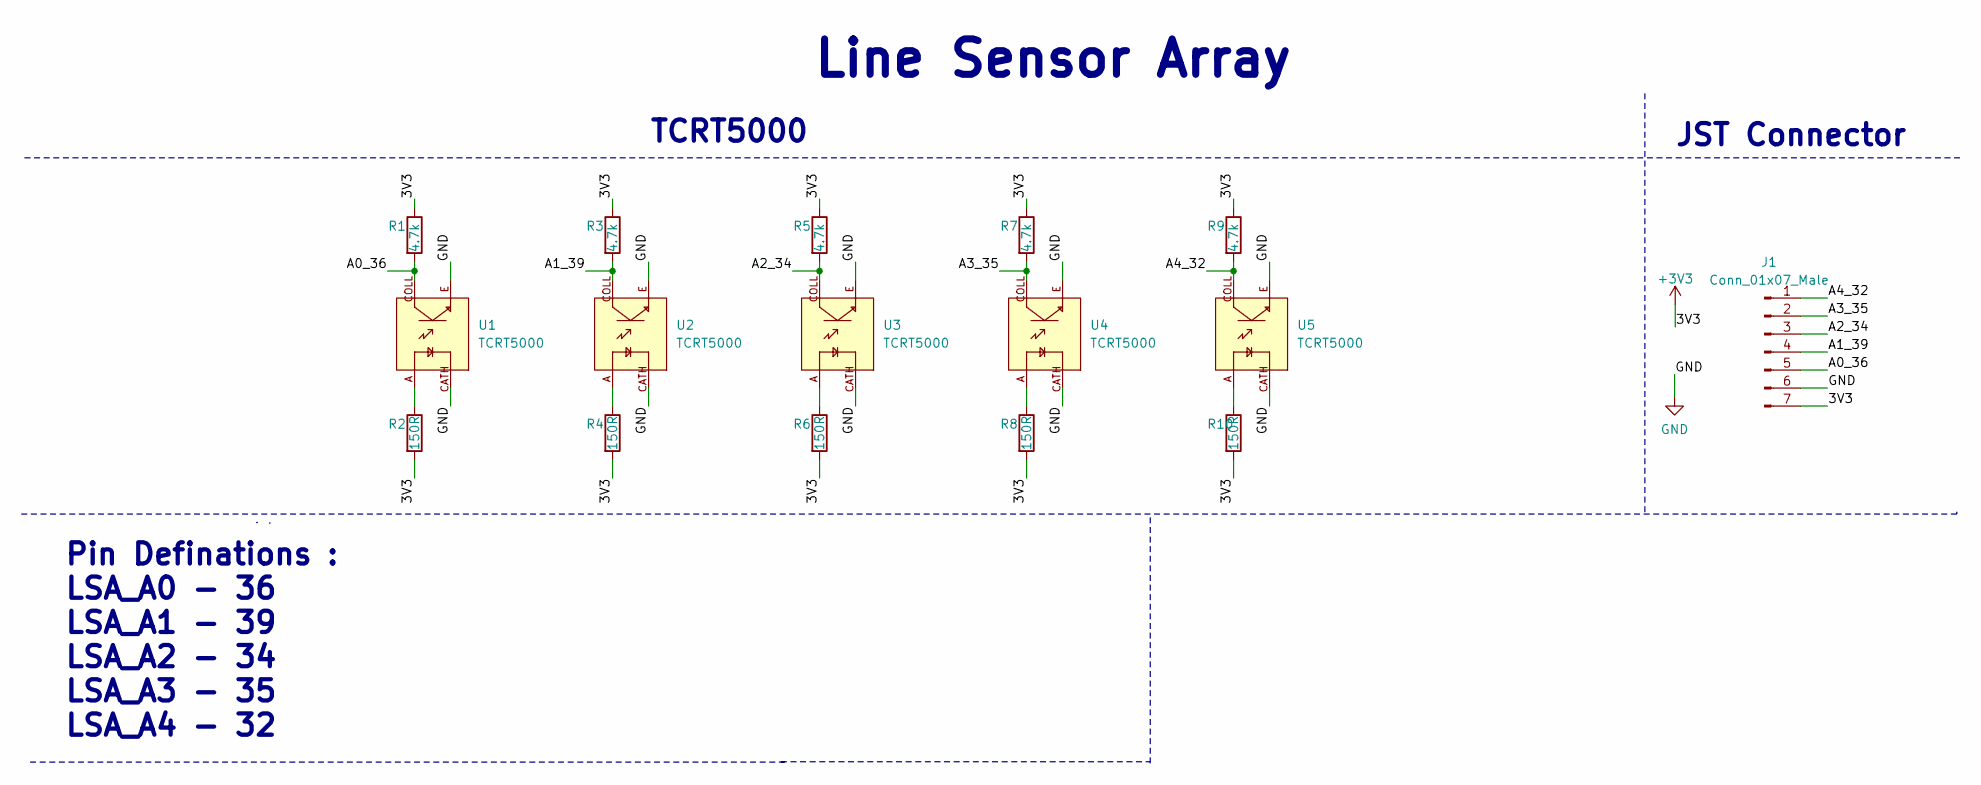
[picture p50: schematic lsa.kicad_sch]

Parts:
J1: Conn_01x07_Male; PinHeader_1x07_P2.54mm_Vertical
R1, R3, R5, R7, R9: 4.7k; R_1206_3216Metric_Pad1.30x1.75mm_HandSolder
R2, R4, R6, R8, R10: 150R; R_1206_3216Metric_Pad1.30x1.75mm_HandSolder
U1, U2, U3, U4, U5: TCRT5000; OPTO_TCRT5000; PARTREV 1.7

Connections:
+3V3: J1.7, R1.1, R2.2, R3.1, R4.2, R5.1, R6.2, R7.1, R8.2, R9.1, R10.2
/A0_36: J1.5, R1.2, U1.COLL
/A1_39: J1.4, R3.2, U2.COLL
/A2_34: J1.3, R5.2, U3.COLL
/A3_35: J1.2, R7.2, U4.COLL
/A4_32: J1.1, R9.2, U5.COLL
GND: J1.6, U1.CATH, U1.E, U2.CATH, U2.E, U3.CATH, U3.E, U4.CATH, U4.E, U5.CATH, U5.E
unnamed: R2.1, U1.A
unnamed: R4.1, U2.A
unnamed: R6.1, U3.A
unnamed: R8.1, U4.A
unnamed: R10.1, U5.A

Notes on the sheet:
JST Connector
Line Sensor Array
TCRT5000
Pin Definations : LSA_A0 - 36 LSA_A1 - 39 LSA_A2 - 34 LSA_A3 - 35 LSA_A4 - 32

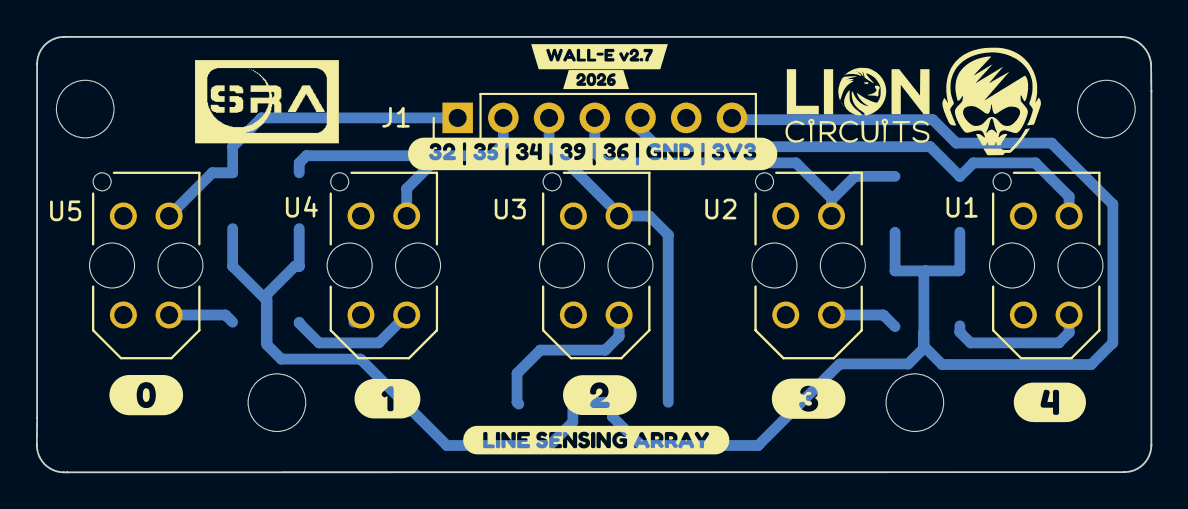
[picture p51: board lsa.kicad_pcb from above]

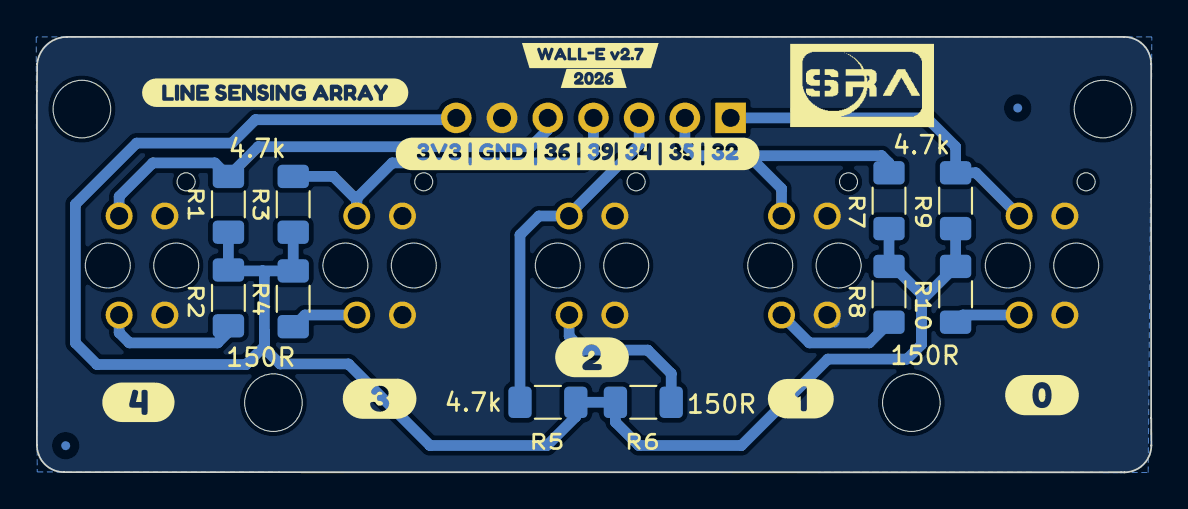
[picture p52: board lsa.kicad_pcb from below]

Board: 2 copper layers, 61.9 x 24.2 mm, 34 parts (19 on the bottom side), 12 nets.

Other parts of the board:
kibuzzard-68E92CD3, kibuzzard-68E92CD3#2: G***; kibuzzard-68E92CD3
kibuzzard-68E92CE3, kibuzzard-68E92CE3#2: G***; kibuzzard-68E92CE3
kibuzzard-672CF9E4, kibuzzard-672CF9E4#2: G***; kibuzzard-672CF9E4
kibuzzard-6394EC2D: G***; kibuzzard-6394EC2D
kibuzzard-63708C00: G***; kibuzzard-63708C00
kibuzzard-63708D58, kibuzzard-63708D58#2: G***; kibuzzard-63708D58
kibuzzard-63708D75, kibuzzard-63708D75#2: G***; kibuzzard-63708D75
kibuzzard-63708D85, kibuzzard-63708D85#2: G***; kibuzzard-63708D85
kibuzzard-63708DAF, kibuzzard-63708DAF#2: G***; kibuzzard-63708DAF
kibuzzard-63708DBF, kibuzzard-63708DBF#2: G***; kibuzzard-63708DBF

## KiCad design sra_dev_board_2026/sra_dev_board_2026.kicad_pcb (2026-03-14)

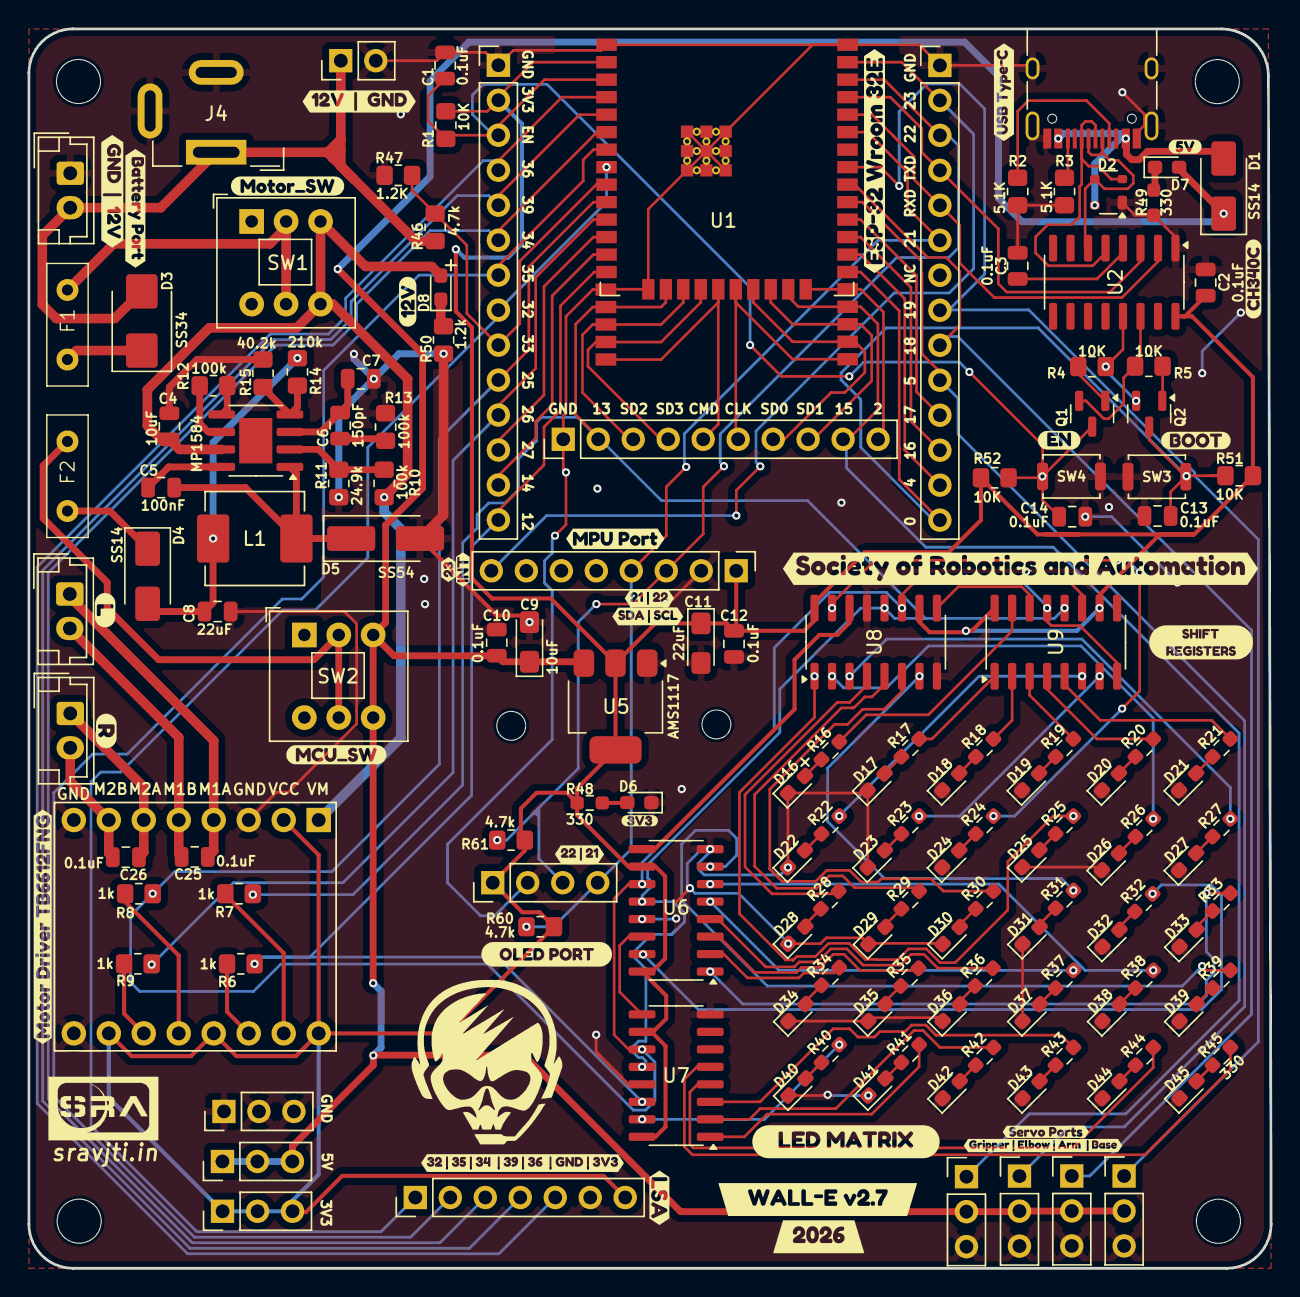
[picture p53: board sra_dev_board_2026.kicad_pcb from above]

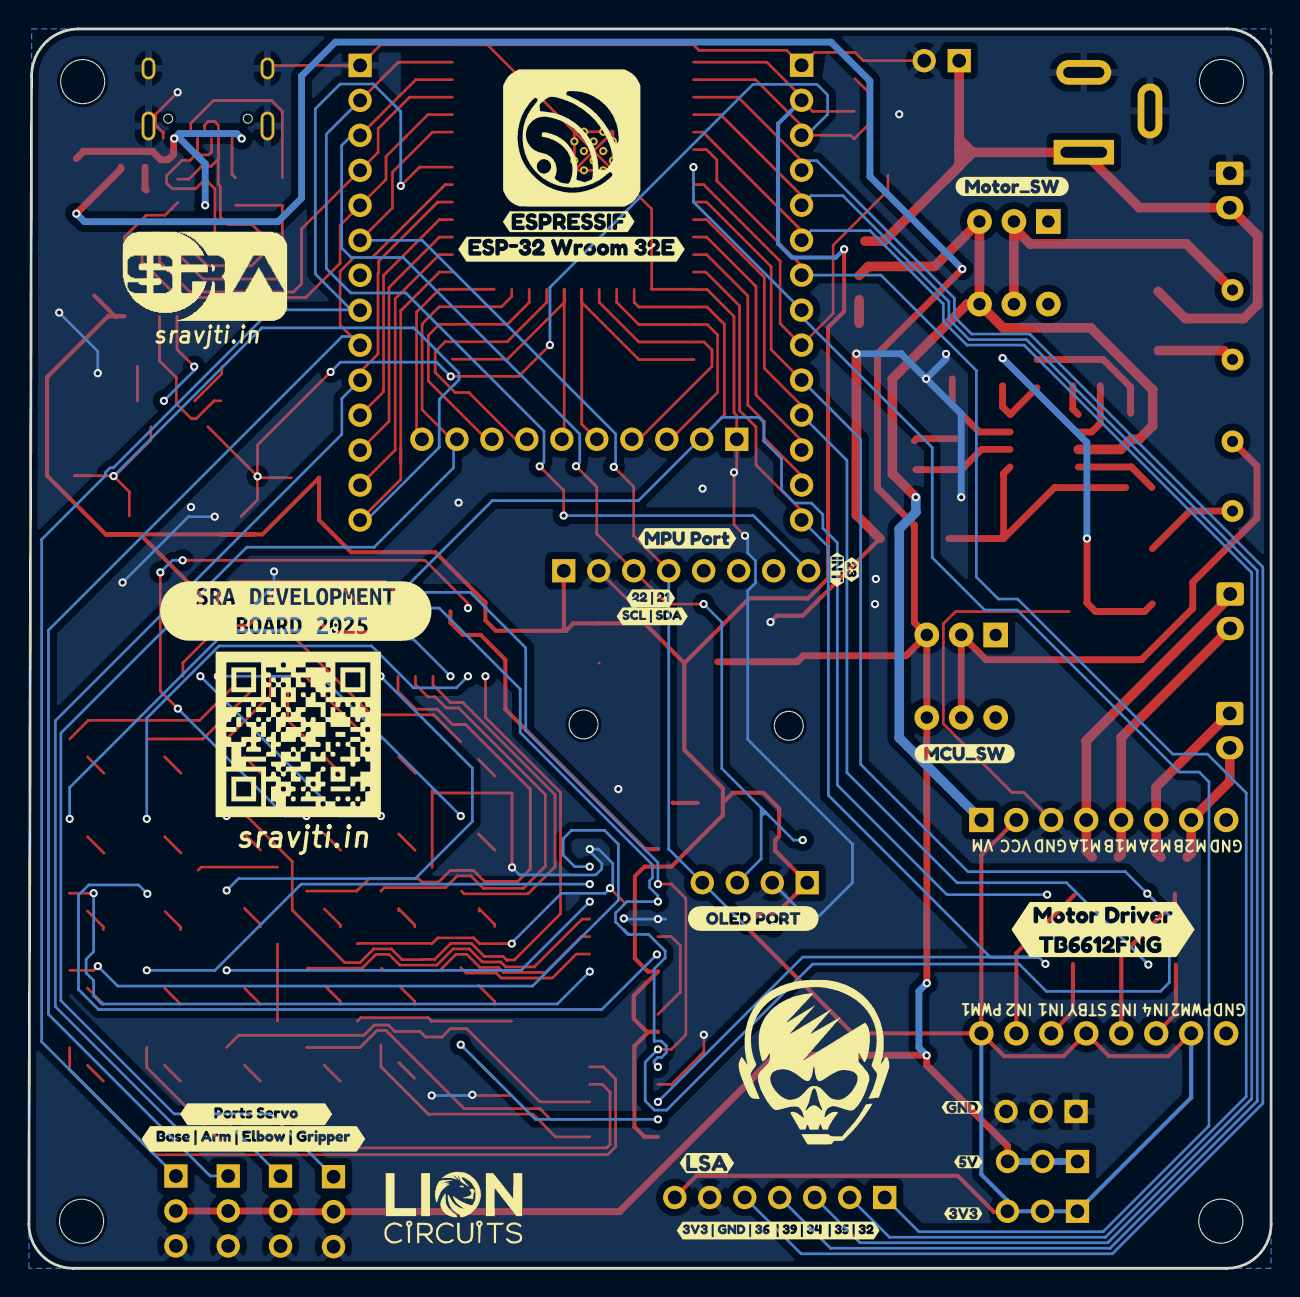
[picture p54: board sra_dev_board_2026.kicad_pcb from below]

Board: 2 copper layers, 90.2 x 90.0 mm, 202 parts (19 on the bottom side), 134 nets.

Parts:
C1, C2, C3, C10, C12, C13, C14, C25, C26: 0.1uF; C_0805_2012Metric
C4: 10uF; C_0805_2012Metric
C5: 100nF; C_0805_2012Metric
C6: 150pF; C_0805_2012Metric
C7: NS; C_0805_2012Metric
C8: 22uF; C_0805_2012Metric
C9: 10uF; CP_EIA-3216-10_Kemet-I_HandSolder
C11: 22uF; CP_EIA-3216-10_Kemet-I_HandSolder
D1, D4: SS14; D_SMA
D2: SP0503BAHT; SOT-143
D3: SS34; D_SMB
D5: D_Schottky; D_SMA_Handsoldering
D6, D7, D8, D16, D17, D18, D19, D20, D21, D22, D23, D24, D25, D26, D27, D28, D29, D30, D31, D32, D33, D34, D35, D36, D37, D38, D39, D40, D41, D42, D43, D44, D45: LED; LED_0603_1608Metric_Pad1.05x0.95mm_HandSolder
F1: 3A; Fuse_Littelfuse-LVR100
F2: 1A; Fuse_Littelfuse-LVR100
H1, H2, H3, H4: MountingHole; MountingHole_3.2mm_M3
H5, H6: MountingHole; MountingHole_2.1mm
J1: USB_C_Receptacle_USB2.0_16P; USB_C_Receptacle_GCT_USB4105-xx-A_16P_TopMnt_Horizontal
J2, J3, J6: B2B-XH-A_LF__SN_; JST_EH_B2B-EH-A_1x02_P2.50mm_Vertical
J4: Barrel_Jack_Switch; BarrelJack_Wuerth_6941xx301002
J5: Screw_Terminal_01x02; PinHeader_1x02_P2.54mm_Vertical
J7, J8, J9, J10: Conn_01x03_Male; PinHeader_1x03_P2.54mm_Vertical
J11: Conn_01x08_Female; PinHeader_1x08_P2.54mm_Vertical
J12: Conn_01x04_Female; PinHeader_1x04_P2.54mm_Vertical
J13: Conn_01x07_JST; PinHeader_1x07_P2.54mm_Vertical
J14, J15: Conn_01x14; PinHeader_1x14_P2.54mm_Vertical
J16: Conn_01x10; PinHeader_1x10_P2.54mm_Vertical
J20, J21, J22: Conn_01x03_Pin; PinHeader_1x03_P2.54mm_Vertical
L1: 15uH; L_Sunlord_MWSA0603S
Q1, Q2: SS8050; SOT-23
R1, R4, R5, R51, R52: 10K; R_0805_2012Metric_Pad1.20x1.40mm_HandSolder
R2, R3: 5.1K; R_0805_2012Metric_Pad1.20x1.40mm_HandSolder
R6, R7, R8, R9: 1k; R_0805_2012Metric_Pad1.20x1.40mm_HandSolder
R10, R12, R13: 100k; R_0805_2012Metric_Pad1.20x1.40mm_HandSolder
R11: 24.9k; R_0805_2012Metric_Pad1.20x1.40mm_HandSolder
R14: 210k; R_0805_2012Metric_Pad1.20x1.40mm_HandSolder
R15: 40.2k; R_0805_2012Metric_Pad1.20x1.40mm_HandSolder
R16, R17, R18, R19, R20, R21, R22, R23, R24, R25, R26, R27, R28, R29, R30, R31, R32, R33, R34, R35, R36, R37, R38, R39, R40, R41, R42, R43, R44, R45, R48, R49: 330; R_0603_1608Metric_Pad0.98x0.95mm_HandSolder
R46, R60, R61: 4.7k; R_0805_2012Metric_Pad1.20x1.40mm_HandSolder
R47: 1.2K; R_0805_2012Metric_Pad1.20x1.40mm_HandSolder
R50: 1.2k; R_0805_2012Metric_Pad1.20x1.40mm_HandSolder
SW1, SW2: SW_Push_DPDT; SW_Push_2P2T_Toggle_CK_PVA2OAH5xxxxxxV2
SW3: SW_0; SW_Push_SPST_NO_Alps_SKRK
SW4: SW_EN; SW_Push_SPST_NO_Alps_SKRK
U1: ESP32-WROOM-32E
U2: CH340C; SOIC-16_3.9x9.9mm_P1.27mm
U3: TB6612FNG H-bridge Motor Driver; TB6612FNG
U4: MP1584; SOIC-8-1EP_3.9x4.9mm_P1.27mm_EP2.41x3.3mm
U5: AMS1117-3.3; SOT-223-3_TabPin2
U6, U7, U8, U9: 74HC595; SOIC-16_3.9x9.9mm_P1.27mm
kibuzzard-66CD8CDE: G***; kibuzzard-66CD8CDE
kibuzzard-66CD901B: G***; kibuzzard-66CD901B
kibuzzard-66CF86D1, kibuzzard-66CF86D1#2: G***; kibuzzard-66CF86D1
kibuzzard-66CF86E5, kibuzzard-66CF86E5#2: G***; kibuzzard-66CF86E5
kibuzzard-66D06F4C: G***; kibuzzard-66D06F4C
kibuzzard-66D06F54: G***; kibuzzard-66D06F54
kibuzzard-66D06403: G***; kibuzzard-66D06403
kibuzzard-66D58886: G***; kibuzzard-66D58886
kibuzzard-67A02922: G***; kibuzzard-67A02922
kibuzzard-68E7F7FE: G***; kibuzzard-68E7F7FE
kibuzzard-68E7F8BB: G***; kibuzzard-68E7F8BB
kibuzzard-68E7F8DA: G***; kibuzzard-68E7F8DA
kibuzzard-68E7F82B: G***; kibuzzard-68E7F82B
kibuzzard-68E7F907: G***; kibuzzard-68E7F907
kibuzzard-68F853B4: G***; kibuzzard-68F853B4
kibuzzard-68F85563: G***; kibuzzard-68F85563
kibuzzard-68F85801: G***; kibuzzard-68F85801
kibuzzard-658F2C3C, kibuzzard-658F2C3C#2: G***; kibuzzard-658F2C3C
kibuzzard-658F2C13, kibuzzard-658F2C13#2: G***; kibuzzard-658F2C13
kibuzzard-668D4F46, kibuzzard-668D4F46#2: G***; kibuzzard-668D4F46
kibuzzard-668D4F81, kibuzzard-668D4F81#2: G***; kibuzzard-668D4F81
kibuzzard-668FE423: G***; kibuzzard-668FE423
kibuzzard-668FF9B2, kibuzzard-668FF9B2#2: G***; kibuzzard-668FF9B2
kibuzzard-675FD791: G***; kibuzzard-675FD791
kibuzzard-675FDA6A: G***; kibuzzard-675FDA6A
kibuzzard-675FE5A8: G***; kibuzzard-675FE5A8
kibuzzard-675FE5B2: G***; kibuzzard-675FE5B2
kibuzzard-675FF2F7: G***; kibuzzard-675FF2F7
kibuzzard-675FF39E: G***; kibuzzard-675FF39E
kibuzzard-6774F3BB: G***; kibuzzard-6774F3BB
kibuzzard-6774F4AA: G***; kibuzzard-6774F4AA
kibuzzard-6774F4AE: G***; kibuzzard-6774F4AE
kibuzzard-66914CE9: G***; kibuzzard-66914CE9
kibuzzard-67602C35: G***; kibuzzard-67602C35
kibuzzard-67602E60: G***; kibuzzard-67602E60
kibuzzard-67602E69: G***; kibuzzard-67602E69
kibuzzard-67704C04: G***; kibuzzard-67704C04
kibuzzard-67704CCE: G***; kibuzzard-67704CCE
kibuzzard-67704CDF: G***; kibuzzard-67704CDF
kibuzzard-67704CF4: G***; kibuzzard-67704CF4
kibuzzard-67715A02: G***; kibuzzard-67715A02
kibuzzard-677158DD: G***; kibuzzard-677158DD
kibuzzard-66921043: G***; kibuzzard-66921043
kibuzzard-66923428: G***; kibuzzard-66923428

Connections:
/0: C13.2, J15.14, Q2.3, R51.1, SW3.2, U1.25 (IO0)
/2: J16.10, U1.24 (IO2)
/3V3: C2.1, C11.1, C12.1, J11.1, J12.1, J13.7, J14.2, J22.1, J22.2, J22.3, R1.2, R48.2, R51.2, R52.2, R60.1, R61.1, U1.2 (VDD), U2.16 (VCC), U3.2 (VCC), U3.10 (PWMB), U3.13 (STBY), U3.16 (PWMA), U5.2 (VO), U6.10 (~SRCLR), U6.16 (VCC), U7.10 (~SRCLR), U7.16 (VCC), U8.10 (~SRCLR), U8.16 (VCC), U9.10 (~SRCLR), U9.16 (VCC)
/4: J15.13, U1.26 (IO4)
/5: J8.1, J15.10, U1.29 (IO5)
/5V: C8.1, D4.2 (A), L1.2, R14.1
/5V_P: C9.1, C10.1, D1.1 (K), D7.2 (A), J7.2, J8.2, J9.2, J10.2, J21.1, J21.2, J21.3, SW2.3 (C), SW2.6 (C), U5.3 (VI)
/12: J14.14, R6.1, U1.14 (IO12), U7.14 (SER)
/12V: D3.2 (A), J4.1, J5.1, J6.2, R46.1
/12V_P: C4.1, D8.2 (A), R10.1, SW1.3 (C), SW1.6 (C), U3.1 (VM), U4.7 (VIN)
/13: J16.2, R7.1, U1.16 (IO13), U6.12 (RCLK), U7.12 (RCLK), U8.12 (RCLK), U9.12 (RCLK)
/14: J14.13, U1.13 (IO14)
/15: J7.1, J16.9, U1.23 (IO15)
/16: J15.12, U1.27 (IO16)
/17: J15.11, U1.28 (IO17)
/18: J9.1, J15.9, U1.30 (IO18)
/19: J10.1, J15.8, U1.31 (IO19)
/21: J11.4, J12.4, J15.6, R60.2, U1.33 (IO21)
/22: J11.3, J12.3, J15.3, R61.2, U1.36 (IO22)
/23: J11.8, J15.2, U1.37 (IO23)
/25: J14.10, R8.1, U1.10 (IO25), U6.11 (SRCLK), U7.11 (SRCLK), U8.11 (SRCLK), U9.11 (SRCLK)
/26: J14.11, R9.1, U1.11 (IO26)
/27: J14.12, U1.12 (IO27)
/32: J13.1, J14.8, U1.8 (IO32)
/33: J14.9, R46.2, R47.2, U1.9 (IO33)
/34: J13.3, J14.6, U1.6 (IO34)
/35: J13.2, J14.7, U1.7 (IO35)
/36: J13.5, J14.4, U1.4 (SENSOR_VP)
/39: J13.4, J14.5, U1.5 (SENSOR_VN)
/CLK: J16.6, U1.20 (NC)
/CMD: J16.5, U1.19 (NC)
/D+: D2.2 (K), J1.A6 (D+), J1.B6 (D+), U2.5 (UD+)
/D-: D2.3 (K), J1.A7 (D-), J1.B7 (D-), U2.6 (UD-)
/EN: C1.1, C14.2, J14.3, Q1.3, R1.1, R52.1, SW4.2, U1.3 (EN)
/EN_SR: R10.2, R11.1, U4.2 (EN)
/FB: R14.2, R15.1, U4.4 (FB)
/M1A: C25.1, J3.1, U3.4 (A01)
/M1B: C25.2, J3.2, U3.5 (A02)
/M2A: C26.1, J2.1, U3.6 (B02)
/M2B: C26.2, J2.2, U3.7 (B01)
/RXD: J15.5, U1.34 (RXD0/IO3), U2.2 (TXD)
/SD0: J16.7, U1.21 (NC)
/SD1: J16.8, U1.22 (NC)
/SD2: J16.3, U1.17 (NC)
/SD3: J16.4, U1.18 (NC)
/TXD: J15.4, U1.35 (TXD0/IO1), U2.3 (RXD)
/VBUS: D1.2 (A), D2.4 (K), J1.A4 (VBUS), J1.A9 (VBUS), J1.B4 (VBUS), J1.B9 (VBUS)
/lm1: R16.2, U9.15 (QA)
/lm2: R17.2, U9.1 (QB)
/lm3: R18.2, U9.2 (QC)
/lm4: R19.2, U9.3 (QD)
/lm5: R20.2, U9.4 (QE)
/lm6: R21.2, U9.5 (QF)
/lm7: R22.2, U9.6 (QG)
/lm8: R23.2, U9.7 (QH)
/lm9: R24.2, U8.15 (QA)
/lm10: R25.2, U8.1 (QB)
/lm11: R26.2, U8.2 (QC)
/lm12: R27.2, U8.3 (QD)
/lm13: R28.2, U8.4 (QE)
/lm14: R29.2, U8.5 (QF)
/lm15: R30.2, U8.6 (QG)
/lm16: R31.2, U8.7 (QH)
/lm17: R32.2, U6.15 (QA)
/lm18: R33.2, U6.1 (QB)
/lm19: R34.2, U6.2 (QC)
/lm20: R35.2, U6.3 (QD)
/lm21: R36.2, U6.4 (QE)
/lm22: R37.2, U6.5 (QF)
/lm23: R38.2, U6.6 (QG)
/lm24: R39.2, U6.7 (QH)
/lm25: R40.2, U7.15 (QA)
/lm26: R41.2, U7.1 (QB)
/lm27: R42.2, U7.2 (QC)
/lm28: R43.2, U7.3 (QD)
/lm29: R44.2, U7.4 (QE)
/lm30: R45.2, U7.5 (QF)
/sr2: U6.14 (SER), U7.9 (QH')
/sr3: U6.9 (QH'), U8.14 (SER)
/sr4: U8.9 (QH'), U9.14 (SER)
/~DTR: Q2.2, R4.1, U2.13 (~DTR)
/~RTS: Q1.2, R5.1, U2.14 (~RTS)
GND: C1.2, C2.2, C3.2, C4.2, C7.2, C8.2, C9.2, C10.2, C11.2, C12.2, C13.1, C14.1, D2.1 (A), D5.2 (A), D6.1 (K), D16.1 (K), D17.1 (K), D18.1 (K), D19.1 (K), D20.1 (K), D21.1 (K), D22.1 (K), D23.1 (K), D24.1 (K), D25.1 (K), D26.1 (K), D27.1 (K), D28.1 (K), D29.1 (K), D30.1 (K), D31.1 (K), D32.1 (K), D33.1 (K), D34.1 (K), D35.1 (K), D36.1 (K), D37.1 (K), D38.1 (K), D39.1 (K), D40.1 (K), D41.1 (K), D42.1 (K), D43.1 (K), D44.1 (K), D45.1 (K), J1.A1 (GND), J1.A12 (GND), J1.B1 (GND), J1.B12 (GND), J1.S1 (SHIELD), J4.2, J4.3, J5.2, J6.1, J7.3, J8.3, J9.3, J10.3, J11.2, J12.2, J13.6, J14.1, J15.1, J16.1, J20.1, J20.2, J20.3, R2.2, R3.2, R11.2, R12.2, R13.2, R15.2, R47.1, R49.1, R50.1, SW3.1, SW4.1, U1.1 (GND), U1.15 (GND), U1.38 (GND), U1.39 (GND), U2.1 (GND), U3.3 (GND), U3.8 (GND), U3.9 (GND), U4.5 (GND), U5.1 (GND), U6.8 (GND), U6.13 (~OE), U7.8 (GND), U7.13 (~OE), U8.8 (GND), U8.13 (~OE), U9.8 (GND), U9.13 (~OE)
unnamed: C6.2, R13.1
unnamed: D3.1 (K), F1.1
unnamed: D4.1 (K), F2.1
unnamed: C5.2, D5.1 (K), L1.1, U4.1 (SW)
unnamed: D6.2 (A), R48.1
unnamed: D7.1 (K), R49.2
unnamed: D8.1 (K), R50.2
unnamed: D16.2 (A), R16.1
unnamed: D17.2 (A), R17.1
unnamed: D18.2 (A), R18.1
unnamed: D19.2 (A), R19.1
unnamed: D20.2 (A), R20.1
unnamed: D21.2 (A), R21.1
unnamed: D22.2 (A), R22.1
unnamed: D23.2 (A), R23.1
unnamed: D24.2 (A), R24.1
unnamed: D25.2 (A), R25.1
unnamed: D26.2 (A), R26.1
unnamed: D27.2 (A), R27.1
unnamed: D28.2 (A), R28.1
unnamed: D29.2 (A), R29.1
unnamed: D30.2 (A), R30.1
unnamed: D31.2 (A), R31.1
unnamed: D32.2 (A), R32.1
unnamed: D33.2 (A), R33.1
unnamed: D34.2 (A), R34.1
unnamed: D35.2 (A), R35.1
unnamed: D36.2 (A), R36.1
unnamed: D37.2 (A), R37.1
unnamed: D38.2 (A), R38.1
unnamed: D39.2 (A), R39.1
unnamed: D40.2 (A), R40.1
unnamed: D41.2 (A), R41.1
unnamed: D42.2 (A), R42.1
unnamed: D43.2 (A), R43.1
unnamed: D44.2 (A), R44.1
unnamed: D45.2 (A), R45.1
unnamed: F1.2, SW1.2 (B), SW1.5 (B)
unnamed: F2.2, SW2.2 (B), SW2.5 (B)
unnamed: J1.A5 (CC1), R2.1
unnamed: J1.B5 (CC2), R3.1
unnamed: Q1.1, R4.2
unnamed: Q2.1, R5.2
unnamed: C3.1, U2.4 (V3)
unnamed: R6.2, U3.14 (AI1)
unnamed: R7.2, U3.15 (AI2)
unnamed: R8.2, U3.12 (BI1)
unnamed: R9.2, U3.11 (BI2)
unnamed: C5.1, U4.8 (BST)
unnamed: C6.1, C7.1, U4.3 (COMP)
unnamed: R12.1, U4.6 (FREQ)

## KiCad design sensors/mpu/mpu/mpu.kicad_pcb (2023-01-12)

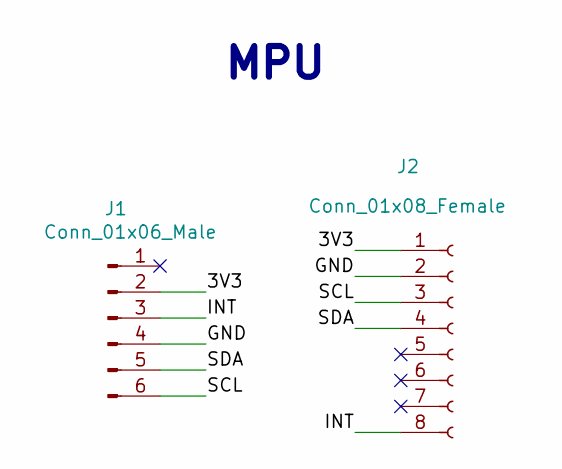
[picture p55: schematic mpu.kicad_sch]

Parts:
J1: Conn_01x06_Male; PinHeader_1x06_P2.54mm_Vertical
J2: Conn_01x08_Female; 1X08

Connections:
/3V3: J1.2, J2.1
/GND: J1.4, J2.2
/INT: J1.3, J2.8
/SCL: J1.6, J2.3
/SDA: J1.5, J2.4

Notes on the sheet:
MPU

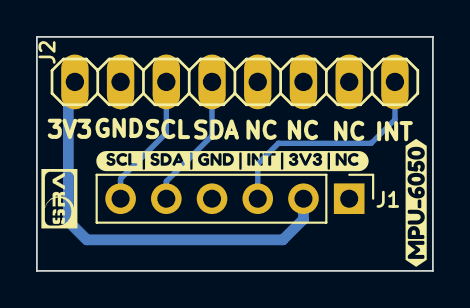
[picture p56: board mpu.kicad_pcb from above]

Board: 2 copper layers, 22.0 x 13.0 mm, 4 parts (0 on the bottom side), 5 nets.

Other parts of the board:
kibuzzard-61F9996D: G***; kibuzzard-61F9996D
kibuzzard-637B8032: G***; kibuzzard-637B8032

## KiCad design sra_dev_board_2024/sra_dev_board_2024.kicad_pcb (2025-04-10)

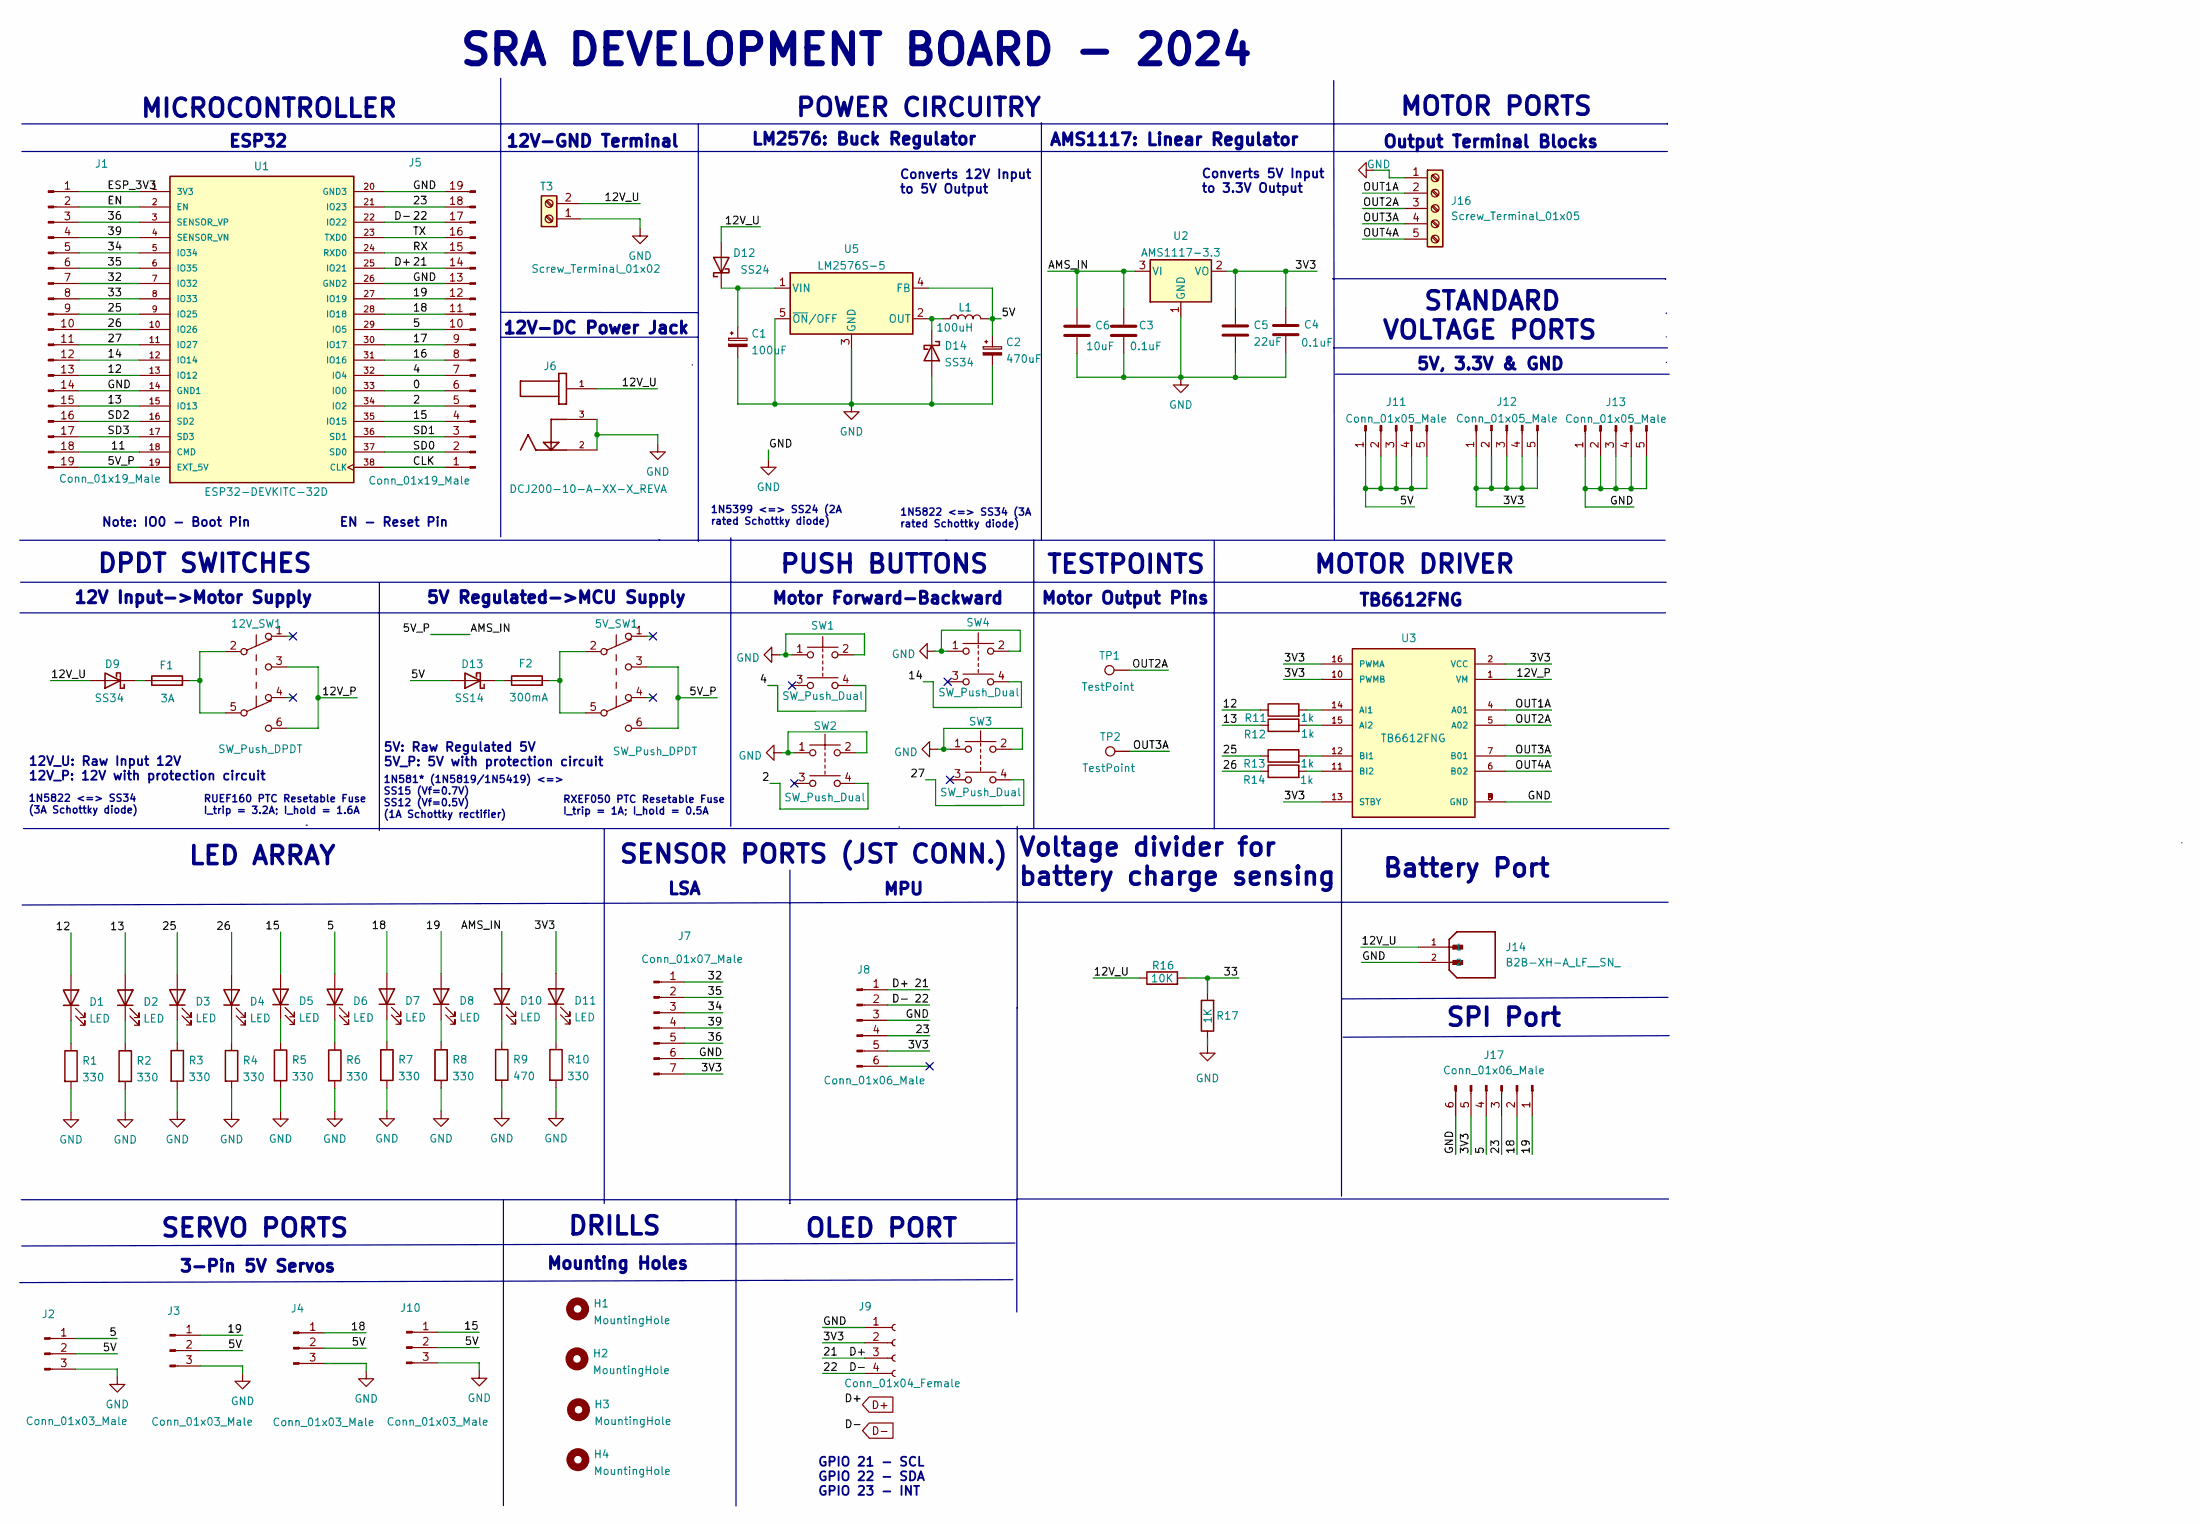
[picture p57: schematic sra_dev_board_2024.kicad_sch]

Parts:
5V_SW1, 12V_SW1: SW_Push_DPDT; dpdt_sw_2x03_tht
C1: 100uF; CP_Elec_6.3x7.7
C2: 470uF; CP_Elec_8x10
C3, C4: 0.1uF; C_0603_1608Metric
C5: 22uF; C_0603_1608Metric
C6: 10uF; C_0603_1608Metric
D1, D2, D3, D4, D5, D6, D7, D8, D10, D11: LED; LED_0603_1608Metric
D9, D14: SS34; D_SMB
D12: SS24; D_SMA
D13: SS14; D_SMA
F1: 3A; RUEF160
F2: 300mA; RXEF050
H1, H2, H3, H4: MountingHole; MountingHole_3.2mm_M3
J1, J5: Conn_01x19_Male; 1X19
J2, J3, J4, J10: Conn_01x03_Male; 1X03
J6: DCJ200-10-A-XX-X_REVA; BarrelJack_Wuerth_6941xx301002
J7: Conn_01x07_Male; PinHeader_1x07_P2.54mm_Vertical
J8, J17: Conn_01x06_Male; PinHeader_1x06_P2.54mm_Vertical
J9: Conn_01x04_Female; 1X04
J11, J12, J13: Conn_01x05_Male; 1X05
J14: B2B-XH-A_LF__SN_; JST_B2B-XH-A_LF__SN_; PARTREV N/A
J16: Screw_Terminal_01x05; TerminalBlock_bornier-5_P5.08mm
L1: 100uH; CDRH127_inductor_smd
R1, R2, R3, R4, R5, R6, R7, R8, R10: 330; R_0603_1608Metric
R9: 470; R_0603_1608Metric
R11, R12, R13, R14: 1k; R_1206_3216Metric
R16: 10K; R_1206_3216Metric
R17: 1K; R_1206_3216Metric
SW1, SW2, SW3, SW4: SW_Push_Dual; spst_tactile_sw_2x02_smd
T3: Screw_Terminal_01x02; 12V_1x02_tht
TP1, TP2: TestPoint; pad_1,27-2,54_smd
U1: ESP32-DEVKITC-32D; ESP32-DEVKITCv4-32D; PARTREV 4
U2: AMS1117-3.3; SOT-223-3_TabPin2
U3: TB6612FNG; TB6612FNG_2; PARTREV 11-13-17
U5: LM2576S-5; TO-263-5_TabPin3

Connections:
/0: J5.6, U1.33 (IO0)
/2: J5.5, SW2.4, U1.34 (IO2)
/3V3: C4.1, C5.1, D11.2 (A), J7.7, J8.5, J9.2, J12.1, J12.2, J12.3, J12.4, J12.5, J17.5, U2.2 (VO), U3.2 (VCC), U3.10 (PWMB), U3.13 (STBY), U3.16 (PWMA)
/4: J5.7, SW1.4, U1.32 (IO4)
/5: D6.2 (A), J2.1, J5.10, J17.4, U1.29 (IO5)
/5V: C2.1, D13.2 (A), J2.2, J3.2, J4.2, J10.2, J11.1, J11.2, J11.3, J11.4, J11.5, L1.2, U5.4 (FB)
/5V_P: 5V_SW1.3 (C), 5V_SW1.6 (C), C3.1, C6.1, D10.2 (A), J1.19, U1.19 (EXT_5V), U2.3 (VI)
/11: J1.18, U1.18 (CMD)
/12: D1.2 (A), J1.13, R11.1, U1.13 (IO12)
/12V_P: 12V_SW1.3 (C), 12V_SW1.6 (C), U3.1 (VM)
/12V_U: D9.2 (A), D12.2 (A), J6.1, J14.1, R16.1, T3.2
/13: D2.2 (A), J1.15, R12.1, U1.15 (IO13)
/14: J1.12, SW4.4, U1.12 (IO14)
/15: D5.2 (A), J5.4, J10.1, U1.35 (IO15)
/16: J5.8, U1.31 (IO16)
/17: J5.9, U1.30 (IO17)
/18: D7.2 (A), J4.1, J5.11, J17.2, U1.28 (IO18)
/19: D8.2 (A), J3.1, J5.12, J17.1, U1.27 (IO19)
/23: J5.18, J8.4, J17.3, U1.21 (IO23)
/25: D3.2 (A), J1.9, R13.1, U1.9 (IO25)
/26: D4.2 (A), J1.10, R14.1, U1.10 (IO26)
/27: J1.11, SW3.4, U1.11 (IO27)
/32: J1.7, J7.1, U1.7 (IO32)
/33: J1.8, R16.2, R17.2, U1.8 (IO33)
/34: J1.5, J7.3, U1.5 (IO34)
/35: J1.6, J7.2, U1.6 (IO35)
/36: J1.3, J7.5, U1.3 (SENSOR_VP)
/39: J1.4, J7.4, U1.4 (SENSOR_VN)
/CLK: J5.1, U1.38 (CLK)
/EN: J1.2, U1.2 (EN)
/ESP_3V3: J1.1, U1.1 (3V3)
/OUT1A: J16.2, U3.4 (A01)
/OUT2A: J16.3, TP1.1, U3.5 (A02)
/OUT3A: J16.4, TP2.1, U3.7 (B01)
/OUT4A: J16.5, U3.6 (B02)
/RX: J5.15, U1.24 (RXD0)
/SD0: J5.2, U1.37 (SD0)
/SD1: J5.3, U1.36 (SD1)
/SD2: J1.16, U1.16 (SD2)
/SD3: J1.17, U1.17 (SD3)
/TX: J5.16, U1.23 (TXD0)
D+: J5.14, J8.1, J9.3, U1.25 (IO21)
D-: J5.17, J8.2, J9.4, U1.22 (IO22)
GND: C1.2, C2.2, C3.2, C4.2, C5.2, C6.2, D14.2 (A), J1.14, J2.3, J3.3, J4.3, J5.13, J5.19, J6.2, J6.3, J7.6, J8.3, J9.1, J10.3, J13.1, J13.2, J13.3, J13.4, J13.5, J14.2, J16.1, J17.6, R1.2, R2.2, R3.2, R4.2, R5.2, R6.2, R7.2, R8.2, R9.2, R10.2, R17.1, SW1.1, SW1.2, SW2.1, SW2.2, SW3.1, SW3.2, SW4.1, SW4.2, T3.1, U1.14 (GND1), U1.20 (GND3), U1.26 (GND2), U2.1 (GND), U3.3 (GND), U3.8 (GND), U3.9 (GND), U5.3 (GND), U5.5 (~ON/OFF)
unnamed: 5V_SW1.2 (B), 5V_SW1.5 (B), F2.2
unnamed: 12V_SW1.2 (B), 12V_SW1.5 (B), F1.2
unnamed: D1.1 (K), R1.1
unnamed: D2.1 (K), R2.1
unnamed: D3.1 (K), R3.1
unnamed: D4.1 (K), R4.1
unnamed: D5.1 (K), R5.1
unnamed: D6.1 (K), R6.1
unnamed: D7.1 (K), R7.1
unnamed: D8.1 (K), R8.1
unnamed: D9.1 (K), F1.1
unnamed: D10.1 (K), R9.1
unnamed: D11.1 (K), R10.1
unnamed: C1.1, D12.1 (K), U5.1 (VIN)
unnamed: D13.1 (K), F2.1
unnamed: D14.1 (K), L1.1, U5.2 (OUT)
unnamed: R11.2, U3.14 (AI1)
unnamed: R12.2, U3.15 (AI2)
unnamed: R13.2, U3.12 (BI1)
unnamed: R14.2, U3.11 (BI2)

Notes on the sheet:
5V, 3.3V & GND
RXEF050 PTC Resetable Fuse I_trip = 1A; I_hold = 0.5A
Mounting Holes
SRA DEVELOPMENT BOARD - 2024
LED ARRAY
12V_U: Raw Input 12V 12V_P: 12V with protection circuit
12V-GND Terminal
1N5822 <=> SS34 (3A rated Schottky diode)
Output Terminal Blocks
LSA
MPU
Converts 5V Input to 3.3V Output
DRILLS
SENSOR PORTS (JST CONN.)
1N5399 <=> SS24 (2A rated Schottky diode)
DPDT SWITCHES
5V: Raw Regulated 5V 5V_P: 5V with protection circuit
Note: IO0 - Boot Pin EN - Reset Pin
POWER CIRCUITRY
ESP32
RUEF160 PTC Resetable Fuse I_trip = 3.2A; I_hold = 1.6A
LM2576: Buck Regulator
MICROCONTROLLER
Battery Port
GPIO 21 - SCL GPIO 22 - SDA GPIO 23 - INT
TB6612FNG
1N5822 <=> SS34 (3A Schottky diode)
3-Pin 5V Servos
SERVO PORTS
Voltage divider for battery charge sensing
1N581* (1N5819/1N5419) <=> SS15 (Vf=0.7V) SS12 (Vf=0.5V) (1A Schottky rectifier)
12V Input->Motor Supply
SPI Port
5V Regulated->MCU Supply
OLED PORT
MOTOR PORTS
Motor Output Pins
MOTOR DRIVER
12V-DC Power Jack
Converts 12V Input to 5V Output

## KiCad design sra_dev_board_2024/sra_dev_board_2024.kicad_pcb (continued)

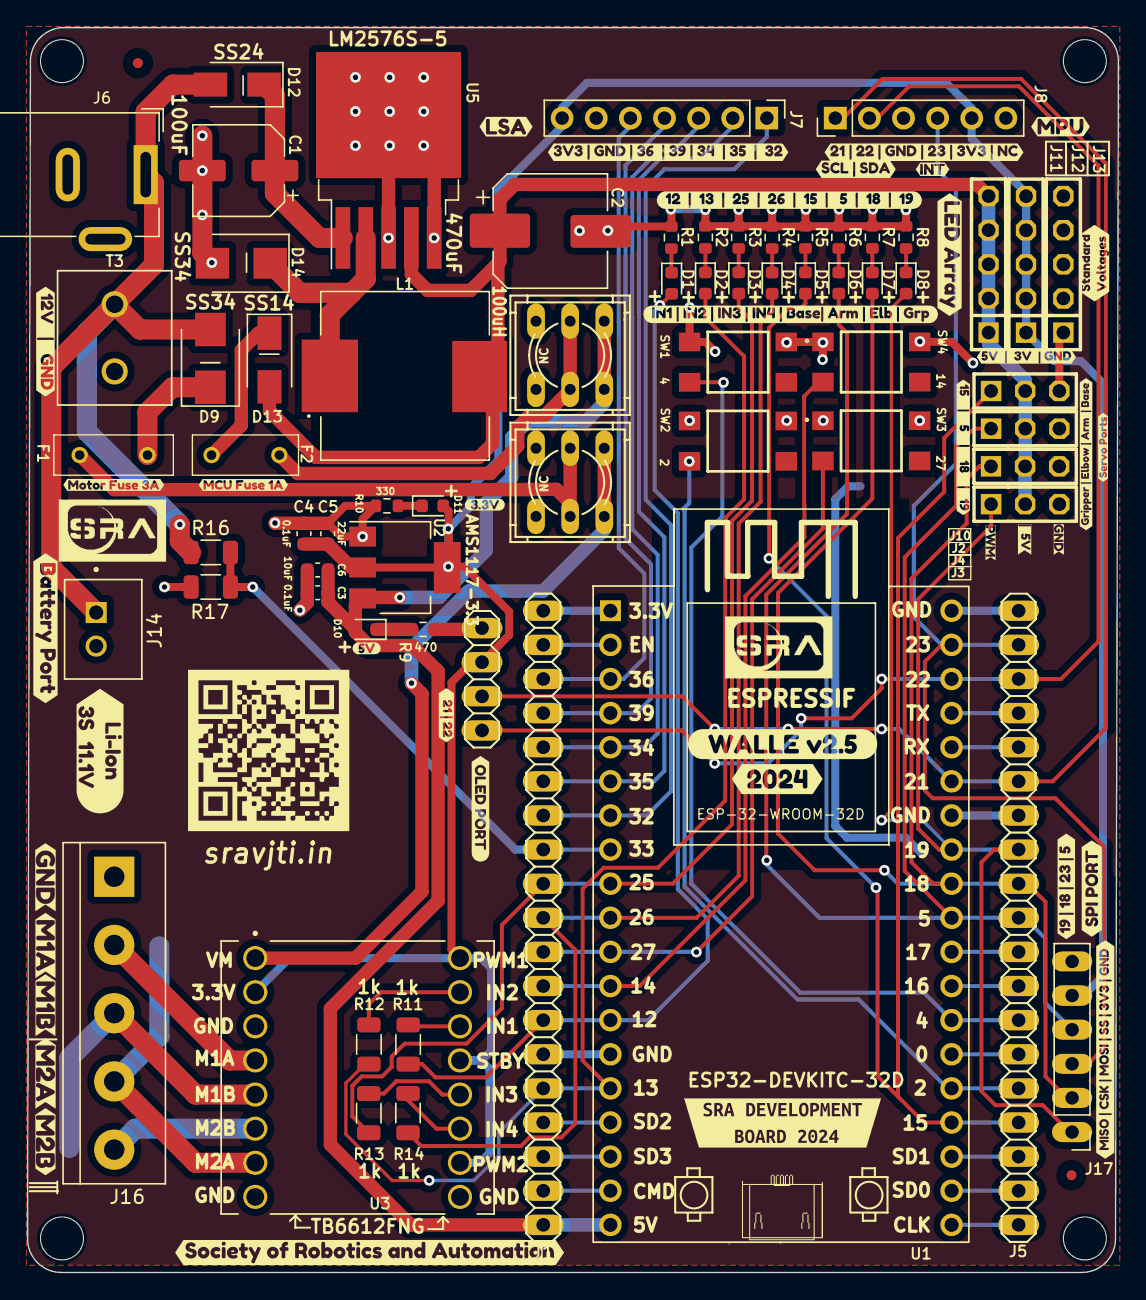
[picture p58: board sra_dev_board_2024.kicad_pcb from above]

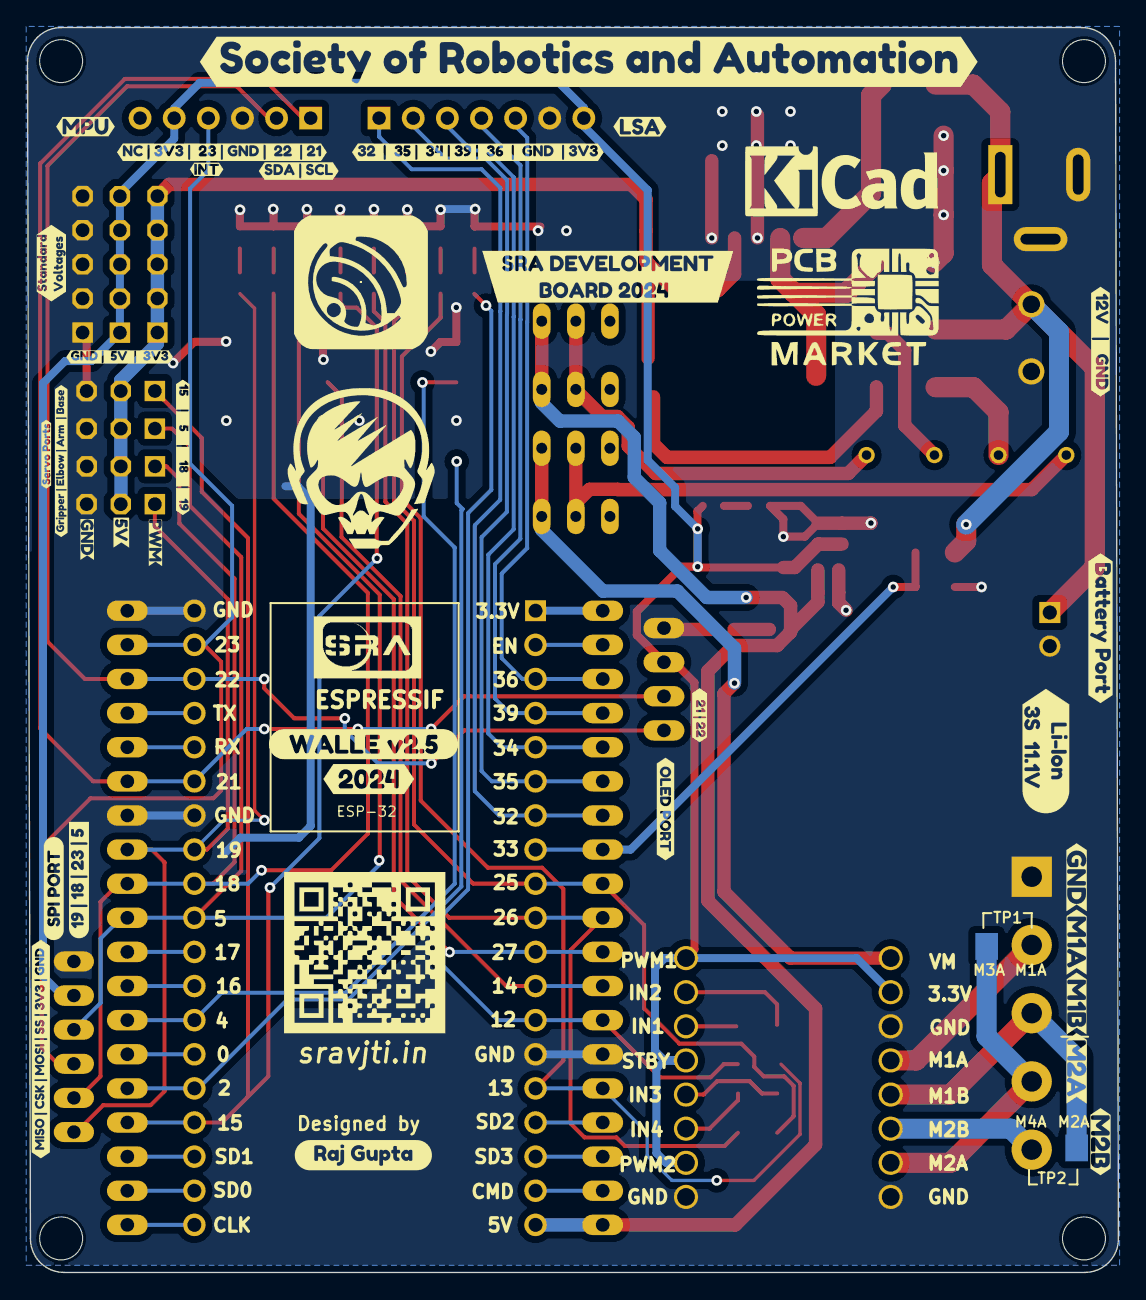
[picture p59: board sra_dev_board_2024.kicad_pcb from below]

Board: 2 copper layers, 81.2 x 92.7 mm, 142 parts (32 on the bottom side), 64 nets.

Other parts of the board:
kibuzzard-637A08DA, kibuzzard-637A08DA#2: G***; kibuzzard-637A08DA
kibuzzard-637B5F12: G***; kibuzzard-637B5F12
kibuzzard-637B5F60: G***; kibuzzard-637B5F60
kibuzzard-637B65B8: G***; kibuzzard-637B65B8
kibuzzard-658F2ACB: G***; kibuzzard-658F2ACB
kibuzzard-658F2B02: G***; kibuzzard-658F2B02
kibuzzard-658F2B2A: G***; kibuzzard-658F2B2A
kibuzzard-658F2C3C, kibuzzard-658F2C3C#2: G***; kibuzzard-658F2C3C
kibuzzard-658F2C13, kibuzzard-658F2C13#2: G***; kibuzzard-658F2C13
kibuzzard-658F2C67, kibuzzard-658F2C67#2: G***; kibuzzard-658F2C67
kibuzzard-658F2DCD: G***; kibuzzard-658F2DCD
kibuzzard-658F2DEA: G***; kibuzzard-658F2DEA
kibuzzard-658F2DF6: G***; kibuzzard-658F2DF6
kibuzzard-658F2E2C, kibuzzard-658F2E2C#2: G***; kibuzzard-658F2E2C
kibuzzard-658F2E4A, kibuzzard-658F2E4A#2: G***; kibuzzard-658F2E4A
kibuzzard-658F2E5A, kibuzzard-658F2E5A#2: G***; kibuzzard-658F2E5A
kibuzzard-658F2E6C, kibuzzard-658F2E6C#2: G***; kibuzzard-658F2E6C
kibuzzard-658F9F93, kibuzzard-658F9F93#2: G***; kibuzzard-658F9F93
kibuzzard-658F9FD8: G***; kibuzzard-658F9FD8
kibuzzard-658F289E: G***; kibuzzard-658F289E
kibuzzard-658F2903: G***; kibuzzard-658F2903
kibuzzard-658FA1D8: G***; kibuzzard-658FA1D8
kibuzzard-658FA19E: G***; kibuzzard-658FA19E
kibuzzard-658FA187, kibuzzard-658FA187#2: G***; kibuzzard-658FA187
kibuzzard-658FA201: G***; kibuzzard-658FA201
kibuzzard-6587FF3E: G***; kibuzzard-6587FF3E
kibuzzard-6587FF20: G***; kibuzzard-6587FF20
kibuzzard-6587FF29: G***; kibuzzard-6587FF29
kibuzzard-63775DBB, kibuzzard-63775DBB#2: G***; kibuzzard-63775DBB
kibuzzard-63777F1B: G***; kibuzzard-63777F1B
kibuzzard-65916C1A: G***; kibuzzard-65916C1A
kibuzzard-65916C11: G***; kibuzzard-65916C11
kibuzzard-65916C31: G***; kibuzzard-65916C31
kibuzzard-65916C76, kibuzzard-65916C76#2: G***; kibuzzard-65916C76
kibuzzard-65916D2D, kibuzzard-65916D2D#2: G***; kibuzzard-65916D2D
kibuzzard-653918A0: G***; kibuzzard-653918A0
kibuzzard-653918AE: G***; kibuzzard-653918AE
kibuzzard-653918C1: G***; kibuzzard-653918C1
kibuzzard-659161DE: G***; kibuzzard-659161DE
kibuzzard-659162C0: G***; kibuzzard-659162C0
kibuzzard-659163CD: G***; kibuzzard-659163CD
kibuzzard-659163E0: G***; kibuzzard-659163E0
kibuzzard-659164BA: G***; kibuzzard-659164BA
kibuzzard-659189BF, kibuzzard-659189BF#2: G***; kibuzzard-659189BF
kibuzzard-659189DA, kibuzzard-659189DA#2: G***; kibuzzard-659189DA
kibuzzard-6539189A: G***; kibuzzard-6539189A
kibuzzard-6591639C: G***; kibuzzard-6591639C
kibuzzard-6591649B: G***; kibuzzard-6591649B
kibuzzard-6591664B: G***; kibuzzard-6591664B
kibuzzard-6591665D: G***; kibuzzard-6591665D
kibuzzard-65916111: G***; kibuzzard-65916111
kibuzzard-65916213: G***; kibuzzard-65916213
kibuzzard-65918321: G***; kibuzzard-65918321
kibuzzard-65919040, kibuzzard-65919040#2: G***; kibuzzard-65919040

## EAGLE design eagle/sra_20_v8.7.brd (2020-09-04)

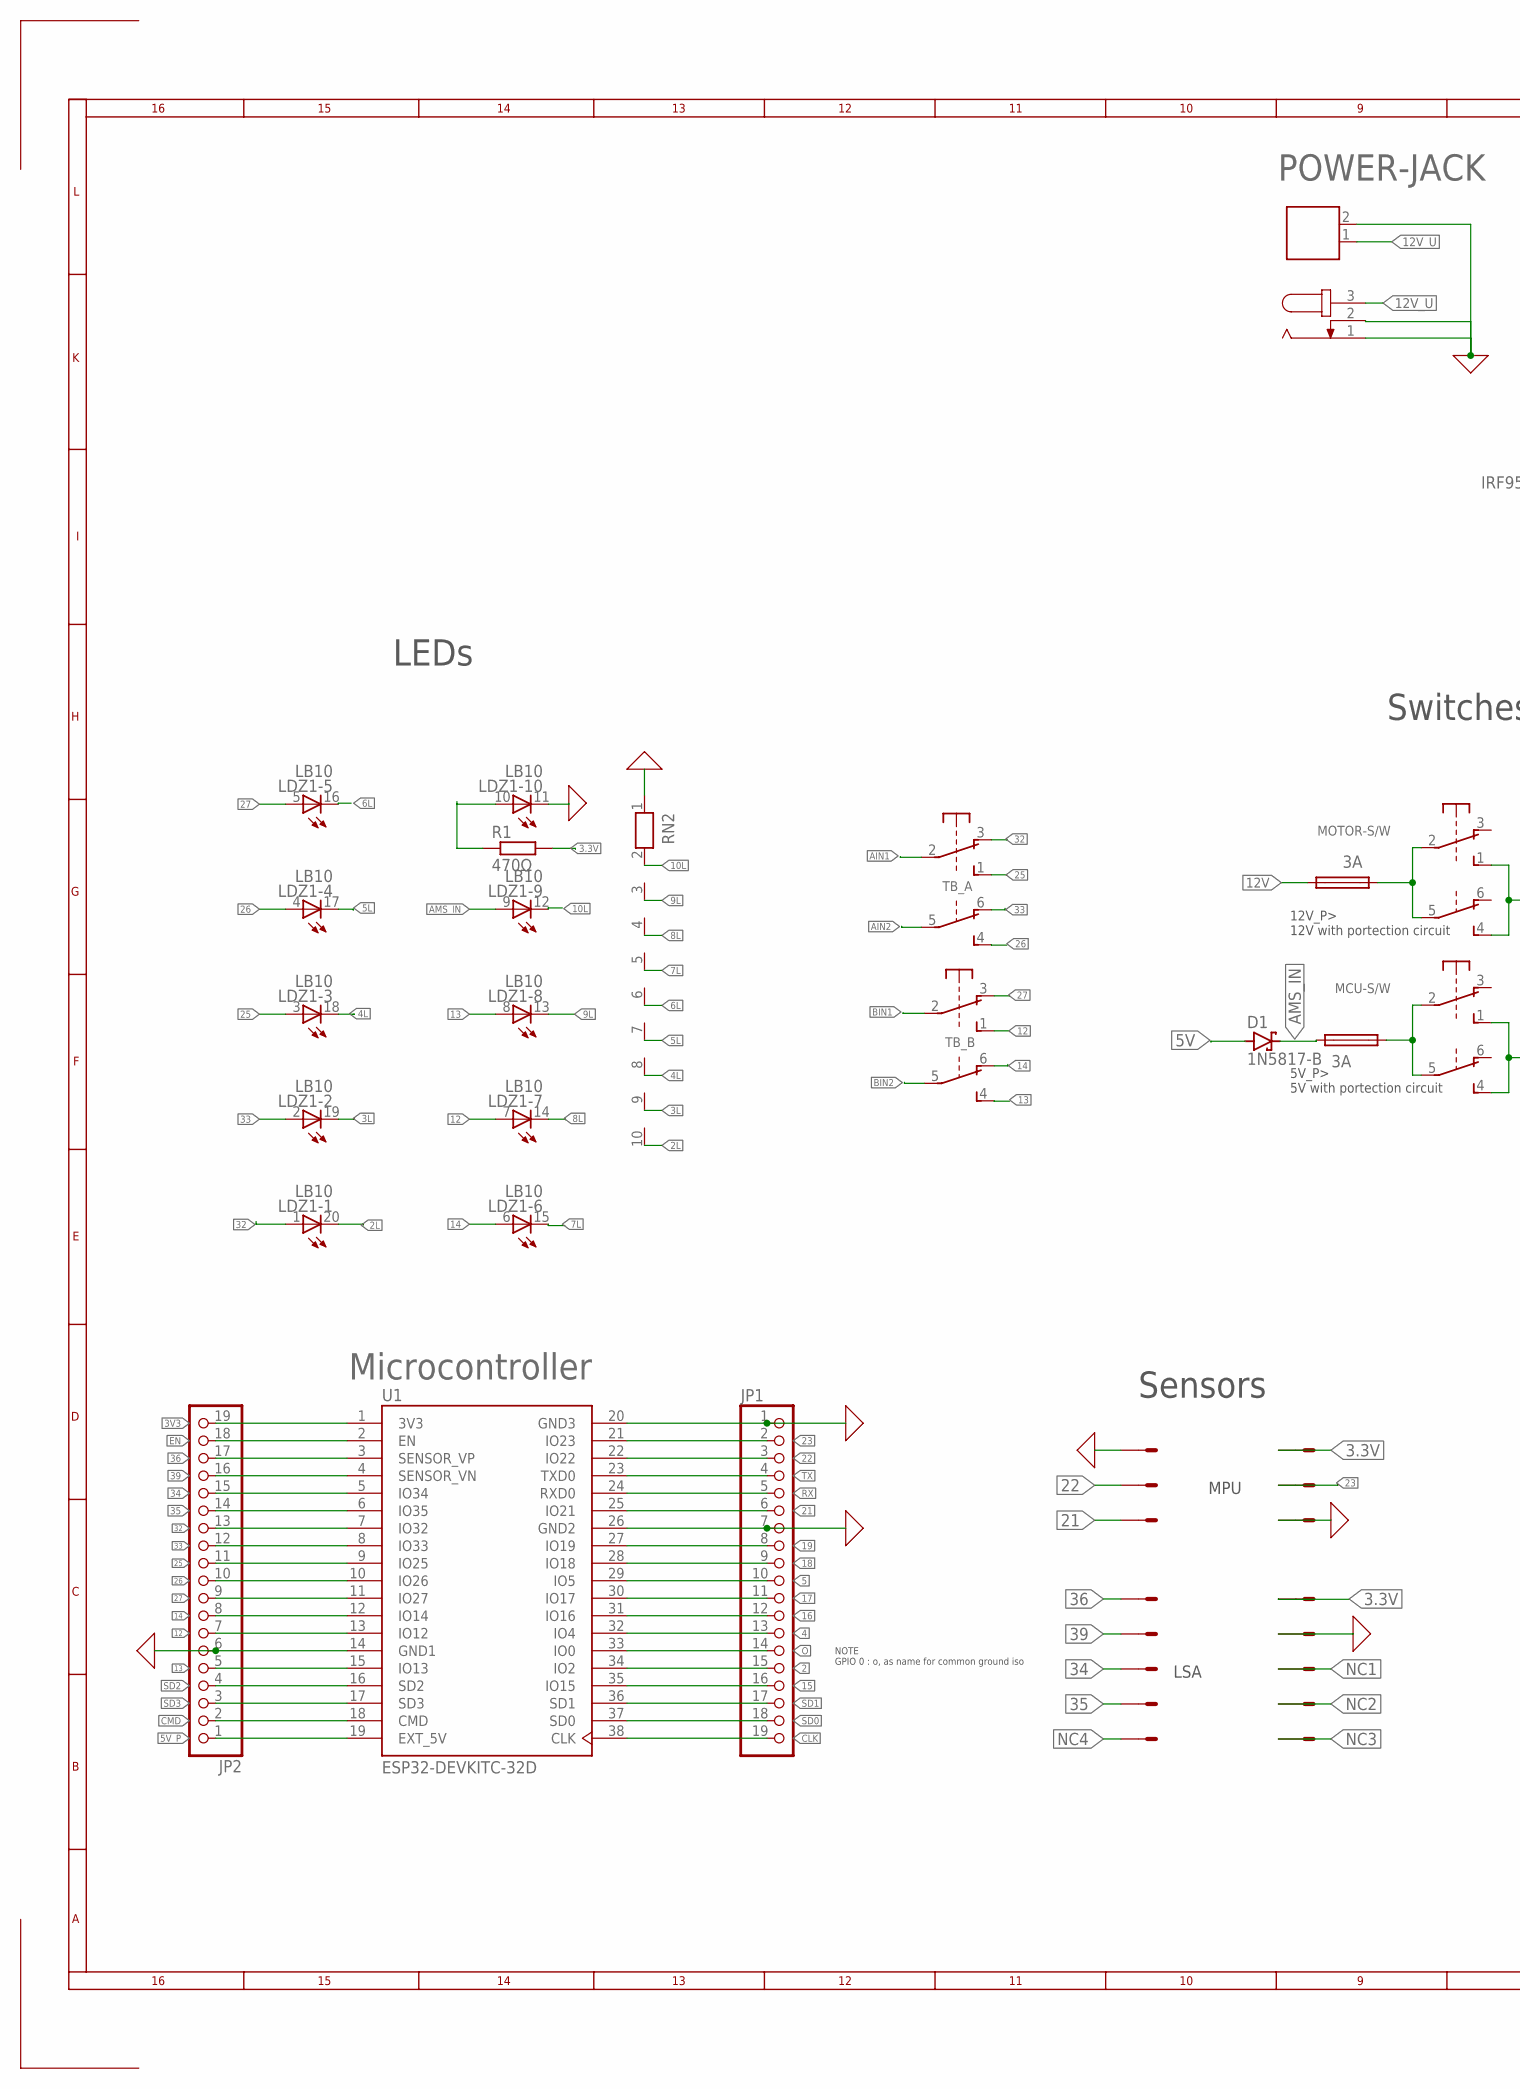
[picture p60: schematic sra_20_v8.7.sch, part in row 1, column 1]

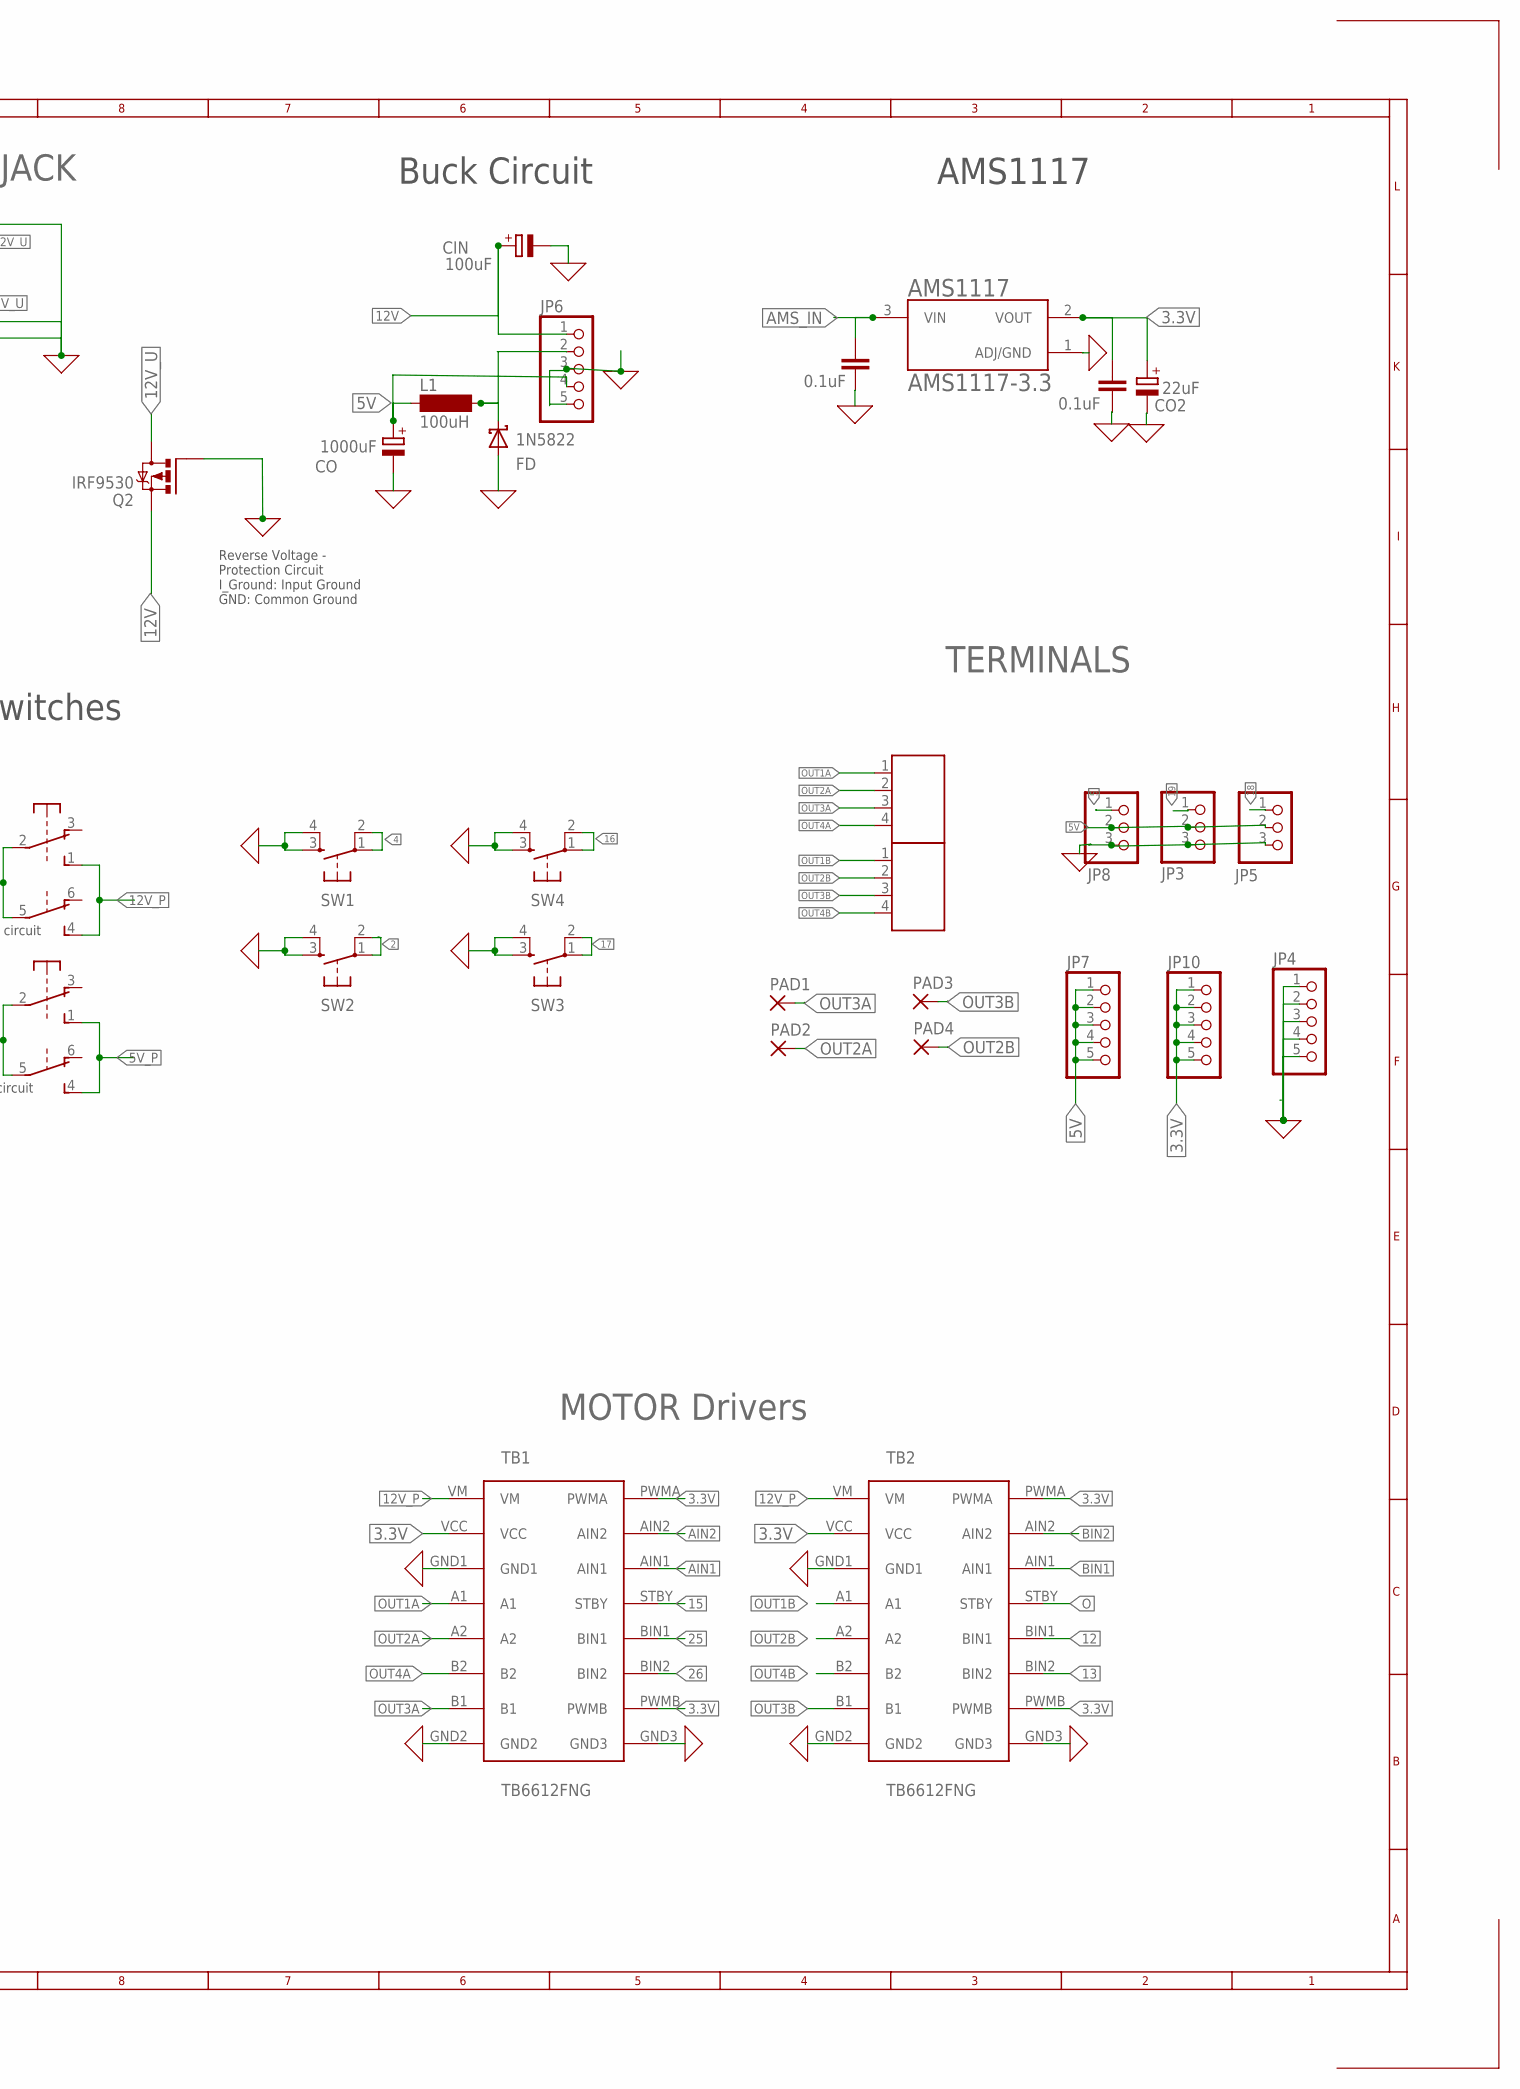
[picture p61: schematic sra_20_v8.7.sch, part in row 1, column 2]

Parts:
12V: 691131710002
AMS1117: AMS1117-3.3; SOT229P700X180-4N
CIN: 100uF; E2,5-6
CIN1: 0.1uF; C5B2.5
CO: 1000uF; E3,5-10
CO1: 0.1uF; C5B2.5
CO2: 22uF; E2,5-6
D1: 1N5817-B; DO41-7.6
F2, F3: 3A; SH25
FD: 1N5822; DIOAD2120W130L950D530P
J1, J2: 691131710004
JP1, JP2: PINHD-1X19; 1X19
JP3, JP5, JP8: PINHD-1X3; 1X03
JP4, JP6, JP7, JP10: PINHD-1X5; 1X05
L1: 100uH; SD12K100
LDZ1: LB10
LINE-SENSOR: 057-010-1
MCU-S/W: 9077-2
MOTOR-S/W: 9077-2
PAD1, PAD2, PAD3, PAD4: SMD2; SMD1,27-2,54
POWER-JACK: JACK-PLUG1; SPC4078
Q2: IRF9530; TO220BV
R1: 470Ω; 0204/7
RN2: RN09; RN-10
SW1, SW2, SW3, SW4: DTS-6
TB1, TB2: TB6612FNG
TB_A: 9077-2
TB_B: 9077-2
U1: ESP32-DEVKITC-32D; MODULE_ESP32-DEVKITC-32D
X1: 057-006-1

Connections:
0: 12V.2, AMS1117.1 (ADJ/GND), CIN.-, CIN1.1, CO.-, CO1.1, CO2.-, FD.A, JP1.1, JP1.7, JP2.6, JP3.3, JP4.1, JP4.2, JP4.3, JP4.4, JP4.5, JP5.3, JP6.3, JP6.5, JP8.3, LDZ1.11 (C), LINE-SENSOR.4, POWER-JACK.1, POWER-JACK.2, Q2.G, RN2.1, SW1.3, SW1.4, SW2.3, SW2.4, SW3.3, SW3.4, SW4.3, SW4.4, TB1.GND1, TB1.GND2, TB1.GND3, TB2.GND1, TB2.GND2, TB2.GND3, U1.14 (GND1), U1.20 (GND3), U1.26 (GND2), X1.1, X1.6
2: JP1.15, SW2.1, SW2.2, U1.34 (IO2)
2L: LDZ1.20 (C), RN2.10
3.3V: AMS1117.2 (VOUT), CO1.2, CO2.+, JP10.1, JP10.2, JP10.3, JP10.4, JP10.5, LINE-SENSOR.2, R1.2, TB1.PWMA, TB1.PWMB, TB1.VCC, TB2.PWMA, TB2.PWMB, TB2.VCC, X1.2
3L: LDZ1.19 (C), RN2.9
3V3: JP2.19, U1.1 (3V3)
4: JP1.13, SW1.1, SW1.2, U1.32 (IO4)
4L: LDZ1.18 (C), RN2.8
5: JP1.10, JP8.1, U1.29 (IO5)
5L: LDZ1.17 (C), RN2.7
5V: CO.+, D1.A, JP3.2, JP5.2, JP6.4, JP7.1, JP7.2, JP7.3, JP7.4, JP7.5, JP8.2, L1.1
5V_P: JP2.1, MCU-S/W.1 (S), MCU-S/W.4 (S), U1.19 (EXT_5V)
5_AF: F2.1, MCU-S/W.2, MCU-S/W.5
6L: LDZ1.16 (C), RN2.6
7L: LDZ1.15 (C), RN2.5
8L: LDZ1.14 (C), RN2.4
9L: LDZ1.13 (C), RN2.3
10L: LDZ1.12 (C), RN2.2
12: JP2.7, LDZ1.7 (A), TB2.BIN1, TB_B.1 (S), U1.13 (IO12)
12V: CIN.+, F3.1, JP6.1, Q2.S
12V_AF: F3.2, MOTOR-S/W.2, MOTOR-S/W.5
12V_P: MOTOR-S/W.1 (S), MOTOR-S/W.4 (S), TB1.VM, TB2.VM
12V_U: 12V.1, POWER-JACK.3, Q2.D
13: JP2.5, LDZ1.8 (A), TB2.BIN2, TB_B.4 (S), U1.15 (IO13)
14: JP2.8, LDZ1.6 (A), TB_B.6 (O), U1.12 (IO14)
15: JP1.16, TB1.STBY, U1.35 (IO15)
16: JP1.12, SW4.1, SW4.2, U1.31 (IO16)
17: JP1.11, SW3.1, SW3.2, U1.30 (IO17)
18: JP1.9, JP5.1, U1.28 (IO18)
19: JP1.8, JP3.1, U1.27 (IO19)
21: JP1.6, U1.25 (IO21), X1.5
22: JP1.3, U1.22 (IO22), X1.3
23: JP1.2, U1.21 (IO23), X1.4
25: JP2.11, LDZ1.3 (A), TB1.BIN1, TB_A.1 (S), U1.9 (IO25)
26: JP2.10, LDZ1.4 (A), TB1.BIN2, TB_A.4 (S), U1.10 (IO26)
27: JP2.9, LDZ1.5 (A), TB_B.3 (O), U1.11 (IO27)
32: JP2.13, LDZ1.1 (A), TB_A.3 (O), U1.7 (IO32)
33: JP2.12, LDZ1.2 (A), TB_A.6 (O), U1.8 (IO33)
34: JP2.15, LINE-SENSOR.5, U1.5 (IO34)
35: JP2.14, LINE-SENSOR.7, U1.6 (IO35)
36: JP2.17, LINE-SENSOR.1, U1.3 (SENSOR_VP)
39: JP2.16, LINE-SENSOR.3, U1.4 (SENSOR_VN)
AIN1: TB1.AIN1, TB_A.2
AIN2: TB1.AIN2, TB_A.5
AMS_IN: AMS1117.3 (VIN), CIN1.2, D1.C, F2.2, LDZ1.9 (A)
BIN1: TB2.AIN1, TB_B.2
BIN2: TB2.AIN2, TB_B.5
CLK: JP1.19, U1.38 (CLK)
CMD: JP2.2, U1.18 (CMD)
EN: JP2.18, U1.2 (EN)
unnamed: LDZ1.10 (A), R1.1
unnamed: FD.C, JP6.2, L1.2
NC1: LINE-SENSOR.6
NC2: LINE-SENSOR.8
NC3: LINE-SENSOR.10
NC4: LINE-SENSOR.9
O: JP1.14, TB2.STBY, U1.33 (IO0)
OUT1A: J1.1, TB1.A1
OUT1B: J2.1, TB2.A1
OUT2A: J1.2, PAD2.1, TB1.A2
OUT2B: J2.2, PAD4.1, TB2.A2
OUT3A: J1.3, PAD1.1, TB1.B1
OUT3B: J2.3, PAD3.1, TB2.B1
OUT4A: J1.4, TB1.B2
OUT4B: J2.4, TB2.B2
RX: JP1.5, U1.24 (RXD0)
SD0: JP1.18, U1.37 (SD0)
SD1: JP1.17, U1.36 (SD1)
SD2: JP2.4, U1.16 (SD2)
SD3: JP2.3, U1.17 (SD3)
TX: JP1.4, U1.23 (TXD0)

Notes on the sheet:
TERMINALS
MOTOR Drivers
Microcontroller
Reverse Voltage - Protection Circuit I_Ground: Input Ground GND: Common Ground
Buck Circuit
Switches
12V_P> 12V with portection circuit
5V_P> 5V with portection circuit
Sensors
MPU
LSA
NOTE GPIO 0 : o, as name for common ground iso
AMS1117
LEDs


Board: 2 copper layers, 81.4 x 109.8 mm, 45 parts (0 on the bottom side), 67 nets.

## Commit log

2020-09-04 README and Eagle files added
    [1N5822--3DModel-STEP-56544.STEP, 1x8.STEP, 2x3.stp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]
2020-09-05 Gerber added and README updated
    [copper_bottom.gbr, copper_top.gbr, drill_1_16.xln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]
2020-09-05 minor update
    [1N5822--3DModel-STEP-56544.STEP, 1x8.STEP, 2x3.stp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]
2020-09-05 Extra folder deleted
    [1N5822--3DModel-STEP-56544.STEP, 1x8.STEP, 2x3.stp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]
2020-09-05 foldername and filename changed
    [sra_20_v8.7.brd, sra_20_v8.7.sch]
2020-09-05 foldername changed and README updated
    [copper_bottom.gbr, copper_top.gbr, drill_1_16.xln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]
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2021-01-10 Renamed Eagle files and Added Series Resistor Between ESP and Motor Driver
    [sra_board_2020.brd, sra_board_2020.sch]
2021-01-11 Change the placement of Series Resistors and cleaned the routing
    [sra_board_2020.brd, sra_board_2020.sch]
2021-01-16 Mosfet Replaced by two individual Diodes
    [sra_board_2020.brd, sra_board_2020.sch]
2021-01-23 Front and back silkscreen improved
    [sra_board_2020.brd, sra_board_2020.sch]
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2021-01-23 Gerber File added and readme updated
    [copper_bottom.gbr, copper_top.gbr, drill_1_16.xln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]
2022-01-08 Sensor eagle and kicad files added
    [MPU_2020.brd, MPU_2020.kicad_pcb, MPU_2020.kicad_sch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]
2022-01-23 SRA Board 2022: Porting to Kicad 6.0 (#4)
    * Imported SRA 2020 board eagle -> Kicad6, organised structure, footprint libs
    * Updated year in README.md
    [MPU_2020.brd, MPU_2020.kicad_pcb, MPU_2020.kicad_sch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]
2022-01-23 Corrected Schematics for KiCad 6
    [sra_board_2022.kicad_sch]
2022-01-30 Added project files for fresh 2022 SRA Dev Board
    [12V_1x02_tht.step, 1N5822.STEP, CDRH104R_inductor_smd.stp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]
2022-01-31 Finalised SRA Dev Board 2022 Design, added gerbers, renders, assets
    [RUEF160.stl, RUEF160.stp, RXEF050.stl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]
2022-01-31 Updated gerbers, board image assets
    [sra_dev_board_2022.kicad_pcb]
2022-01-31 Added Interactive BOM, SMT pick place files
    [sra_dev_board_2022-B_Cu.gbr, sra_dev_board_2022-B_Mask.gbr, sra_dev_board_2022-B_Paste.gbr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]
2022-02-01 fixed untracked files
    [mpu.kicad_pcb, mpu.kicad_sch]
2022-02-01 Added PCB files for LSA and MPU 2022
    [lsa-B_Cu.gbr, lsa-B_Mask.gbr, lsa-B_Paste.gbr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]
2022-02-01 First prototype gerber files added, fixed project structure, kicad files
    [MPU_2020.brd, MPU_2020.kicad_pcb, MPU_2020.kicad_sch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]
2022-02-08 Updated SRA-board images, updated the 3d view image in assets fiolder under documentation folder & added LSA and MPU folder under documentationn/images
2022-02-08 Connection of MPU6050 with SRA Board
    Added image of MPU6050 connection with SRA Board
2022-02-09 Added cad, step and .wrl files for lsa, mpu and sra_board under 3d_model folder
    [lsa.step, mpu.step]
2022-02-09 Removed the other_components_model folder under 3d_models And renamed the sra_board_images.md to README.md
    [1N5822--3DModel-STEP-56544.STEP, 1x8.STEP, 2x3.stp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]
2022-03-06 SRA Board, MPU, LSA Kicad, Gerber files updated
    [lsa-B_Cu.gbr, lsa-B_Mask.gbr, lsa-B_Paste.gbr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]
2022-08-28 Update README.md Add renders, datasheets, documentation
    [lsa.kicad_pcb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]
2022-11-10 Add footprint and symbol for DRV8825 and update schematic
    [DRV8825_STEPPER_MOTOR_DRIVER_CARRIER.step, sra_dev_board_2022.kicad_sch]
2022-11-10 Modify routing according to new schematic
    [sra_dev_board_2022.kicad_pcb, sra_dev_board_2022.kicad_sch]
2022-11-10 modify silkscreen
    [sra_dev_board_2022.kicad_pcb]
2022-11-11 add TCRT-5000 base structure to LSA
    [TCRT5000.step, lsa.kicad_pcb, lsa.kicad_sch]
2022-11-13 Update PCBs for Wall-E 2023
    Additions:
    1. Add new LSA
    2. Add new fabrication outputs for SRA board and LSA.
    3. Add terminal block for ground connection for shielding.
    Modifications:
    1. Modify MCU switch placement.
    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
    [12V_1x02_tht.step, 1N5822.STEP, CDRH104R_inductor_smd.stp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]
2022-11-20 Updated gerbers for LSA and SRA-Board
    [lsa-B_Cu.gbr, lsa-B_Mask.gbr, lsa-B_Paste.gbr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]
2022-11-22 Updated working content for sra_dev_board_2023
    [lsa-2023.step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]
2022-11-22 updated BoM for sra_board_2023
    [sra_dev_board_2022.csv, sra_dev_board_2023.csv]
2022-11-22 Add 3D model for TCRT5000
    [lsa.kicad_pcb]
2022-11-22 Tweaks in routing prototype-1
    [lsa.kicad_pcb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]
2022-11-23 Add updated 3d renders for sra-dev-board-2023
    [sra_dev_board_2023-top-pos.csv]
2022-12-10 Resolve LSA wiring problem and fixed silkscreen, updated gerbers, fabrication outputs and 3D files for LSA
    [lsa-2023.step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]
2022-12-15 Update LSA and SRA board after hardware testing
    [A4988_STEPPER_MOTOR_DRIVER_CARRIER.step, DRV8825_STEPPER_MOTOR_DRIVER_CARRIER.step, lsa-2023.step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]
2023-01-09 Update repo with recent changes
    [lsa-B_Cu.gbr, lsa-B_Mask.gbr, lsa-B_Paste.gbr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]
2023-01-11 Modify relative path for TCRT5000 footprint
    [TCRT5000.step, lsa.kicad_pcb, lsa.kicad_sch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]
2023-03-30 Updates to README for SRA BOARD 2023 (#25)
    * added pinout diagrams for mpu,lsa and sra boards
    * changed README to include pinout images and made changes to README with latest changes
    * fixed README to show images
    * Minor changes to README for new SRA BOARD, added new images
    * minor changes
2023-03-30 Add current limiting resistor for MPU (#26)
    * Add current limiting resistor on Interrupt line for MPU
    * Update gerbers, placement files and BoM
    [sra_dev_board_2023-B_Cu.gbr, sra_dev_board_2023-B_Mask.gbr, sra_dev_board_2023-B_Paste.gbr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]
2024-05-10 SRA Board 2023-24 Updated
    [12V_1x02_tht.step, 1N5822.STEP, A4988_STEPPER_MOTOR_DRIVER_CARRIER.step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]
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2024-05-14 SRA Board 23-24 Updated
    [lsa-2023-24.step, mpu-2023-24.step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]
2025-04-10 Fixes: addressed PR review comments
    [12V_1x02_tht.step, 1N5822.STEP, A4988_STEPPER_MOTOR_DRIVER_CARRIER.step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]
2025-06-25 Revert "Updated Readme and assets for SRA board 2024-25"
2025-06-25 Update the assets and readme as per SRA Board 2024-25 (#33)
2026-03-14 Update for the SRA Board 2025-26 (#34)
    * SRA Board 2025-26 Update
    * readme update for 2025-26 SRA Board
    [12V_1x02_tht.step, 1N5822.STEP, B2B-XH-A_LF__SN_.step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]

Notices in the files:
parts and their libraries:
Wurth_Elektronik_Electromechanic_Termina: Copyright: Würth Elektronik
